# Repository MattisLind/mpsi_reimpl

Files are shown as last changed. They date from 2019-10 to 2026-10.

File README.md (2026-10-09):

# MPSI Rev2

A new HP 9830 interface based on
[Brent Hilpert's MPSI](https://madrona.ca/e/HP9830/mpsi/index.html): a 5 V ATF1504AS
CPLD handles the bus, and an STM32F103CB serves files from a microSD card.
Two 74HCT165s capture input, separate SPI buses serve the HP link and SD,
and an SSD1306 OLED with up/down/select buttons controls operation.

MPSI Server handles paper tape, printer capture and Fast Mode cassette emulation.
Tape Controller uses an HP-resident MTAPE proxy to read/write the physical drive.
USB MSC takes exclusive ownership of SD and releases every HP output.
See [the tape analysis](requirements/07_tape_analysis.md).

The current draft includes:

- [VHDL RTL, handshake bench and container build flow](hardware/rev2/README.md).
- [STM32/CPLD package pins and tentative placement](requirements/08_pin_mapping.md).
- [Three-sheet KiCad schematic and unrouted placement](hardware/rev2/kicad/README.md),
  with the existing HP connector, USB-C protection and PA9/PA10 debug header.
- [Portable C firmware core](firmware/rev2/README.md).

Start with [requirements](requirements/README.md) and [open issues](open_issues.md).

```sh
make test
```

Requires make, a C11 compiler and either GHDL or the documented Docker image.
Tests cover bus handshakes, five interrupt choices, GP-only Controller decoding,
direct configuration updates, unbuffered data, CS-clocked flags, input capture, tape commands
and exclusive SD/MSC ownership.

The simplified ATF1504 design fits and generates JEDEC with all 29 requested pins,
JTAG and fourteen open-collector HP outputs. RTL and fitter-emitted functional
equations each pass 2,000 checks at 9, 18 and 24 MHz SPI. These are zero-delay
tests; the F103 is specified up to 18 MHz, and 9 MHz is the provisional board rate.
This remains a design draft. Timing, fitter-report accounting, electrical current/rail and power-up validation, PCB routing,
and Arduino SD/USB/UI/Controller drivers also remain open. The STM32 pin map uses
PB14/PB10 as direct 5 V tolerant inputs, subject to supply/reset constraints.

Previous files remain in `MPSIBOARD`, `hardware/pld` and `software`.
The original README is preserved in [docs/legacy_design.md](docs/legacy_design.md).

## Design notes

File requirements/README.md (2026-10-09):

# Rev2 requirements

Started 2026-10-08. This directory is the working specification for a new design;
the existing board, CUPL, Xilinx and Raspberry Pi software are historical material.
Requirement IDs remain stable as the design develops. Proposed choices can change;
unresolved decisions belong in [open_issues.md](../open_issues.md).

| Document | Contents |
| --- | --- |
| [00_sources.md](00_sources.md) | Source provenance and what has actually been established |
| [01_system.md](01_system.md) | Scope, requirements and acceptance criteria |
| [02_hardware.md](02_hardware.md) | Block diagram, electrical design, preliminary connections |
| [03_interface.md](03_interface.md) | HP bus semantics and MCU/CPLD SPI contract |
| [04_firmware.md](04_firmware.md) | SD ownership, cassette engine, UI and board integration |
| [05_verification.md](05_verification.md) | Running the tests and remaining physical validation |
| [06_existing_connector.md](06_existing_connector.md) | Existing KiCad J1 pad/net assignments, sides and geometry |
| [07_tape_analysis.md](07_tape_analysis.md) | Server/Controller roles, per-file headers, supplied images and HP BOF versus TAP file marks |
| [08_pin_mapping.md](08_pin_mapping.md) | MCU/CPLD package pins, FT input constraints, debug/USB circuit and tentative placement |

The current implementation is a VHDL functional prototype with a three-sheet
KiCad draft and unrouted placement. The simplified CPLD fits with fixed pins and
generates JEDEC; RTL and fitter-emitted functional equations pass the handshake
bench. Timing, fitter-report accounting, electrical and PCB sign-off and STM32
target firmware remain open.

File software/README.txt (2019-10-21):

pgm9830 README		2014 May / bhilpert
===========================================

The pgm9830 file structure includes the source to produce 3 executables and 1 tape image file:

	tp9830		- Tape image manipulation and control for the 9830 internal tape drive
			  via the MPSI I/O server.
			  For use, see help command when running, or tp9830/helpdoc.txt.

	tp9865		- Tape image manipulation and control for the 9865 tape drive
			  via the 9865 I/O adapter.
			  For use, see help command when running, or tp9830/helpdoc.txt.

	mpsiServer	- cassette-tape/printer/paper-tape-reader server for use with
			  MPSI I/O device.
			  For use, see comment in mpsiServer/main.c

	machine.t98	- A tape image with the machine support binary block
			  and blockscan BASIC program.

Subdirectories:
	tp9830		- source for the tp9830 & tp9865 programs.

	mpsiServer	- source for the mpsiServer program.

	util		- source for a few C utility modules.

	machine		- source and tape files to produce the machine.t98 tape image.

These sources are currently targeted primarily for compilation on an RPi, although the tp9830/65 programs
may be compiled on other suitable unix systems using:
	'make mode=standalone'
to produce a program without the tape control but still provides for tape image manipulation.

The machine.t98 may also be produced on other unix systems. Assembly requires the asm9830 assembler.

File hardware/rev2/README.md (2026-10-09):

# Rev2 CPLD and board draft

[rtl/mpsi_cpld.vhdl](rtl/mpsi_cpld.vhdl) is the authoritative VHDL-2008 RTL.
[tb/tb_mpsi.vhdl](tb/tb_mpsi.vhdl) exercises General/Fast Mode, interrupt gating,
Controller decoder selection, direct SPI updates, CS flag strobes, input capture and MSC release.
[tb/hct165_pair.vhdl](tb/hct165_pair.vhdl) models the two external input registers.
The bench passes 2,000 checks at each of 9, 18 and 24 MHz SPI, with a 24 MHz,
one-third-duty-cycle capture clock. Only 9 MHz is the provisional board setting;
24 MHz exceeds the STM32F103's specified SPI limit. See issue 028.

The [pin map](../../requirements/08_pin_mapping.md) describes both packages,
direct STM32 FT inputs, USART1 debug header and tentative placement.
[kicad/MPSI_REV2.kicad_pro](kicad/MPSI_REV2.kicad_pro) opens the three-sheet
schematic and unrouted board. The local libraries preserve the existing HP
connector and the paper-tape project's USB-C footprint.

Read [the interface contract](../../requirements/03_interface.md) before writing
a driver. Configuration shifts directly with CFG_FRAME high, which blanks HP
service; it needs no COMMIT. STM32 SPI supplies sixteen clocks, without hardware
length checking. Data/status drive the HP gates directly. CS low clears REQUEST_n
and inhibits HCT165 loading; CS rising loads ACK/CFI/SSI after the data settles.
There is no separate COMMIT, output latch bank, unread-word lock or overrun monitor.
Firmware updates only during the HP handshake's safe interval and queues every
qualified received request. Address zero
disables the corresponding decoder; Controller GP8/TP-off uses word 0x0608.

Run from the project root:

```sh
git submodule update --init --recursive
python3 scripts/rev2_hdl.py build-image
make test
python3 scripts/rev2_hdl.py fit
python3 scripts/rev2_hdl.py postfit
```

The private SSH tool submodule is now at the intended path
`hardware/rev2/rtl/atf15xx-yosys-docker`, pinned to
`95e46e5f11254cc865614a9dc12fddb522a32f55`.
Its previously nested location has been corrected with `git mv`; commit the
staged `.gitmodules` and gitlink move together with the desired project changes.
No commit has been made here. Another checkout needs SSH access to the private
repository.

If local GHDL is installed, `make test` uses it. Otherwise it uses Docker. A
smaller simulation-only image is available with
`python3 scripts/rev2_hdl.py build-sim-image`; this is used when the full image
has not been built. Docker commands run without interactive terminal flags.
The wrapper locates Docker Desktop on macOS when its CLI is absent from PATH.

The synthesis flow retains DECPROMEM's inline `--PIN:` constraints. Four JTAG
constraints are included because the fitter writes them back into its pin file.
`-preassign keep` prevents silent reassignment. All fourteen HP pins are configured
open collector, pin keepers are off, and JTAG remains on. A build-local liberty
copy corrects the upstream TRI enable-name mismatch (`EN` versus Atmel's `ENA`);
the tool submodule is unchanged. `check -assert` rejects broken synthesized nets.

**The simplified implementation fits ATF1504 and generates JEDEC.** It has 36
register bits: data shift 16, configuration 12, flags 3, request synchronization 3
and capture pulse control 2. All 29 logical pins are retained; CS uses global
clock pin 41, formerly COMMIT. PB0/PB11 and CPLD pins 34/39/40 are now spare.
ATF1502 has only
32 registers and cannot hold this version either.

Logs, EDIF, JEDEC and the fitter's VHO/SDF go to `build/rev2/vhdl/fit`; RTL waveforms
go to `build/rev2/vhdl/mpsi-{rate}.vcd`. Stale fitted outputs are removed before synthesis, and
a successful fit must pass the package-pin check before being accepted.
`postfit` translates the fitter-emitted gates/flip-flops into functional VHDL and
runs the same bench: all 2,000 checks pass at each rate. It does not substitute RTL,
apply the SDF, prove timing or independently decode JEDEC fuses. The translation
rejects unsupported primitive types and checks the register count.

The fitter declares a fit but reports inconsistent resource totals (65/64
macrocells and Block D 17/16); issue 029 records this for review. Functional
fitted-equation tests pass, but report/fuse verification and physical
timing/current/rail validation remain before hardware sign-off.

For fitter-strategy iterations, use `python3 scripts/rev2_hdl.py fit --fit-options='...'`.
Requested package pins are still checked before accepting an image.

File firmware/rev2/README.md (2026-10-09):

# Rev2 portable firmware core

```sh
make -C firmware/rev2 test
```

`mpsi_protocol.h` defines the SPI payload and captured request layout.
`mpsi_storage.c` implements FAT/MSC ownership and General Mode file-byte operations.
`mpsi_tape.c` implements the initial cassette-command engine against a bounded
random-access cell cache interface.

These are server functions. The distinct Tape Controller application, using the
HP-resident MTAPE proxy for physical cassette access, is specified in
[the tape analysis](../../requirements/07_tape_analysis.md) and is not implemented yet.

See [the integration contract](../../requirements/04_firmware.md). Callbacks have
a host-test implementation only. There is no flashable Arduino STM32 image,
SdFat driver, USB stack, input queue, OLED driver, TAP backend or image converter
in this delivery.
Supply every required callback before init and serialize calls as specified.
A FAULT needs explicit board recovery; do not reinitialize while USB owns the card.

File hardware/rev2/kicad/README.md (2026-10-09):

# KiCad draft

Open [MPSI_REV2.kicad_pro](MPSI_REV2.kicad_pro) in KiCad 10.

The root sheet contains the copied HP connector, ATF1504AS-10JU44, two 74HCT165s,
JTAG and reset/control pulls. The MCU sheet contains STM32F103CBT6, microSD with
card detection, OLED/buttons, USART1 debug, SWD, boot jumper and 8 MHz crystal.
The USB/power sheet copies the paper-tape project's USB-C/USBLC6 circuit and
Schottky source isolation, with TLV75533 3.3 V regulation.

The 64-footprint board is an **unrouted placement draft**. Its HP connector and
Edge.Cuts use the current legacy board. All fifty connector pad positions,
sizes, angles and layers are checked against that board when regenerated.
The CPLD and HCT165s sit beside the HP edge connector; MCU is to their right,
with SD/UI/debug/USB towards the other edges. Mechanical fit and routing remain
to be reviewed. The simplified CPLD fits with the requested package pins, including
CS moved to GCLK3 pin 41. COMMIT/overrun wiring is removed; PB0/PB11 and CPLD
34/39/40 are spare. Electrical/timing validation and routing remain open.

The project embeds symbols and supplies portable `Rev2.kicad_sym` and
`Rev2.pretty` libraries. The connector library is extracted from
`MPSIBOARD/MPSIBOARD.kicad_pcb`; board-file pad angles are normalized to library
angles without changing pad geometry. USB-C symbol/footprint and circuit values
come from [the paper-tape project](https://github.com/MattisLind/hp21xx_papertape_emulator/tree/06787ada3dd411305c0451a057edc152249f1b82/kicad/hp21xx_papertape_emulator).
Original projects are untouched.

The schematic generator uses installed KiCad symbol libraries and local copies
of that reference schematic/PCB. Its `--reference`, `--reference-pcb` and
`--symbols` arguments allow overriding the defaults. The saved KiCad project
does not depend on those source files being installed.

```sh
python3 scripts/generate_rev2_schematic.py
kicad-cli sch export netlist --output /tmp/mpsi-rev2.net hardware/rev2/kicad/MPSI_REV2.kicad_sch
python3 scripts/check_rev2_pins.py --netlist /tmp/mpsi-rev2.net
```

For the placement generator use KiCad's bundled Python with its `pcbnew` module;
it consumes the above netlist, including explicit unconnected pin nets. On macOS:

```sh
/Applications/KiCad/KiCad.app/Contents/Frameworks/Python.framework/Versions/3.9/bin/python3.9 scripts/generate_rev2_placement.py
```

`components.json` records the schematic components/UUID paths used by that
generator; `pinmap.json` in the parent directory is the package-pin contract.
Generators overwrite these draft files, so update generator source alongside
manual schematic changes if regeneration is needed.

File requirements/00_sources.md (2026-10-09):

# Sources and evidence

Reviewed 2026-10-08; package pins, USB circuit and VHDL tools updated 2026-10-09. No numerical HP bus timing limits are inferred from the test
bench. Simulation delays are engineering assumptions pending measurement.

| ID | Source | Use |
| --- | --- | --- |
| S01 | [Brent Hilpert: MPSI](https://madrona.ca/e/HP9830/mpsi/index.html#technical) | Device selection, serial registers, status/data gating and flag resets |
| S02 | [HP 9830 machine architecture](https://madrona.ca/e/HP9830/machine.html#sc) | General Mode (the requested standard mode) and Fast Mode transaction sequences |
| S03 | [MPSI schematic, revision 1.2](https://madrona.ca/e/HP9830/mpsi/mpsiSchematic.pdf) | Capture monostable, open-collector outputs, ACK correction and original connector |
| S04 | [HP 9830 hardware architecture](https://madrona.ca/e/HP9830/hardware.html) | 8 MHz MCK and physical tape/control-byte model |
| S05 | [HP 9830 redrawn schematic](https://madrona.ca/e/HP9830/hp9830Schematic.pdf) | F3, PDF page 19: DI/SI/CFI/SSI pull-ups; F2: register and CEO logic |
| S06 | [ATF1504AS(L) datasheet, 0950P, March 2014](https://ww1.microchip.com/downloads/en/DeviceDoc/Atmel-0950-CPLD-ATF1504AS(L)-Datasheet.pdf) | Open-collector option, 64 macrocells, clock resources, DC and package constraints |
| S07 | [Microchip ATF1502AS](https://www.microchip.com/en-us/product/ATF1502AS) | 5 V, 32-macrocell alternative |
| S08 | [ST STM32F103x8/xB datasheet, DS5319](https://www.st.com/resource/en/datasheet/stm32f103c8.pdf) | Rev 20, July 2025: LQFP48 pins, FT inputs, pull restrictions and supply-dependent voltage limits; PB14 SPI2 MISO is FT and is used for HP; PA6 is not FT and is used for 3.3 V SD |
| S09 | [Nexperia 74HC/HCT165, revision 8](https://assets.nexperia.com/documents/data-sheet/74HC_HCT165.pdf) | HCT thresholds, asynchronous parallel load and shift clock |
| S10 | [TI SN74LVC1G125](https://www.ti.com/product/SN74LVC1G125) | Earlier input-translator candidate, superseded by tentative direct FT inputs; retain as a fallback if issue 026 requires isolation |
| S11 | [Existing server](../software/mpsiServer/tp.c), [paper tape](../software/mpsiServer/ptr.c), [tape format](../software/tp9830/tpf.c) | Repository copy of Hilpert's published support software; cassette commands and empirical timing caveats |
| S12 | Tony Duell's HP 9830 schematic, as reported by the user on 2026-10-08; drawing/page reference not supplied | 1 kOhm pull-ups on DI, SI, CFI and SSI; accepted design input |
| S13 | [ST RM0008 reference manual](https://www.st.com/resource/en/reference_manual/cd00171190-stm32f101xx-stm32f102xx-stm32f103xx-stm32f105xx-and-stm32f107xx-advanced-arm-based-32Bit-mcus-stmicroelect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) | Section 7.2.10 MCO choices and chapter 14 TIM1 PWM/counter configuration |
| S14 | [DECPROMEM VHDL build notes](https://github.com/MattisLind/DECPROMEM/blob/63c2cc10e1795c9c593e9b0065bb4efebdc5d622/vhdl/README.md); local atf15xx-yosys-docker checkout under /Users/mattis_lind/DECPROMEM/vhdl | Inline --PIN convention and GHDL/Yosys/Atmel-fitter flow; selected tool container now built/executed under S21 |
| S15 | [HP21xx firmware](https://github.com/MattisLind/hp21xx_papertape_emulator/blob/06787ada3dd411305c0451a057edc152249f1b82/src/hp21xx_papertape_emulator/hp21xx_papertape_emulator.ino), [README](https://github.com/MattisLind/hp21xx_papertape_emulator/blob/06787ada3dd411305c0451a057edc152249f1b82/README.md), [schematic](https://github.com/MattisLind/hp21xx_papertape_emulator/blob/06787ada3dd411305c0451a057edc152249f1b82/kicad/hp21xx_papertape_emulator/hp21xx_papertape_emulator.kicad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) | Arduino_Core_STM32/SdFat/TinyUSB/UI reference; exact USB-C symbol/footprint, USBLC6-2SC6, 22 Ohm/CC/pull-up/VBUS-divider circuit and diode/regulator source reused; reference firmware not built |
| S16 | [SIMH magtape representation](https://simh.trailing-edge.com/docs/simh_magtape.pdf), Bob Supnik, 2022-01-17 | TAP record lengths, padding, trailer, tape marks and standard/extended distinction |
| S17 | [Existing KiCad PCB](../MPSIBOARD/MPSIBOARD.kicad_pcb), [current schematic](../MPSIBOARD/MPSIBOARD.kicad_sch) | J1 embedded pad/net assignments, sides, pitch and outline; extracted in 06_existing_connector.md |
| S18 | [Hilpert's XNS format](https://madrona.ca/e/xns.html), [local image decoder](../software/util/util.c), [local tape server](../software/mpsiServer/tp.c) | Confirm that the supplied .t98/server path uses XNS and preserves control-marked cells |
| S19 | [Published support archive](https://madrona.ca/e/HP9830/pgm9830.tgz), downloaded 2026-10-08; digest in 07_tape_analysis.md | Contains one .t98 and two substantive .f98 images; all three and five inspected source/documentation files match the local copies |
| S20 | [Tape controller reader/writer](../software/tp9830/t98_mpsi.c), [format routines](../software/tp9830/tpf.c), [format offsets](../software/tp9830/tpf.h), [MTAPE proxy](../software/machine/mbb.s), [user documentation](../software/tp9830/helpdoc.txt) | Physical capture loses BOF control flags; buffered writer segments, GP directives, checksums and EOT-placeholder convention |
| S21 | [User's private atf15xx-yosys-docker repository](https://github.com/MattisLind/atf15xx-yosys-docker), selected 2026-10-09 | SSH submodule at the corrected path, pinned to 95e46e5f11254cc865614a9dc12fddb522a32f55. Built container synthesizes/fits the simplified 36-register design, retains 29 pins/JTAG/open-collector outputs and generates JEDEC. RTL and fitter-emitted functional equations pass 2,000 checks per SPI rate at 9/18/24 MHz; timing/fuse validation and report accounting remain open |

S05 is a reverse-engineered drawing, not HP's manufacturer schematic. Its F3
sheet shows fourteen pull-ups for twelve input bits plus CFI and SSI, but the
resistance text is just `K`. The user's S12 information establishes 1 kOhm for
all DI/SI/CFI/SSI lines; use that value for the design. Full receiver/capacitive
loads remain electrical verification work in issue 002. The unrelated 2.2 kOhm
resistors are not the evidence.

S06's DC table (PDF page 11) specifies VOL <= 0.45 V at IOL = 12 mA. The user's
24 mA assumption is therefore unverified for this part. Neither an absolute
maximum nor an AC drive-current plot establishes a guaranteed DC sink rating.
Recheck the current datasheet of the exact ordered variant before sign-off.

S01 and S03 inform the bus logic; S02 supplies transaction-level stimulus. S11
supports the initial tape-command core, including commands 6/7 as continuation.
The unusual read-forward delay in that implementation is an empirical observation,
not a bus specification and not yet implemented in the new firmware.

The user identified five interrupt choices in S03: nDI0, nDI7, nSI0, nSI1 and nSI2.
This supersedes the first draft's provisional eight-line lookup. VHDL and the portable configuration helper now implement those five lines;
the bench verifies reserved-code silence and reference status/ID combination.
Review of S01/S03 also resolves issue 015: preserve the reference's normal bus
gating and add the interrupt ID sink; do not globally replace status/data with
only the ID bit as the first Rev2 prototype did.

S04 explicitly names BOF as Beginning-of-File control-0x3C; S20 and the supplied
image show its XNS value 0x083C and the per-file 12-word header. The initial
BOF-to-TAP-mark experiment, documented in [07_tape_analysis.md](07_tape_analysis.md),
preserves all cells but changes conventional logical-file boundaries by treating
initial padding as a file. The user's correction distinguishes HP BOF from TAP
file-terminating marks; the production mapping is reopened in issue 009.
Experimental cell round trips and BOF recovery are verified on the one supplied
cassette image, not on additional tapes or hardware. The user's clarified scope
also requires a Tape Controller application, absent from the current core.

The built S21 image is sha256:ae26dbf975c8b88f82b73c99cd7dbde4705eb6e9bfc52ec7784e4114d821d461.
Its synthesis tools report Yosys 0.55+144 (6440499e5), GHDL LLVM
6.0.0-dev (5.1.1.r30.g69b0c75d7.dirty), Atmel fit1504 version 1918 (2007-03-21),
and atf15xx_yosys commit bd547977661bc7de08872df61108b229c6d78976.
The image also contains a separately built GCC-backend GHDL 7.0.0-dev;
the wrapper PATH selects the OSS CAD LLVM version. The pinned Dockerfile still
fetches moving GHDL/tool sources, so pinning the submodule alone does not pin all
build inputs; record the image digest/versions when comparing fitter iterations.
The local synthesis wrapper aligns the liberty TRI port to aprim.lib's ENA,
leaving the submodule untouched. The uncorrected EN/ENA flow discarded useful
logic and produced a misleading apparent fit; that image was rejected/removed.

The current simplified design follows Hilpert's direct MSR data/status path and
separate CTL-clocked ACK/CFI/SSI flip-flops; CS rising replaces CTL's flag-loading
edge. No overrun monitor or output data buffer is added. The reference text and
local mpsi.c also show CTL low inhibiting input reload during shifting, and note
prompt response for unacknowledged Fast commands. The finite CPLD capture pulse
remains a replacement for the reference's monostable.

DS5319 Table 43 specifies 18 MHz maximum SPI frequency. Nexperia S09 specifies
HCT165 CP-to-Q7 delay, DS setup and MISO sampling timing that must be budgeted
separately from raw word duration. The 24 MHz proposal is tested only as ideal
functional stimulus; it is not a supported F103 hardware setting.

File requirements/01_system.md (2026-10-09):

# System requirements

| ID | Requirement | Acceptance |
| --- | --- | --- |
| SYS-001 | Start a separate Rev2 design using a 5 V ATF1502AS or ATF1504AS CPLD and an STM32F103 MCU. | Existing design remains available; Rev2 has its own source and tests. |
| SYS-002 | Provide independently programmable four-bit GP and TP select codes, optional SC15 printer service, and a three-bit selector for nDI0, nDI7, nSI0, nSI1 or nSI2. | Test all supported selections and reserved-code behaviour, then validate on HP. |
| SYS-003 | Support General/standard Mode stream input/output and Fast Mode 9865 cassette operations. | Protocol simulation, followed by PTAPE/LIST/LOAD/STORE/TLIST hardware trials. |
| SYS-004 | Use two cascaded 74HCT165s to capture sixteen HP output bits and read them through SPI. | One finite capture pulse per request; no loading while an unread request is shifted. |
| SYS-005 | Shift outgoing data/status into the CPLD and gate them onto the HP bus. | Bus sees valid data before ready flags; all driven pins are low or released. |
| SYS-006 | Supply selected SD files to the HP and save incoming data to SD. | Real SD file round trips, checksums and error handling; portable byte/tape core first. |
| SYS-007 | Offer USB MSC access to the entire SD card while HP file service is disabled. | Exclusive card ownership and flush/unmount/remount sequence tested. |
| SYS-008 | Use a 128x64 SSD1306-compatible I2C OLED and three buttons: up, down, select. | File selection, settings, service state and MSC handover work without a host terminal. |
| SYS-009 | Keep requirements here and issues in a root document with exactly four columns. | Stable issue numbers; status is `open` or `closed`; response records the resolution. |
| SYS-010 | Provide synthesizable VHDL and a reproducible test bench based on the referenced HP documentation. Use the user's GHDL/Yosys/Atmel-fitter container to produce JEDEC. | GHDL simulation passes; ATF1504 fitting, pin assignment, timing report and JEDEC generation follow. |
| SYS-011 | Provide mutually exclusive MPSI Server, Tape Controller and USB MSC roles. Server supplies/captures SD files; Controller uses an HP-resident proxy to read/write the physical cassette; MSC releases every HP output and disables both HP roles. | Mode/dispatcher tests, physical proxy/cassette trials and exclusive SD ownership checks. |

Prototype choices: ATF1504AS in a 44-pin package and STM32F103CBT6 in LQFP48.
The simplified VHDL RTL has 36 register bits, exceeding an
ATF1502's 32-register capacity.
An ATF1502 version requires a different register architecture or more external
logic. The corrected fitter now declares a fit and emits JEDEC with all requested
pins retained. RTL and fitter-emitted functional equations pass the handshake
bench. Timing and the fitter's inconsistent resource totals remain in 005/028/029.

Default proposal: GP=8, TP=9, printer disabled until explicitly enabled, interrupt
selector=3 (nSI1/DI9 under the revised mapping). The VHDL bench exercises this mapping and the printer-enabled configuration.
Zero disables a decoder without responding to SC0; firmware rejects SC10,
duplicate nonzero GP/TP addresses and overlap with enabled SC15. Other attached devices can occupy additional codes; these
must be checked by the user when configuring the actual installation.

First delivery: documented architecture, executable bus RTL/test bench, and a
portable C core. A three-sheet schematic and unrouted placement now exist; target drivers,
OLED implementation, SD/SdFat,
USB stack, image import, the Tape Controller/proxy frontend and validation on
an HP are subsequent milestones. The current core implements server functions;
its SERVING storage state does not distinguish the two required HP roles yet.

The two non-MSC roles are different applications over the same interface.
Controller mode keeps GP available for directives/replies, disables TP/printer
emulation, and leaves the HP proxy to access the real internal drive at SC10.
MSC leaves the CPLD powered/clocked but logically disconnects it from the HP by
releasing all outputs and disabling HP handlers. See [the tape analysis](07_tape_analysis.md).

Accepted user decisions, 2026-10-08: DI/SI/CFI/SSI pull-ups are 1 kOhm; the operator is
responsible for avoiding MSC during HP use; HP bus power and USB VBUS each feed
the board through a Schottky diode; an SD card-detect input is required; recovery
from protocol failure uses an operator restart rather than additional recovery
protocols, with USB unplugged during the full power cycle. Generate 24 MHz on
PA8 TIM1_CH1; timing validation remains open. Use Arduino_Core_STM32 with SdFat,
reuse the user's GHDL/Yosys/Atmel-fitter flow, store name/value configuration on
FAT and automatically rescan an inserted SD card. Use SIMH TAP as the cassette
container. HP BOF starts a file; a TAP mark conventionally terminates/separates
files. The earlier raw-cell substitution round-trips the sample but does not
establish the production logical-file mapping. Finalize file/record grouping
and padding preservation in issue 009; target backend, physical operations and
additional-media validation remain open. In MSC keep
the CPLD clocked with RESET_n released and HP_RUN low.

Accepted user decision, 2026-10-09: use VHDL for Rev2 RTL and add the private
`MattisLind/atf15xx-yosys-docker` repository as a Git submodule at
`hardware/rev2/rtl/atf15xx-yosys-docker`. Use SSH for repository access. The
submodule is present at the corrected path, the VHDL port and GHDL bench pass,
and the Docker image builds. The simplified design now fits with retained JTAG
and open-collector HP outputs; issue 004 records the image-generation result.

Additional decisions, 2026-10-09: use powered-state FT STM32 inputs directly
for 5 V MISO/request, reserve PA9/PA10 USART1 on a four-pin debug header,
reuse the current HP connector symbol/footprint, place CPLD/HCT165s beside it,
and copy the paper-tape project's USB-C/protection circuit. The package map
and startup constraints are recorded in 08_pin_mapping.md; unresolved electrical
and physical validation is recorded in issues 026/027.

RTL simplification agreed 2026-10-09: trust STM32 hardware to shift sixteen bits;
remove bit counting/frame-valid checks, the response latch bank, separate COMMIT,
unread-word protection and overrun logic. Shift config with HP selection masked
by CFG_FRAME. Data/status come directly from the shift register. Retain Hilpert's
three flag flip-flops, using CS rising for the CTL end-of-transfer function.
Firmware schedules SPI around HP busy/ready handshaking. The proposed 24 MHz SPI
exceeds the F103's 18 MHz specification; start at 9 MHz pending timing work in 028.

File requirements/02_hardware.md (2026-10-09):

# Proposed hardware

```mermaid
flowchart LR
    HP[HP 9830 bus] -->|CO, CEO, SIH| CPLD[ATF1504AS at 5 V]
    HP -->|CO, SO, DO: 16 bits| SR[2 x 74HCT165 at 5 V]
    CPLD -->|PL capture pulse| SR
    MCU[STM32F103CB at 3.3 V] -->|SPI2 MOSI/SCK, CS, CFG| CPLD
    MCU -->|PA8 TIM1 capture clock: 24 MHz| CPLD
    MCU -->|SPI2 SCK| SR
    SR -->|Q7: direct FT input PB14| MCU
    CPLD -->|Request PB10: FT input| MCU
    CPLD -->|DI/SI, CFI, SSI: open collector| HP
    MCU <-->|SPI1| SD[microSD at 3.3 V]
    MCU <-->|USB FS MSC| USB[USB-C with USBLC6 protection]
    MCU -->|I2C| OLED[SSD1306 128x64]
    BTN[Up, down, select] --> MCU
```

| ID | Hardware requirement |
| --- | --- |
| HW-001 | Use the 5 V **AS** family. Do not substitute a low-voltage family on the assumption that it has the same electrical interface. |
| HW-002 | HP-facing DI0..7, SI0..3, CFI and SSI shall only sink current or release. Disable pin keepers and pull-ups on these CPLD pins. |
| HW-003 | Validate per-pin VOL/current, total simultaneous sink current, ground-current limits, thermal load and release rise time before direct connection. |
| HW-004 | Account for combined CPLD + HCT165 loading on CO; all circuitry on each HP output shall remain within the reference's one standard TTL input load constraint. |
| HW-005 | Run the 74HCT165 pair from 5 V. Use PB14/PB10 FT inputs directly for MISO/request, subject to the powered-supply/reset checks in issue 026. Disable their internal pulls. MCU outputs may drive TTL-threshold inputs if worst-case margins pass. |
| HW-006 | Separate SPI2 (HP link) from SPI1 (SD). Never clock the HP input chain for SD transactions. |
| HW-007 | Provide a continuous 24 MHz PA8 TIM1_CH1 capture clock, hardware reset, default-low HP_RUN, CPLD JTAG and MCU SWD access. Hold the CPLD reset until its clock is stable at startup; keep the clock running and RESET_n released during MSC. |
| HW-008 | Prevent USB VBUS from feeding the HP 5 V rail and prevent an unpowered MCU/CPLD from being back-powered through signals. |
| HW-009 | Reuse J1 assignments, pad sides and geometry from the current KiCad schematic/PCB, as extracted in 06_existing_connector.md. Keep the older .sch numbering separate; check physical fit/orientation before production. |
| HW-010 | Feed the board from HP bus power and USB VBUS through one Schottky diode per source, with common cathodes. Verify rail headroom and peak-current capability after the diode drop. |
| HW-011 | Use an SD socket with active-low card detect on PB4; debounce in firmware. |
| HW-012 | Reserve PA9/PA10 for USART1 debug; provide J5 ordered +3.3 V, TX, RX, GND. |
| HW-013 | Place CPLD/HCT165s beside the HP connector and reuse its current symbol/footprint; start an unrouted placement for routing review. |
| HW-014 | Use DECPROMEM-style inline VHDL pin constraints, fixed preassignment, retained JTAG and a pin/net cross-check. |
| HW-015 | Use USB-C and the source S15 USBLC6 protection circuit, including separate CC pull-downs. |

The CPLD uses 29 logical signal pins: six HP inputs plus the capture clock, reset and
HP_RUN, four SPI/control inputs, two MCU/input-register outputs, and fourteen
HP outputs. The capture clock, SPI SCK and CS flag strobe use the three global clock resources.
The 44-pin device has 36 signal positions including four dedicated input positions;
retaining four JTAG pins leaves 32 for the design. The simplified implementation
fits with all 29 pins retained; the inline map, schematic and PCB agree. Fitter
resource-accounting review remains in 029, and physical timing/electrical checks
remain necessary before manufacture.

The user chooses 24 MHz from STM32 PA8, replacing the HP MCK clock proposal.
According to [RM0008](https://www.st.com/resource/en/reference_manual/cd00171190-stm32f101xx-stm32f102xx-stm32f103xx-stm32f105xx-and-stm32f107xx-advanced-arm-based-32Bit-mcus-stmicroelect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),
MCO selects PLL/2 rather than an arbitrary divisor: a 72 MHz PLL gives 36 MHz.
Use PA8's TIM1_CH1 PWM with a 72 MHz timer clock, PSC=0, ARR=2 and CCR1=1.
The derived period is 41.7 ns, HIGH is 13.9 ns and LOW is 27.8 ns: the approximately
40 ns figure is a period, not a HIGH pulse. Check those pulse widths against the
chosen CPLD. Keep the timer running during service and MSC. The VHDL bench now uses this
24 MHz waveform and checks the two-cycle PL pulse; issue 005 retains physical
clock/capture timing and reset-recovery validation.

The HCT165s still use SPI2 SCK for shifting; PA8 clocks the CPLD capture logic.
With the two load states, PL LOW is nominally 83.3 ns. Nexperia's
S09 HCT table specifies minimum PL LOW of 30 ns and Dn-to-PL setup of 30 ns at
4.5 V across -40..125 C, so shortening the clock alone does not establish HP
data-hold compatibility. Check actual input stability, PL-to-shift recovery and
direct-input and CPLD delays. The continuous clock and PL are different signals.

HCT165 wiring: lower chip D0..D7 = DO0..DO7, upper chip D0..D3 = SO0..SO3,
upper D4..D7 = CO0..CO3. Lower Q7 goes to upper DS; lower DS is grounded.
Upper **non-inverting** Q7 feeds PB14 directly. Both clock-enable pins
are low, CP uses SPI2 SCK, and both PL pins share the CPLD's input_pl_n pulse.
Capturing the actual select code saves three CPLD pins otherwise needed to put
device-identification signals into the input register. nGP/nTP/nPR exist internally.

The [package pin map](08_pin_mapping.md) assigns HP SPI2 to PB13/PB14/PB15
and PB12 CS, with PB14 as the direct FT MISO input. SD instead uses SPI1 on
PA5/PA6/PA7 and PA4 CS, entirely at 3.3 V. This avoids the reset-state JNTRST
pull-up on the earlier PB4 HP-MISO proposal. PB10 is the FT request input;
PB0/PB11 are now spare after removing COMMIT and overrun.
Reserve PA9/PA10 for USART1 on J5 (+3.3 V, TX, RX, GND); PA3 receives divided
VBUS sense and PB5 controls the external USB pull-up. Card detect uses PB4
at 3.3 V; disable JTAG while retaining SWD. No SPI remap is required.
The complete LQFP48/PLCC44 tables and initialization requirements are in
08_pin_mapping.md.

Direct FT wiring is provisional during power-up/reset: FT voltage limits depend
on VDD, internal pulls must be disabled above VDD+0.3 V, and powered-state tolerance does not establish power-off compatibility. Issue 026 checks rail ramps, reset and fault conditions,
including the VBUS divider. Add isolation if this cannot be made safe; the
powered-state FT rating alone does not establish power-off compatibility.

The three-sheet KiCad draft reuses the current HP connector symbol and embedded
footprint. CPLD and HCT165s sit beside the connector; MCU is to their right.
USB-C reuses the HRO-TYPE-C-31-M-12 connector and USBLC6-2SC6 protection from
source S15, including 22 Ohm data resistors, two 5.1 kOhm CC resistors,
1.5 kOhm switched D+ pull-up and the 1.8 kOhm / 3.3 kOhm VBUS divider.
An additional 10 kOhm pull-down defaults the PB5-controlled USB pull-up off.
USBLC6 connects to raw VBUS. See [the KiCad notes](../hardware/rev2/kicad/README.md).

The CB medium-density part has no SDIO; use SPI for SD. Its stated RAM is 20 KiB
and flash 128 KiB. Capacity must be verified with the real Arduino/SdFat/USB/UI build.
MCU pin functions are based on [ST's datasheet](00_sources.md#sources-and-evidence)
and must be checked again when the package and schematic are fixed.

For each HP input line calculate:

`I_sink = (V_pullup_max - VOL_target) / R_pullup_min + sum(receiver IIL_max)`.

Use the user's 1 kOhm DI/SI/CFI/SSI value from Tony Duell's schematic. At nominal 5 V it
contributes roughly 5 mA per line before receiver loading; add tolerances and
simultaneous sinks. Fourteen nominal pull-ups contribute approximately 70 mA if
all lines sink together, before receiver loading. Verify VOL and rise time
under actual loading. External bus drivers are needed only if direct drive fails.

The two Schottky input diodes are an accepted power-source choice. The supply
budget must include their forward drop. The reviewed
[CPLD datasheet](https://ww1.microchip.com/downloads/en/DeviceDoc/Atmel-0950-CPLD-ATF1504AS(L)-Datasheet.pdf)
specifies minimum 4.75 V for commercial or 4.50 V for industrial operation.
The user requires the CPLD to remain powered without asserting RESET_n during
MSC; HP_RUN stays low to release every HP output and clear pending flags/requests.
Keep TIM1 running. Issue 022 therefore requires the rail budget to pass in both
power modes; the MCU's 3.3 V supply needs its own regulator budget.

The HP21xx reference schematic S15 specifies 1N5819WS power diodes and a
TLV75533 3.3 V regulator. Reusing its source-isolation topology does not establish
the margin for this CPLD: as an illustrative calculation, 5.0 V minus a 0.3 V
forward drop is 4.7 V, below the commercial CPLD minimum. The example drop is not
a measured or guaranteed value for the reference diode. The draft chooses the industrial ATF1504AS-10JU44; validate its margin and
the diode from a budget using minimum source voltage and worst-case forward
drop at the actual load/temperature. A larger current rating alone is insufficient.

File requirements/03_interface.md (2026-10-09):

# HP bus and SPI interface

| ID | Requirement |
| --- | --- |
| BUS-001 | Decode CO[3:0] as the actual select-code value. GP and printer use General Mode; TP uses Fast Mode. |
| BUS-002 | In General Mode, SO3=1 means input to HP; SO3=0 means output from HP. CEO clears SI0/ACK while asserted; firmware restores ACK after completion. |
| BUS-003 | In Fast Mode, keep CEO asserted until data is ready and CFI acknowledges; release CFI when CEO deasserts. |
| BUS-004 | General status is visible when selected; General data is visible when selected and nSIH=0. Fast status is visible when selected and CEO inactive; Fast data is visible when selected and CEO active. |
| BUS-005 | An SSI flag drives nSSI and a selected identifying bit only when nSIH=1. Device enable clears SSI. |
| BUS-006 | Preserve ACK during TP operations and restore it on tape responses. Reset and HP_RUN=0 release all HP outputs. |
| BUS-008 | Restrict interrupt selection to nDI0, nDI7, nSI0, nSI1 and nSI2. Reserved selector codes assert neither SSI nor an identifying bit. |
| BUS-007 | Generate one finite HCT165 load pulse per selected CEO assertion, then assert REQUEST_n. CS low clears REQUEST_n and inhibits input loading during SPI. Rely on prompt firmware service and HP handshaking; no unread-word protection or hardware overrun monitor. |
| BUS-009 | Enable only the GP relay interface in Tape Controller mode; disable TP and printer emulation. In MSC release all HP outputs. Use select code zero to disable GP or TP independently; it shall never decode HP SC0. Controller sets TP=0 and printer off. |
| SPI-001 | Use MSB-first, 16-bit, full-duplex SPI mode 2 (CPOL=1, CPHA=0). HCT165 and CPLD shift on the trailing rising edge. |
| SPI-002 | Drive data/status directly from the output shift register. Shift only when the HP handshake permits changing them. Load ACK/CFI/SSI flip-flops on CS rising after the final SPI edge and data-settling guard; do not add an output buffer or separate COMMIT. |
| SPI-003 | Shift configuration directly into its register, without COMMIT. CFG_FRAME=1 disables HP selection, outputs and capture throughout the update. Firmware normally holds HP_RUN=0 and validates configuration before resuming service. |
| SPI-004 | Trust STM32 hardware to exchange sixteen bits per transaction. Do not add CPLD bit counting, frame-valid state or frame-length rejection. The proposed 24 MHz SPI rate exceeds the F103's specified 18 MHz limit; establish a rate meeting MCU, HCT165 and CPLD timing in issue 028. |

BUS-002/003 follow [S02](https://madrona.ca/e/HP9830/machine.html#sc);
BUS-004/005/006 follow the circuit policy in
[S01](https://madrona.ca/e/HP9830/mpsi/index.html#technical).
Issue 015 is resolved by following the reference circuit. Normal status and data
retain their existing gating; the interrupt ID is an additional open-collector
sink, not a global replacement for normal output. In logical active-high form:

```text
enabled = selected AND NOT nCEO
status_gate = (general_selected) OR (tape_selected AND NOT enabled)
data_gate = (general_selected AND NOT nSIH) OR (tape_selected AND enabled)
id_active = SSI_flag AND nSIH AND valid_interrupt_selector
DI_SI_sinks = normally_gated_data_status OR selected_ID_mask
```

`general_selected` includes the GP and enabled SC15 printer selections. The
selected-ID mask is zero unless `id_active`. These equations apply while reset
is released, HP_RUN is high, CFG_FRAME is low and at least one decoder is enabled;
otherwise outputs release. Configuration validation belongs to firmware.
Device enable clears the SSI flag.
Thus ordinary General data is inhibited during ID presentation by nSIH itself,
but status can still be visible when a General device is selected. When no device
is selected, only the configured ID bit is presented. The VHDL RTL and bench implement these equations, including selected General
status alongside interrupt identification. No additional bus-gating choice is
required from the user.

All values below are **logical** values. A logical 1 on HP input data/status means
pulling the corresponding `nDI`/`nSI` wire low. Captured CO/SO/DO use non-inverted
HCT165 Q7, so firmware must not apply the legacy driver's XOR inversion.

| Configuration bits (CFG_FRAME=1) | Meaning |
| --- | --- |
| 3:0 | GP select code; zero disables GP |
| 7:4 | TP select code; zero disables TP |
| 8 | SC15 printer enable |
| 11:9 | Interrupt selector |
| 15:12 | Firmware sends zero; hardware ignores these bits |

| Response bits (CFG_FRAME=0) | Meaning |
| --- | --- |
| 7:0 | Data for DI0..7 |
| 8 | Unused; SI0 comes from the ACK flip-flop |
| 11:9 | SI1..3 status |
| 12 | Unused |
| 13 | ACK request |
| 14 | CFI request |
| 15 | SSI request |

MISO's captured word is `{CO[3:0], SO[3:0], DO[7:0]}`. A separate active-low
REQUEST_n GPIO qualifies whether that word contains a request. There is no
embedded request bit. The user's schematic review establishes five interrupt
choices. Use this revised selector assignment:

| Selector | HP wire | DI bit |
| --- | --- | --- |
| 0 | nDI0 | 0 |
| 1 | nDI7 | 7 |
| 2 | nSI0 | 8 |
| 3 (default) | nSI1 | 9 |
| 4 | nSI2 | 10 |
| 5..7 | Reserved: no SSI or ID assertion | None |

The VHDL implementation uses this mapping; the portable firmware validator
accepts only 0..4. Hardware also accepts reserved selector values to allow
simulation of their required silent behaviour.

Address zero disables a decoder without consuming extra configuration bits or
registers. Default Server GP8/TP9/printer-off/IRQ3 is 0x0698; printer-on is
0x0798. Controller GP8/TP-off/printer-off/IRQ3 is 0x0608. Firmware rejects duplicate
nonzero addresses, SC10 and address overlap with an enabled printer. The CPLD
does not repeat this validation. Firmware sends reserved bits 15:12 as zero;
the configuration shift register retains only the final twelve bits.
With all three decoders disabled the interface
is unconfigured/silent, including interrupt identification. The bench checks
GP-only Controller decoding, TP-only decoding, SC0 silence and SC10 silence.
This provides hardware role gating; the firmware job dispatcher remains open.
Controller directives/replies use the GP General handshake and the full usable
12-bit word, not the virtual-tape Fast handler. The relay itself talks to internal
SC10; the CPLD must remain silent for that code. See [the protocol trace](07_tape_analysis.md).

Transaction sequence:

1. For HP service, wait for a request and PL high. Require at least one MCK period
   after REQUEST_n before SPI. Save whether REQUEST_n is low **before** lowering CS.
   During General input, ACK must remain clear until data is complete; during Fast
   input, CFI must remain clear until data is complete. Once ready is asserted,
   leave the data/status register unchanged until the next request establishes
   a new safe update interval. Initialize/configure with HP service disabled.
2. Set CFG_FRAME and take CS low. This clears REQUEST_n and inhibits HCT165 loading.
   Do not begin during PL low. Read requests with flags clear while firmware
   prepares their response; do not perform speculative idle SPI reads.
3. Exchange exactly sixteen bits. Keep MOSI stable through each rising SCK edge.
4. Stop SCK high and wait at least 125 ns (prototype data-settling guard), then
   raise CS. With CFG_FRAME low, this edge loads the three flag flip-flops from
   the final word; data/status are already present at the gates. It is Hilpert's
   CTL end-of-transfer function, with no extra GPIO or data-latch bank.
5. Leave at least 250 ns before another transaction (prototype capture-reset
   recovery guard). For configuration keep CFG_FRAME high through CS rising,
   then lower it; keep HP_RUN low until initialization is complete.
6. If REQUEST_n was active before a data transaction, queue its received word even
   when the transaction was initiated to send a response. Never silently discard it.

Data/status may change throughout SPI; the HP handshake determines when the
processor may use them. Only the three readiness/interrupt flags are separately
latched, so intermediate shift bits cannot assert ACK, CFI or SSI. One completed
response transfer supplies both data and flags; an extra data-first transfer is
not required. This follows the reference's unbuffered MSR and three CTL-clocked
flag flip-flops. Configuration needs no output latch because CFG_FRAME masks HP
service while its bits shift. There is no hardware bit counter or frame-valid check: STM32
SPI is responsible for sixteen clocks. A malformed transfer can corrupt a response
or configuration, and the shifted HCT165 input cannot be recovered by retrying.
If firmware detects a protocol failure, report it;
the operator power cycles the HP with USB unplugged, as agreed in 016/024.
Removing both supplies also resets the adapter. No CRC, readback, replay or
additional menu recovery is required for protocol faults.

The accepted 24 MHz PA8 clock gives a two-cycle PL pulse of about 83.3 ns
and a five-cycle nominal capture-close bound of about 208.3 ns from CEO,
excluding propagation and metastability. The **entire** CO/SO/DO word must
remain stable until PL closes. Require at least one further MCK period after
REQUEST_n before starting SPI. The bench checks the pulse length and that the
request follows PL closing; HP data hold and HCT165 recovery need measurement.

The capture pulse controller has four states: idle, first load cycle, second load
cycle and captured. The data word lives in the external HCT165s; there is no
additional input buffer. PL stays low for two MCK cycles, then goes high and
REQUEST_n goes low. PL comes directly from one stored state bit.
`capture_reset_n` clears this controller on reset, HP_RUN low, CFG_FRAME high or
CS low. A subsequent selected CEO edge reloads the HCT165s even if the previous
request has not been read; there is no unread-word lock or overrun flag. CS low
inhibits all loads during shifting, as Hilpert's CTL does. Firmware services the
current request promptly using the HP handshake. Physical capture/reset-release
timing remains part of issue 005.

The last MCK process uses two registers (`enable_meta`, `enable_sync`) to
synchronize the asynchronous selected CEO request and a third (`enable_prev`)
to detect one assertion. Fast Mode can hold CEO active until CFI; it must not
cause repeated captures. The process only synchronizes/detects the request; it
does not track overruns. This replaces Hilpert's analog monostable with a finite
clocked load pulse while keeping the same input-load inhibit during transfers.

The user's speed proposal is 24 MHz SPI (0.667 us per word). ST DS5319 Table 43
specifies a maximum of 18 MHz, which SPI2 can derive from 36 MHz APB1 with /2;
a /4 starting rate of 9 MHz takes 1.778 us per word and gives more HCT165 timing
margin. Use 9 MHz provisionally, then validate any increase in issue 028.
The bench exercises 9, 18 and 24 MHz with an ideal HCT165 model; passing 24 MHz
simulation does not establish that the MCU or shift registers support that rate.
The independent PA8 capture clock remains 24 MHz.

Fast Mode service should
target a response in the tens of microseconds after the request unless a confirmed
tape command requires a deliberate delay. OLED refresh and SD transactions must
not block that path. This design follows the user's decision to rely on timely
STM32 service, with no hardware overrun detector or queue. Hilpert explicitly
notes that some unacknowledged Fast Mode operations require prompt host service;
their command-specific scheduling remains in issue 007. Normal acknowledged
transfers use busy/ready handshaking, rather than a comparison of clock rates alone.

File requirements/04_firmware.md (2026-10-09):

# Firmware requirements and integration

The new [portable C core](../firmware/rev2) implements storage ownership, General
Mode file-byte operations and a bounded cassette-command engine. Its callbacks
are tested with fake filesystem/card/USB implementations. No STM32 startup code,
hardware driver, SdFat integration, USB stack or OLED renderer is included yet.

The accepted target stack is official Arduino_Core_STM32 with SdFat. Follow the
user's HP21xx emulator (S15) for board integration: its current firmware uses
Adafruit TinyUSB and U8g2, with the STM32 TinyUSB port identified in its README.
Pin compatible dependency versions when adding a reproducible Arduino build.
Use [the package pin contract](08_pin_mapping.md): use SPI2 for HP and SPI1 for SD,
disable JTAG while keeping SWD, and leave direct FT inputs without internal pulls.
Reserve USART1 PA9/PA10 for the four-pin debug header; PA3 senses divided VBUS
and PB5 controls USB attachment. Use the selected SSD1306 renderer here; the reference's SH1106 constructor is
for a different panel. The reference's SD uses SPI1, as does this design; SPI2 serves the CPLD/HCT165s.
Pass the dedicated SPI1 instance to SdFat and release PB4 from JTAG for card detect.

| ID | Requirement |
| --- | --- |
| FW-001 | Use SdFat on a dedicated SPI1 instance with FAT16/FAT32; verify flash/RAM use on the chosen F103 Arduino build. |
| FW-002 | In MPSI Server mode, General input reads the selected paper-tape file byte by byte; EOF returns NUL. General output and printer traffic append to selected capture files. |
| FW-003 | In MPSI Server mode, implement virtual-tape commands 0/1 forward read, 2/3 reverse read, 4 forward write, 5 stop, and 6/7 continuation. Preserve control markers separately from data bytes. |
| FW-004 | Buffer SD reads/writes. The HP handler shall not make blocking SD/filesystem calls. Acknowledge writes only after securing space in the write buffer. |
| FW-005 | Give exclusive card ownership to either local FAT or USB MSC. Reject file/tape calls in MSC and MSC blocks in serving mode. |
| FW-006 | Enter MSC at the operator's request: disable HP service, flush/close files and caches, sync the card, unmount FAT, then attach USB. The operator is responsible for avoiding an active HP transfer. |
| FW-007 | Leave MSC after host release and drained block requests: detach USB, remount/rescan FAT, invalidate old handles/caches, reinitialize the HP link, then serve. |
| FW-008 | Keep HP disabled on handover/file errors and report the failure. A failed unmount or USB drain must never lead to dual ownership. |
| FW-009 | Sample REQUEST_n before lowering CS and queue every qualified receive word, including transfers used to send responses. CS low clears the request. Rely on timely service/HP handshaking; no CPLD overrun signal is provided. |
| FW-010 | Prioritize HP service above SD maintenance and OLED work; refresh the OLED in short chunks. |
| FW-011 | Provide SSD1306 display and debounced up/down/select buttons for role/file selection, write protection, addresses, interrupt selection, physical-tape jobs/progress and MSC. |
| FW-012 | Card removal or media errors shall stop HP service; USB shall report errors rather than successful block operations. |
| FW-013 | Read and debounce physical card detect; invalidate file/tape state on removal. Automatically reinitialize/rescan on insertion, reread capacity and revalidate paths. Remount local FAT only when local service owns the card; in MSC update raw-media state/capacity and report media change to the host. |
| FW-014 | Keep protocol-failure recovery simple: report the fault and let the operator power cycle the HP with USB unplugged. No CRC, readback or replay mechanism is required solely for this case. |
| FW-015 | Use official Arduino_Core_STM32, SdFat and the reference's STM32-compatible TinyUSB integration; keep HP service, display and filesystem ownership transitions serialized. |
| FW-016 | Store cassette images in SIMH TAP containers using an HP-aware file mapping. Preserve cassette headers/checksums and reverse/write behaviour; finalize the mapping in issue 009 before implementing the target backend. |
| FW-017 | Store configuration as simple key=value pairs in a file on FAT. Validate addresses, interrupt selection and file paths before enabling the HP link. |
| FW-018 | Dispatch by mutually exclusive application role: MPSI Server, Tape Controller or MSC. Both HP roles may own local FAT; only Server invokes the paper/printer/virtual-tape handlers. Controller uses GP directive/reply jobs through the HP MTAPE proxy, with TP/printer emulation disabled. |
| FW-019 | Provide controller jobs for reading/writing physical cassette images/files, rewind and stop, with status/progress on the three-button UI. Stream through bounded SD buffers; preserve the proxy's command/status mapping, word packing and a verified HP RAM segment limit. Match or configure the proxy's GP select code. |
| FW-020 | Distinguish HP BOF at the start of a cassette file from a SIMH tape mark terminating/separating TAP files. Define HP-file record grouping, BOF reconstruction and zero-padding preservation under issue 009. Retain HP headers, checksum bytes, reserved allocation and the empty HP EOT file; ignore TAP alignment pads and reject unsupported control values without discarding them silently. |
| FW-022 | Initialize the package pin map before enabling HP service; preserve PA9/PA10 serial debug, continuous TIM1 clock and direct-input FT/power constraints. |
| FW-021 | Physical captures initially lack BOF flags. Recover markers by parsing bounded header/allocation spans, not by replacing all ordinary 0x3C values. Preserve original data and checksum bytes and report ambiguous/truncated captures; keep optional renumber/checksum/padding repair separate. |

Ownership implemented in `mpsi_storage.c`:

```mermaid
stateDiagram-v2
    [*] --> OFF
    OFF --> SERVING: mount / prepare / enable / ready
    SERVING --> MSC: idle / disable / flush / sync / unmount / attach
    MSC --> SERVING: host released / detach / mount / prepare / enable / ready
    SERVING --> FAULT: file or transition error
    MSC --> FAULT: transition error
    OFF --> FAULT: initialization error
```

SERVING in the current core means locally owned FAT with server functions; it
does not implement the required Tape Controller role. Add an application-role
dispatcher and controller transport/job engine. Switching HP roles disables
service, closes/syncs files, clears pending queues and flags, selects the required
device configuration and prepares the next handler before restoring service.
VHDL implements GP-only Controller gating through TP select code zero; GP8/TP-off/
printer-off/IRQ3 is 0x0608. Server GP8/TP9/IRQ3 is 0x0698, or 0x0798 with printer.
The portable configuration validator and tests accept zero as a decoder disable
and reject reserved interrupt selectors. The
operator stops HP use/controller jobs before a mode change. MSC owns no HP role
and may not run controller jobs. On host release restore the selected local role
only after media/configuration revalidation. The new role UI and target code
remain unimplemented; [the analysis](07_tape_analysis.md) traces the reference.

The operator is responsible for avoiding MSC during HP use; issue 011 is resolved
and no hardware quiesce guarantee is required. The current portable core still
returns BUSY if its best-effort HP check reports activity. That check cannot prove
the independent HP will remain idle. File/cache flushing and exclusive FAT/USB
ownership remain mandatory. Leaving MSC waits for host release before remounting.

Board callbacks must serialize transitions and USB block work in the main loop,
or provide equivalent synchronization. The portable structs are not a lock-free
ISR interface. USB handlers must defer work appropriately. `usb_host_released`
covers SCSI eject/disconnect and completion of writes; `usb_stop` drains callbacks.
The USB stack must implement capacity, 512-byte block geometry, sense errors,
cache synchronization and START STOP UNIT semantics. Rescan selected paths after
USB edits; do not retain stale FAT handles.

`hp_prepare` runs with HP_RUN low, resets queues, programs validated configuration
and stages data with flags clear. Raising HP_RUN releases the flag resets;
`hp_ready` then sends initial ACK/status, loaded when CS returns high. Writing ACK while HP_RUN is low cannot
initialize it. The core publishes serving mode after the ready callback succeeds.

The data/status shift register drives the HP gates directly. Transmit responses
only while General ACK is clear or Fast CFI is clear and the request is being
serviced; after asserting ready, retain the data until the next request. Do not
poll inputs by sending dummy frames while the HP can read the previous response.
CS rising loads ACK/CFI/SSI after the last SPI edge and the settling guard; there
is no separate COMMIT pin or data-first/repeat requirement. Configuration uses
CFG_FRAME to disable HP service while its bits shift. Start HP SPI2 at 9 MHz;
18 MHz is the MCU's specified ceiling, and the proposed 24 MHz needs resolution
under issue 028. Give unacknowledged Fast commands prompt service without waiting
for display or SD work; the hardware has no overrun monitor or unread-word lock.

The cassette engine has a random-access media abstraction returning OK, BUSY or
ERROR. A cache miss returns BUSY; control-marker searches examine at most 32 cells
per poll and resume at the saved position. Writes advance only after acceptance.
STOP and high-speed rewind without control mode return status with CFI clear,
following the existing server's command policy. Physical delays, STOP preemption
and ROM behaviour still need validation. The legacy server's 275..400 us
read-forward workaround remains an open timing issue.

The user chooses **SIMH TAP** for SD cassette images. This supersedes the earlier
fixed-size binary-file proposal. The cassette engine can retain its internal
16-bit cell abstraction (data in bits 7:0 and control marker in bit 8); the media
backend must translate between those cells and TAP records. That abstraction
does not require an SD file to contain bare 16-bit cells. No TAP reader/writer,
XNS converter or target cache backend exists yet. The prototype's cell backend
has a fixed capacity; a TAP backend must implement record-aware seeking and
overwrite/growth without loading an entire cassette into 20 KiB RAM.

Yes, Hilpert's supplied software uses `.t98`/XNS: the server in
[tp.c](../software/mpsiServer/tp.c) calls `XNS_Decode` and `XNS_Encode`, and the
repository includes [machine.t98](../software/machine/machine.t98). For example,
`41~83C~!` represents data 0x41 followed by control-marked 0x3C; `~` ends a token
and `!` ends the image. The legacy flag is 0x0800. The prototype cache represents
these cells as 0x0041 and 0x013C, translating that flag to bit 8. Any importer or
exporter must preserve its meaning as well as cassette headers/checksums.

[SIMH's specification](https://simh.trailing-edge.com/docs/simh_magtape.pdf)
describes byte records framed by matching little-endian 32-bit lengths, with
one padding byte when the payload length is odd. A zero marker is a tape mark.
These fields provide record structure and forward/reverse navigation, but do
not directly specify an HP9830 control flag on an arbitrary individual byte.

The subsequent [reader/writer and image analysis](07_tape_analysis.md) establishes
that BOF is the defined Beginning-of-File control byte, followed by a 12-word
header and its checksum, then one continuous content area and its checksum.
There is no separately framed data-block layer inside an HP cassette file.

The earlier BOF-to-mark experiment round-trips all 4,895 cells using three marks
and four records, but its first record contains only initial zero padding. It
therefore does not give each HP file its usual TAP-file interpretation. This
experiment is retained for analysis and superseded as a production requirement.
A natural mapping uses one HP file per TAP file, with a mark after its record(s)
and an importer-generated BOF before the HP header. Exact padding preservation,
record grouping and final mark/EOM handling remain open in issue 009.

Additional-media validation, physical overwrite timing and production
record-aware partial writes remain work. The inspection tool rejects other
control values rather than losing their flags.
Controller captures initially lose BOF flags through data-mode reading; recover
them by parsing headers/allocation spans before converting to marked TAP. The
sample contains four ordinary `0x3C` bytes, so substituting every `0x3C` is wrong.
Keep the empty final HP EOT placeholder as a file, distinct from TAP container EOF.

Configuration is accepted as simple name/value pairs on FAT. Proposed card layout
and keys (not implemented):

```text
/mpsi/config.ini
/paper/                 paper-tape/BASIC input
/tape/                  SIMH TAP cassette images
/capture/               printer and General Mode output
```

Use one `key=value` per line, for example `gp_code=8`, `tp_code=9`,
`printer_enabled=0`, `interrupt_selector=3`, `tape_write_protected=1`, and selected
input/capture/tape paths. The UI updates this file while local FAT owns the card;
MSC never accesses it through local filesystem APIs. Missing or invalid paths
are reported before their service is enabled. Following the reference UI,
append to selected capture files and offer creation of a new sequentially named
capture file; do not silently truncate an existing capture.

The status screen will show SD presence, Server/Controller/MSC/fault role, selected
files, tape write protection and controller-job progress. Select opens the menu;
up/down move the cursor;
select enters settings or chooses a file. Every submenu includes Back. Settings
cover GP code, TP code, printer enable and interrupt selector. MSC displays HP
activity detected, USB SD card active, or Waiting for host eject as appropriate. Address
changes use the same operator-managed handover and validated persistent configuration.
The Controller menu offers physical read/write, rewind and stop through the loaded
HP proxy. The existing MTAPE proxy expects GP select code 8 and uses a buffered
writer with a 6000-byte host limit. Validate the actual HP RAM/proxy layout before
writing; enable no TP/printer server handler while Controller owns GP. SD stalls
must not block controller read capture while the physical cassette keeps moving.

Initial memory target: two 4 KiB SD/tape buffers, a 1 KiB OLED framebuffer,
FAT/USB sector buffers, bounded queues and reserved stack space. This is not a
measured build size. A whole cassette image generally cannot fit in 20 KiB RAM.
A 1024-byte OLED frame at 400 kHz takes roughly 23 ms on the wire; it must not
block the HP service path. SD cache, USB and display ports remain to be written.

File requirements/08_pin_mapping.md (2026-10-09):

# Package pins and tentative placement

2026-10-09, revision tentative-3. The simplified implementation fits with all
29 requested logical pins retained. Electrical, timing and routing validation
remain open; this is a board draft, not manufacturing sign-off.
Keep schematic/board and inline VHDL constraints synchronized through
[`pinmap.json`](../hardware/rev2/pinmap.json) and the pin/net checker.

Use STM32F103CBT6 in LQFP48 and industrial ATF1504AS-10JU44 in PLCC44.
The MCU package tables use [ST DS5319, Rev 20](https://www.st.com/resource/en/datasheet/stm32f103c8.pdf);
CPLD supplies, JTAG and dedicated inputs use [the ATF1504 datasheet](https://ww1.microchip.com/downloads/en/DeviceDoc/Atmel-0950-CPLD-ATF1504AS(L)-Datasheet.pdf).

## STM32 assignment

| Function | GPIO (package pin) | Routing / initialization |
| --- | --- | --- |
| HP SPI2 | PB13 SCK (26), PB14 MISO (27), PB15 MOSI (28), PB12 CS (25) | Mode 2; no remapping; PB14 is a direct FT input. |
| CPLD controls | PB1 CFG_FRAME (19), PB8 HP_RUN (45), PB9 RESET_n (46) | 3.3 V outputs; external default-low pulls. PB0 is spare after removing COMMIT. |
| CPLD request | PB10 REQUEST_n (21) | Direct FT input; EXTI10 request; internal pulls disabled. PB11 is spare after removing overrun. |
| Capture clock | PA8 TIM1_CH1 (29) | 24 MHz from 72 MHz timer, PSC=0 ARR=2 CCR1=1. |
| SD SPI1 | PA4 CS (14), PA5 SCK (15), PA6 MISO (16), PA7 MOSI (17) | Dedicated SPI1; all signals at 3.3 V. |
| SD detection | PB4 (40) | Active low to ground, 10 kOhm pull-up to 3.3 V; debounce/rescan. |
| OLED I2C1 | PB6 SCL (42), PB7 SDA (43) | 4.7 kOhm to 3.3 V; check module pull-ups and address. |
| Buttons | PA0 up (10), PA1 down (11), PA2 select (12) | Active low, 10 kOhm pull-ups; software debounce. |
| USB | PA11 DM (32), PA12 DP (33), PB5 pull-up enable (41), PA3 VBUS sense (13) | PA3 receives the divided voltage, not 5 V. PB5 drives 1.5 kOhm D+ pull-up. |
| Serial debug | PA9 TX (30), PA10 RX (31) | USART1; J5 order: 1=+3.3 V, 2=TX, 3=RX, 4=GND. 3.3 V UART levels. |
| Debug / oscillator | PA13 SWDIO (34), PA14 SWCLK (37), PD0/PD1 HSE (5/6) | Keep SWD; 8 MHz crystal proposal. |

PA6 is **not** FT and therefore serves the 3.3 V SD MISO. PB14 is FT and
resets as an ordinary GPIO, so SPI2 is used for the 5 V HP input chain.
The earlier remapped-SPI1 proposal used PB4 MISO, but PB4's reset-state JNTRST
pull-up complicates direct 5 V operation. This map keeps PB4 at 3.3 V for card
detect, and PB5 (non-FT) drives the USB pull-up. PA9 remains reserved for TX;
VBUS sense uses PA3. MCU outputs must satisfy the CPLD/HCT TTL input thresholds
at worst-case voltage and loading.

Firmware uses SPI2 for the HP link and SPI1 for SD, without SPI remapping.
Set `AFIO_MAPR.SWJ_CFG=010` (JTAG off, SWD on) to release PB4 for card detect.
PB0/PB3/PB11 are spare; SWO can be considered later. Configure PB14/PB10 as floating
digital inputs with no internal pull-up/down before applying 5 V signals.

FT operation is specified with the MCU powered in its stated supply range.
The absolute FT input bound depends on VDD (`VDD + 4 V`); this does not make
a 5 V source safe when VDD is zero. The direct 5 V pins reset without the JNTRST pull-up complication. Check the supply ramp, reset and fault cases for
the CPLD request, HCT165 MISO and raw-VBUS divider. Direct connections
are tentative until issue 026 is resolved; isolation may still be needed.
Do not assume the Schottky supply topology alone proves safe sequencing.

All MCU package pins:

| Pin | STM32 signal | Board net | Use |
| --- | --- | --- | --- |
| 1 | VBAT | +3V3 | power |
| 2 | PC13 | NC | spare |
| 3 | PC14 | NC | spare |
| 4 | PC15 | NC | spare |
| 5 | PD0 | HSE_IN | clock |
| 6 | PD1 | HSE_OUT | clock |
| 7 | NRST | MCU_RESET_n | in |
| 8 | VSSA | GND | power |
| 9 | VDDA | +3V3 | power |
| 10 | PA0 | BUTTON_UP_n | in |
| 11 | PA1 | BUTTON_DOWN_n | in |
| 12 | PA2 | BUTTON_SELECT_n | in |
| 13 | PA3 | USB_VBUS_SENSE | in |
| 14 | PA4 | SD_CS_n | out |
| 15 | PA5 | SD_SCK | out |
| 16 | PA6 | SD_MISO | in |
| 17 | PA7 | SD_MOSI | out |
| 18 | PB0 | NC | spare |
| 19 | PB1 | CPLD_CFG_FRAME | out |
| 20 | PB2 | BOOT1 | in |
| 21 | PB10 | CPLD_REQUEST_n | in_5v_ft |
| 22 | PB11 | NC | spare |
| 23 | VSS1 | GND | power |
| 24 | VDD1 | +3V3 | power |
| 25 | PB12 | CPLD_CS_n | out |
| 26 | PB13 | HP_SPI_SCK | out |
| 27 | PB14 | HP_SPI_MISO | in_5v_ft |
| 28 | PB15 | HP_SPI_MOSI | out |
| 29 | PA8 | CPLD_MCK | out |
| 30 | PA9 | DEBUG_TX | out |
| 31 | PA10 | DEBUG_RX | in |
| 32 | PA11 | USB_DM | bidirectional |
| 33 | PA12 | USB_DP | bidirectional |
| 34 | PA13 | SWDIO | bidirectional |
| 35 | VSS2 | GND | power |
| 36 | VDD2 | +3V3 | power |
| 37 | PA14 | SWCLK | in |
| 38 | PA15 | NC | spare |
| 39 | PB3 | NC | spare |
| 40 | PB4 | SD_CD_n | in |
| 41 | PB5 | USB_PULLUP_EN | out |
| 42 | PB6 | OLED_SCL | bidirectional |
| 43 | PB7 | OLED_SDA | bidirectional |
| 44 | BOOT0 | BOOT0 | in |
| 45 | PB8 | CPLD_HP_RUN | out |
| 46 | PB9 | CPLD_RESET_n | out |
| 47 | VSS3 | GND | power |
| 48 | VDD3 | +3V3 | power |

## CPLD assignment

The three clock domains use GCLK2 pin 2 (SPI SCK), GCLK3 pin 41 (CS rising for flags),
and GCLK1 pin 43 (MCK). Reset uses GCLR pin 1, HP_RUN uses dedicated input/OE1
pin 44, and JTAG retains pins 7/13/32/38. Pins 34/39/40 are spare. CS moved from
pin 40 to the global clock pin freed by removing COMMIT.
HP DI0..7 and SI0..3 correspond to `hp_n_di_0` through `hp_n_di_11`.
All fourteen HP outputs are 0/Z in VHDL and must be fitted open collector with
pin keepers off. MCU-facing REQUEST_n and HCT PL are push-pull at 5 V.

| PLCC pin | RTL / package function | Board net |
| --- | --- | --- |
| 1 | reset_n | CPLD_RESET_n |
| 2 | spi_sck | HP_SPI_SCK |
| 3 | VCC | +5V_LOGIC |
| 4 | hp_n_cfi | nCFI |
| 5 | co_0 | CO0 |
| 6 | co_1 | CO1 |
| 7 | TDI | CPLD_TDI |
| 8 | co_2 | CO2 |
| 9 | co_3 | CO3 |
| 10 | GND | GND |
| 11 | nceo | nCEO |
| 12 | nsih | nSIH |
| 13 | TMS | CPLD_TMS |
| 14 | hp_n_ssi | nSSI |
| 15 | VCC | +5V_LOGIC |
| 16 | hp_n_di_11 | nSI3 |
| 17 | hp_n_di_10 | nSI2 |
| 18 | hp_n_di_9 | nSI1 |
| 19 | hp_n_di_8 | nSI0 |
| 20 | hp_n_di_7 | nDI7 |
| 21 | hp_n_di_6 | nDI6 |
| 22 | GND | GND |
| 23 | VCC | +5V_LOGIC |
| 24 | hp_n_di_5 | nDI5 |
| 25 | hp_n_di_4 | nDI4 |
| 26 | hp_n_di_3 | nDI3 |
| 27 | hp_n_di_2 | nDI2 |
| 28 | hp_n_di_1 | nDI1 |
| 29 | hp_n_di_0 | nDI0 |
| 30 | GND | GND |
| 31 | input_pl_n | HP_INPUT_PL_n |
| 32 | TCK | CPLD_TCK |
| 33 | request_n | CPLD_REQUEST_n |
| 34 | SPARE34 | NC |
| 35 | VCC | +5V_LOGIC |
| 36 | spi_mosi | HP_SPI_MOSI |
| 37 | cfg_frame | CPLD_CFG_FRAME |
| 38 | TDO | CPLD_TDO |
| 39 | SPARE39 | NC |
| 40 | SPARE40 | NC |
| 41 | spi_cs_n | CPLD_CS_n |
| 42 | GND | GND |
| 43 | mck | CPLD_MCK |
| 44 | hp_run | CPLD_HP_RUN |

VHDL carries DECPROMEM-style constraints, for example:

```vhdl
--PIN: CHIP "mpsi_cpld" ASSIGNED TO AN PLCC44
--PIN: spi_sck : 2
--PIN: spi_cs_n : 41
--PIN: mck : 43
```

The build uses `-preassign keep`. A successful fitter result is accepted only
when all 29 logical pins remain assigned as requested and JEDEC exists.
The simplified implementation passes this check and retains JTAG, fourteen
open-collector HP outputs and disabled pin keepers. The report has inconsistent
resource totals despite declaring a fit; issue 029 records the accounting review.
See [build notes](../hardware/rev2/README.md) and issue 004.

## Placement and external connections

The draft copies the legacy connector position and complete board outline.
The coordinate origin is the KiCad board origin; dimensions are millimetres.
These component centres/orientations are tentative:

| Component | X | Y | Rotation |
| --- | --- | --- | --- |
| U1 | 118 | 80 | 90 degrees |
| U2 | 82 | 78 | 90 degrees |
| U3 | 63 | 94 | 0 degrees |
| U4 | 63 | 59 | 0 degrees |
| J2 | 171 | 113 | 90 degrees |
| J3 | 160 | 80 | 90 degrees |
| J4 | 143 | 43 | 0 degrees |
| J5 | 151 | 96 | 0 degrees |

U3 captures DO0..7; U4 captures SO0..3 and CO0..3. U3 Q7 feeds U4 DS;
U4 non-inverting Q7 feeds PB14 directly. Both CE pins are low, CP uses PB13
and PL uses CPLD pin 31. See the exact word/pad order in
[02_hardware.md](02_hardware.md) and [06_existing_connector.md](06_existing_connector.md).

Keep CPLD/HCT165 traces to the HP connector short. Route controls/clock/SPI
across the MCU-facing CPLD side, place decouplers beside the actual supply
pins, and keep the USBLC6 beside USB-C with short connector-to-protection paths.
Keep USB D+/D- together through protection/22 Ohm series resistors to PA11/PA12.
The board is unrouted; connector orientation, enclosure access, crystal loading
and production clearances remain open in issue 027.

SPI2 provisionally uses 9 MHz from APB1=36 MHz /4. The proposed 24 MHz SPI is
above the STM32F103's stated 18 MHz ceiling. Validate HCT165 cascade and MISO
timing before raising the rate; see issue 028. The PA8 capture clock stays 24 MHz.

USB-C uses the same HRO-TYPE-C-31-M-12 symbol/footprint and USBLC6-2SC6 circuit
as the pinned paper-tape project (source S15). Each CC pin has a 5.1 kOhm sink
resistor; each data line has 22 Ohm series resistance. USBLC6 power/clamp uses
raw USB VBUS. The 1.5 kOhm D+ pull-up is controlled by PB5, with an added
10 kOhm default-low pull. The 1.8 kOhm / 3.3 kOhm VBUS divider feeds PA3.
Keep the reference power-source diodes and TLV75533 footprint, subject to the
CPLD industrial 4.50 V rail budget in issue 022.

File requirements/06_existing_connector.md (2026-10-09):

# Existing connector reference

Extracted from the current [KiCad PCB](../MPSIBOARD/MPSIBOARD.kicad_pcb) and
cross-checked against J1's symbol/footprint in the
[current schematic](../MPSIBOARD/MPSIBOARD.kicad_sch), 2026-10-08.
The PCB contains embedded pad/net assignments; exporting a separate netlist is
not necessary to read these connections. Legacy hardware files are unchanged.

J1 footprint: `Connector:EDAC 2x25 3.96mm`, at (41.327, 37.923) mm,
rotated -90 degrees. Pad row **a is B.Cu**, row **b is F.Cu**. These are KiCad
pad labels and board sides, not Hilpert's letter/number connector convention.
Retain the footprint's orientation and full connector outline when reusing it.

| Position | a: B.Cu | b: F.Cu |
| --- | --- | --- |
| 1 | NC | GND |
| 2 | nCFI | nCEO |
| 3 | nSIH | nSSI |
| 4 | CO3 | CO2 |
| 5 | CO1 | CO0 |
| 6 | nSI3 | SO3 |
| 7 | nSI2 | SO2 |
| 8 | nSI1 | SO1 |
| 9 | nSI0 | SO0 |
| 10 | nDI7 | DO7 |
| 11 | nDI6 | DO6 |
| 12 | nDI5 | DO5 |
| 13 | nDI4 | DO4 |
| 14 | nDI1 | nDI2 |
| 15 | DO3 | nDI3 |
| 16 | DO2 | DO1 |
| 17 | DO0 | nDI0 |
| 18 | NC | NC |
| 19 | NC | NC |
| 20 | NC | NC |
| 21 | +5V | +5V |
| 22 | GND | GND |
| 23 | NC | NC |
| 24 | NC | NC |
| 25 | NC | NC |

NC means unconnected in the existing design, not permission to drive a reserved
HP contact. The existing contact assignment includes all CO/SO/DO inputs and
DI/SI/CFI/SSI outputs required by Rev2. It does not route HP MCK; Rev2 uses PA8's
TIM1 clock instead.

The footprint has 25 contacts on each side, 3.96 mm pitch, and pad size
9.00 x 2.65 mm in local footprint coordinates. Pad centres span 95.04 mm;
positions 23..25 are unconnected. The PCB's main rectangle runs from x=41.380
to 179.737 mm and y=36.843 to 134.043 mm, or 138.357 x 97.200 mm. Connector
extensions and outline segments also exist in the footprint and adjacent
Edge.Cuts; that rectangle alone is not the complete board outline.

The older [legacy schematic](../MPSIBOARD/MPSIBOARD.sch) uses a 2x22 symbol,
whereas the current schematic and PCB use 2x25. Use the current files as the
geometry/assignment baseline requested by the user. Hilpert's PDF labels the
connector from the opposite numbering direction; compare signals, not identical
position numbers, when consulting it. These extracted dimensions establish the
available reference, not a new physical-fit measurement.

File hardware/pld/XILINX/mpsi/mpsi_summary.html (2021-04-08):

mpsi Project Status (04/08/2021 - 19:16:07)
Project File: | mpsi.xise | Parser Errors: | No Errors
Module Name: | mpsi | Implementation State: | Fitted
Target Device: | xc2c32a-6VQ44 | Errors: | No Errors
Product Version: | ISE 14.7 | Warnings: | 1 Warning (1 new)
Design Goal: | Balanced | Routing Results:
Design Strategy: | Xilinx Default (unlocked) | Timing Constraints:
Environment: | System Settings | Final Timing Score:

Detailed Reports | | | | | | [-]
Report Name | Status | Generated | Errors | Warnings | Infos
Synthesis Report | Current | tor 8. apr 19:15:28 2021 | 0 | 1 Warning (1 new) | 0
Translation Report | Current | tor 8. apr 19:15:42 2021 | 0 | 0 | 0
CPLD Fitter Report (Text) | Current | tor 8. apr 19:15:51 2021 | 0 | 1 Warning (1 new) | 0
Power Report

Secondary Reports | | | [-]
Report Name | Status | Generated
Post-Fit Simulation Model Report

Date Generated: 04/08/2021 - 19:16:07

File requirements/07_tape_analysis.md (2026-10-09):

# Tape modes, BOF and the supplied images

Analysis performed 2026-10-08 against the repository and Hilpert's published
[support archive](https://madrona.ca/e/HP9830/pgm9830.tgz).
The downloaded archive SHA256 is
`9d823ae67221a177a7dbff5c175fd9141cb47649cbd219f9c04f19069442ab03`.
It contains one `.t98` image and two substantive `.f98` files. These three
images and the five inspected source/documentation files are identical to the
local copies. The `._blockscan.f98` entry is AppleDouble metadata, not another tape file.
This is one sample cassette image, not a survey of recovered media.

The application has three mutually exclusive roles:

| Role | HP-side operation | SD-side operation |
| --- | --- | --- |
| MPSI Server | HP asks for paper-tape bytes, virtual cassette operations and printer/output capture. | Serve/capture selected files and emulate a cassette image. |
| Tape Controller | The HP runs the MTAPE proxy; the MCU supplies directives through the General interface and receives real-drive status/data. The proxy accesses the physical cassette drive at SC10. | Read/save cassette images/files, or supply data for writing to physical cassette. |
| USB MSC | Every HP output is released and HP application handlers are disabled. | Host owns raw SD blocks; local FAT and both HP roles stop. |

```mermaid
flowchart LR
    subgraph Server
        BASIC[HP BASIC / ROM] -->|requests| V[MPSI virtual devices]
        V <--> SD1[SD files / virtual tape]
    end
    subgraph Controller
        SD2[SD image / file] <--> MCU[MCU tape-control job]
        MCU <-->|GP directives / replies| Proxy[MTAPE proxy on HP]
        Proxy <-->|internal SC10| Drive[Physical cassette drive]
    end
```

Both HP roles use local FAT ownership, but different General-port handlers.
The current portable firmware only implements server functions. It does not
implement the MTAPE controller, a role dispatcher or a physical-tape job UI.
Controller mode needs GP enabled and TP/printer emulation disabled. HP_RUN=0
alone cannot implement that distinction, because it also disables the GP link
needed by the proxy. The VHDL update now uses select code zero to disable
GP/TP independently without responding to HP SC0. Controller GP8/TP-off/
printer-off/IRQ3 is 0x0608, verified by the bench. Firmware role/physical-job
work remains in issue 025; CPLD fitting remains in 004.

BOF means **Beginning of File**. On HP cassette it is an actual byte `0x3C`
recorded with its control bit set. The physical drive can search for it in either
direction. Data-mode reading delivers byte values without their control bits.
[Hilpert's tape description](https://madrona.ca/e/HP9830/hardware.html).
The local representation is established directly by
[Tpf_putHeader](../software/tp9830/tpf.c) and
[T98_CMD_CTLBYTE](../software/tp9830/t98.h): `0x3C | 0x0800 = 0x083C`.
Thus XNS token `83C~` denotes BOF; plain `3C~` can be ordinary data.

The image is a sequence of cells, with this structure for each cassette file:

```text
BOF | 12 header words | header checksum | content | content checksum | unused space
```

There are no separately framed data records or fixed-size data blocks within
this file format. One cassette file occupies one continuous byte sequence;
header and content are distinguished by their positions and lengths. The name
"Binary block" for file type 1 describes the contents, not an additional tape
record layer. Likewise, the writer's buffered "segments" below are transfer
units, not blocks stored in `.t98`. A complete `.t98` may contain many files.

Words are little-endian 16-bit values stored as two ordinary byte cells. Header
and content checksums are separate sums modulo 65536. The header contains file
number, used length, file type, reserved space, BASIC line numbers and common
area length; five additional header words are retained even when zero. The
content checksum follows the used contents, not necessarily the end of the
reserved allocation. Zero cells separate files. This structure comes from
[tpf.h](../software/tp9830/tpf.h) and [tpf.c](../software/tp9830/tpf.c).

This header is recorded on the actual HP cassette before each file's contents.
It is the header parsed by `Tpf_AnaHeader`, not a host-container header. Byte
offsets below are relative to the BOF cell, whose offset is 0:

| Byte offset | Size | Field | Meaning |
| --- | --- | --- | --- |
| 0 | 1 cell | BOF | Control-marked `0x3C`; `0x083C` in the XNS image. |
| 1 | 1 word | FileID / FileNum | Sequential file number. |
| 3 | 1 word | FileLength | Used content words, excluding the content checksum. |
| 5 | 1 word | FileType | 0: unused, 1: binary, 2: data, 3: BASIC; other types are listed in Hilpert's description. |
| 7 | 1 word | FileSpace | Reserved content capacity in words, excluding the checksum. |
| 9 | 1 word | FirstLine | First BASIC line number. |
| 11 | 1 word | LastLine | Last BASIC line number. |
| 13 | 1 word | CommonAreaLen | Common-area length in words. |
| 15, 17, 19, 21, 23 | 5 words | Additional header words | Zeroed by `Tpf_putHeader`; their other meanings are not established here. |
| 25 | 1 word | Header checksum | Sum of the preceding 12 header words, modulo 65536. |
| 27 | FileLength words | Contents | The used file data. |
| 27 + 2 * FileLength | 1 word | Content checksum | Sum of the used content words, modulo 65536. |
| 29 + 2 * FileLength | FileSpace - FileLength words | Unused allocation | Space reserved for a larger version of the same file. |

The header therefore occupies 24 bytes plus a 2-byte checksum, after the BOF.
The allocated file span, including BOF and both checksums, is
`29 + 2 * FileSpace` cells. Its end is calculated from FileSpace; the location
of the content checksum is calculated from FileLength. A separate end-of-file
control byte is not needed. Zero padding follows the allocation before the next
BOF. For example, file 0 below has FileLength=FileSpace=354: 708 used content
bytes and a total span of 737 cells, from BOF at 300 through cell 1036.

`.t98` is a complete cell-oriented cassette image in XNS text. `.f98` is a
single-file, word-oriented XNS representation used by the tools. They share
text syntax but must not be decoded as the same kind of tape data.

`machine.t98` is 12,639 text bytes containing 4,895 cells:

| HP file | BOF cell offset | Type / source | Used words | Reserved words | Header checksum | Content checksum |
| --- | --- | --- | --- | --- | --- | --- |
| 0 | 300 (`0x012C`) | Binary block: mbb.f98 | 354 | 354 | 02C5: valid | 672D: valid |
| 1 | 1214 (`0x04BE`) | BASIC program: blockscan.f98 | 1319 | 1319 | 0F34: valid | 2234: valid |
| 2 | 4540 (`0x11BC`) | Empty EOT placeholder | 0 | 13 | 000F: valid | 0000: valid |

Padding is 300 cells before file 0, 177 before file 1, 659 before file 2 and
300 after file 2. There are exactly three flagged `0x083C` cells and four
ordinary `0x3C` cells. Both populated contents exactly match their `.f98` sources.
The final empty file is a convention used by the tools, not a distinct EOT
control byte; [the supplied documentation](../software/tp9830/helpdoc.txt)
describes that convention. It must be retained when converting an image.

`mbb.f98` has 368 words: its first header word is `0x9830`, reserved space is
zero and its stored header checksum is zero. Those fields form an unfinished
input header, not the final cassette header. `Tpf_LoadFile` assigns the cassette
file number/space and recalculates checksums. Its 354-word contents/checksum match
the image exactly. `blockscan.f98` has 1,333 words and valid header/content sums.

The reader and writer operate differently:

1. [T98_Read](../software/tp9830/t98_mpsi.c) starts the physical drive, clears
   leader and obtains bytes through the GP proxy, saving only `sr & 0xFF`.
   A raw capture therefore contains unflagged `0x3C` at BOFs. `Tpf_Cleanup`
   reconstructs BOFs outside file allocations by walking the header's FileSpace;
   it skips the contents where ordinary `0x3C` values may occur. It can also
   renumber files, change padding and recalculate sums. The new imager must
   separate marker recovery from those optional content-changing operations.
   Preserve original header/content/checksum bytes; report ambiguous/truncated
   headers rather than blindly treating every `0x3C` as BOF.
2. `T98_Write` splits at flagged cells, leaving the BOFs out of ordinary data
   segments. It pushes segment bytes in reverse order into the HP's RAM buffer,
   then asks the proxy to perform the time-critical write and optionally create
   the next BOF. The four sample segments are 300, 913, 3325 and 354 bytes.
   Odd segments get one zero byte for the HP's word packing. The existing host
   rejects segments over 6000 bytes; the relay has no independent bound check.
   This bound is specific to the existing proxy/RAM layout, not a universal HP
   tape-file-size limit or an established STM32 performance limit.

The old reader holds the whole image in host RAM; the STM32 must stream to SD
through bounded buffers. A real cassette keeps moving during SD stalls, so the
controller's GP receive path and queue cannot wait for blocking SD writes.
Validate read capture/overflow handling separately from server emulation, where
the MCU can delay readiness before supplying the next virtual-tape byte.

The [MTAPE proxy](../software/machine/mbb.s) defines these GP directive values;
the GP ACK bit is supplied separately by the MPSI response register:

| Directive | Logical value | Effect |
| --- | --- | --- |
| Execute command | `0x0200` plus four-bit command; add `0x0080` to wait | Proxy sends the command to the real drive and returns status/read byte. |
| Push byte | `0x0400` plus byte | Push one byte onto the reverse-order HP write buffer. |
| Write buffer | `0x0800` plus options | Options 1: clear leader/write, 2: find BOF/write, 4: write next BOF. |

The reply carries eight data bits and three tape-status bits. The proxy moves
the no-cassette status to bit 8 because bit 11 is needed as the GP direction bit;
the MCU must reverse that mapping. Unlike the legacy GPIO driver, the proposed
HCT165 Q7 path delivers non-inverted captured values: do not copy the legacy
bitwise inversion. The proxy currently hard-codes GP select code 8 at
`MPSI_GPSC_INPUT`; match that setting or patch/rebuild the proxy. The MCU is
an external command source through GP; the HP remains the bus master.

HP BOF and SIMH tape marks have different positions in a logical file layout:

```text
HP cassette: padding | BOF | header + content + checksums | padding | BOF | next file ...
TAP files:   record(s) for file 0 | tape mark | record(s) for file 1 | tape mark ...
```

[SIMH's container specification](https://simh.trailing-edge.com/docs/simh_magtape.pdf)
defines matching 32-bit little-endian record lengths, odd-length alignment and
the zero tape-mark object. In the usual magtape file convention, a tape mark
terminates/separates files; a file can contain multiple records. A leading mark
is representable, but is not a BOF required before every file. Those 32-bit
lengths are TAP container framing, separate from the HP header above.

The earlier analysis substituted a TAP mark for every HP BOF and placed ordinary
byte runs in records. It proved a reversible cell-stream encoding, but not the
usual logical-file interpretation. In particular, its first record holds only
the 300 initial zero-padding cells; treating marks as file terminators would
create an extra padding-only file before HP file 0. The user's correction means
this experiment must not be treated as the accepted production mapping.

A natural logical mapping is one HP cassette file per TAP file, initially using
one data record for its header, used contents, checksums and unused allocation.
The importer would generate BOF before each HP file, while TAP marks would
terminate/separate the corresponding files. The final empty HP placeholder
remains a real header-bearing HP file even though its used length is zero.
The handling of initial/inter-file/final zero padding, exact cell preservation,
multiple records within a TAP file and the final TAP mark/EOM convention still
needs definition in issue 009. Normalizing physical padding is not an exact
cell round trip; preserving it needs an explicit layout or metadata policy.

For reference, the **superseded raw-cell experiment** produces:

```text
record(300)  mark  record(913)  mark  record(3325)  mark  record(354)
```

That is a 4,938-byte TAP container. The inspection tool verifies exact recovery
of all 4,895 cells in both directions, including all three flagged and four
ordinary `0x3C` values. Removing every control flag and recovering markers from
the parsed headers also reproduces the original sample exactly. Unknown control
values are rejected by this experimental mapping instead of silently discarded.
`--verify-tap` continues to reproduce that experiment; it does not validate a
conventional logical-file mapping or a production TAP backend.
Physical overwrite timing, large writes, bad-media recovery and further samples
still need validation; a record container does not implement those operations.

Reproduce the analysis without changing any source image:

```sh
python3 scripts/analyze_t98.py software/machine/machine.t98 software/machine/mbb.f98 software/machine/blockscan.f98 --verify-tap --json
```

The tool checks header/content sums, source-content matches, TAP forward/reverse
framing and BOF recovery for the supplied marked image. Independently, a small
host harness compiled the unchanged legacy `util.c`/`tpf.c`, listed the same three
headers without checksum errors, and used `Tpf_LoadFile` plus `Tpf_Cleanup` to
rebuild the entire 4,895-cell image exactly. No cassette hardware was operated.

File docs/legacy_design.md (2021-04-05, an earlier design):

# mpsi_reimpl
This is a re-implementation of the MPSI project by Brent Hilpert

Brent Hilpert has created a [combination of hardware and software that allows a HP 9830](http://madrona.ca/e/HP9830/mpsi/index.html) 
to transfer data back a forth a modern host computer. It is based on several TTL chips and a serial link to a host computer. 
~~The ideas here is to reimplement the same type of system while integrating a Raspbery Pi Zero W on board as well as 
susbstituting most of the glue logic with a CPLD. Then also to create a KiCAD layout for this and a 3D model for the box to 
printed in a 3D printer.
Instead of using a serial protocol the intention is to use a prallell protocol since we have enough pins on the Raspberry Pi Zero W. 
Input data is latched in two 74LVC574 which also give 5V to 3.3V conversion. Outputs will still be 4 pieces of 74LS38 open collector drivers.
One more extra 74LVC245 is added to make it possible to have a dipswitch on the board. The dipswitch can then be enabled onto the bus
and provide selection of various software of tape images to serve from the Raspberry Pi Zero W. The remaining glue logic will be implemented 
in one single Atmel ATF1502 CPLD programmed in CUPL. This will give a compact layout of the card while still use mostly DIP socketed 
chips to ease soldering among hobbyists.
As of now a sketch of the schematic has been created as well as a first draft of the CUPL code.~~

I have changed my mind concerning ATMEL. The only free tool to use with ATMEL is the WinCUPL program. WinCUPL is OLD. Very OLD! And crashes very often. Simulating is almost impossible. I decided to use Xilinx ISE suite instead and use the more modern XC2C32A CPLD. The design fits easily in this CPLD.

I also reconsidered the use of Raspi Zero. Although it might be easier to port the code Raspi Zero I think that the STM32F407VET chip is a better match. Abundant GPIOs. SD card reader. USB IO integrated. I2C.

With this I could replace all hard wired jumpers of the original design with software controlled settings. The IO addresses and interrupt ID could be set programatically.

To control the thing I envision a small control device connected over I2C. This control device will the contain a few buttons, a few LEDs and a small I2C display. Connected over a simple four wire cable.

The SD Card would contain a FAT file system that contain a configuration file and then all all the paper tape files and cassette tape files that one would like to make available to the HP9830. The small user interface control device would then be used to select among those files as well as set up the configuration of the mpsi device, io addresses and interrupt ids.

USB can be used as a virtual serial port and connect to host terminal program for printer output. 

Two 74LVC574 is used to latch data and control signals from the HP9830. Five 74LS38 OC drviers are used to drive the bus. One Xilinx XC3C32A CPLD is used to replace all glue logic. A STM32F407VET6 SoC is used for managing all data flows. a SD card connector and USB port is needed and some small components.

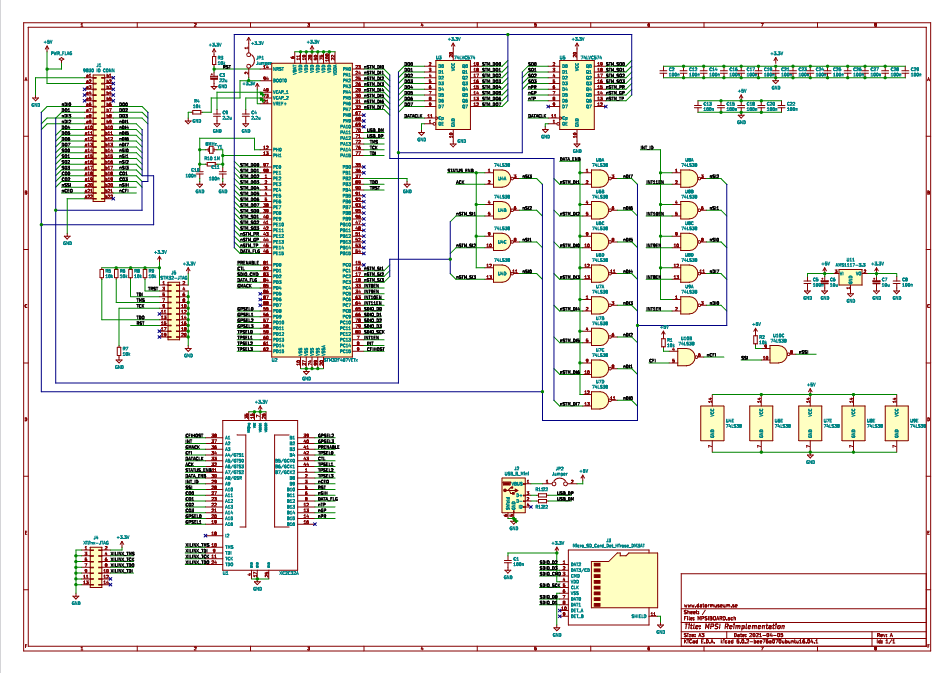
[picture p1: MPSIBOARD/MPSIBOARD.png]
Schematic


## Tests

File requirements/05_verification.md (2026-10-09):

# Verification

Run from the repository root:

```sh
make test
```

Requires make, a C11 compiler and either local GHDL or the documented Docker
image. Build products go in the ignored `build/rev2` directory. The smaller
simulation image can be built with `python3 scripts/rev2_hdl.py build-sim-image`;
see [hardware build notes](../hardware/rev2/README.md).

Verified 2026-10-09: the VHDL-2008 bench passes **2,000 checks at each of 9, 18
and 24 MHz SPI**, with a 24 MHz one-third-duty-cycle MCK. The portable C suite passes with the revised IRQ3 and
zero-address decoder-disable configuration. The full private tool container
builds; GHDL/Yosys synthesis passes its structural check. Corrected Atmel fitting
declares **a fit**, generates JEDEC and retains all 29 requested pins, fourteen
open-collector HP outputs, JTAG and disabled pin keepers. The simplified RTL and
fitter both retain 36 registers. A functional translation of the fitter-emitted
VHO gates/flip-flops passes the same 2,000 checks at each rate. Run it with:

```sh
python3 scripts/rev2_hdl.py postfit
```

This is a zero-delay equation check; SDF is emitted but not applied, JEDEC fuse
encoding is not independently decoded and hardware timing remains unverified.
The report's inconsistent 65/64 macrocell total is recorded in issue 029; do not
derive free-resource margins from it. Earlier apparent fitting with a disconnected
TRI enable was rejected; the build-local liberty correction preserves that logic.
The F103 is specified up to 18 MHz SPI. The 24 MHz run is functional stimulus;
9 MHz is the provisional board rate pending the MCU/HCT165/CPLD timing budget.

The three-sheet KiCad schematic passes ERC with zero violations. Exported nets
are checked against the MCU/CPLD package map, connector/debug pins, HCT165 word
order, SD detection and USB protection. The unrouted PCB has zero schematic
parity mismatches; fifty connector pad positions/sizes/angles/layers are checked
against the legacy board during generation. Placement has no shorts or courtyard
overlaps or silkscreen collisions. Final placement DRC reports two clearance
violations, 236 unrouted connections and zero schematic parity mismatches.
Manufacturing DRC is not complete: unrouted nets and the reference
USB-C footprint's 0.175 mm pad clearance need a production rule/geometry review.
The two clearance violations both concern that copied USB-C footprint.

| ID | Check | Current result |
| --- | --- | --- |
| VER-001 | General output clears SI0, captures data, and restores ready. | VHDL simulation passes. |
| VER-002 | General input direction, data before ACK, SIH gating and SC15 enable/disable. | VHDL simulation passes. |
| VER-003 | Fast read/write held CEO, finite PL, no recapture, CFI and CEO feedback. | VHDL simulation passes. |
| VER-004 | All select codes; five ID lines and three reserved codes; reference normal-status/ID combination, SIH inhibit and CEO clear. | Revised mapping, reserved-code silence and selected GP status beside ID pass VHDL simulation. |
| VER-005 | Sixteen-bit transfers, direct configuration masked during shifting, direct data/status and flags held until CS rises. | RTL and fitter-equation simulations pass at 9/18/24 MHz, including all CO values during a live config update. Firmware rejects invalid configurations. No hardware frame checking, output latch bank or separate COMMIT. |
| VER-006 | Finite input capture, one capture per CEO assertion, CS clears request/inhibits loads, reset/MSC/configuration releases bus. | RTL and fitter-equation simulations pass. A new request replaces an unread capture; no overrun monitor or unread-word protection is required. |
| VER-007 | File bytes/EOF, cassette read/reverse/continue/control marks, write protection and bounded cache retries. | Host C tests pass with fake media. |
| VER-008 | FAT/MSC exclusion, handover ordering, LBA bounds, host-eject interlock and injected failures. | Host C tests pass with fake filesystem/USB. |
| VER-009 | CPLD fitting, open-collector mapping, fixed pins, fitted equations, clocks and timing. | Synthesis/fitting, 29 retained pins, 14 open-collector outputs, JTAG/keepers, 36 registers and fitted-equation bench pass; JEDEC/VHO/SDF exist. Timing/fuse validation and report accounting remain in 005/028/029. |
| VER-010 | Arduino STM32 cross-build, SdFat/MSC round trips, media changes, buttons/OLED and measured service latency. | Target integration not implemented. Package contract now assigns HP to SPI2 and 3.3 V SD to SPI1. |
| VER-011 | Validate fourteen 1 kOhm loads and diode-fed rail; measure CEO width, CO/SO/DO stability, PL and setup to ready flags. | Pull-ups supplied by user; electrical/timing measurements not performed. Direct FT input supply/reset validation remains in 026. |
| VER-012 | HP PTAPE/LIST/WRITE/LOAD/STORE/TLIST/rewind and physical MTAPE proxy. | GP-only Controller decoder configuration passes simulation; firmware jobs and actual HP/cassette trials remain open. |
| VER-013 | Analyze XNS headers/checksums, compare .f98 contents, verify experimental TAP cell encoding and BOF recovery. | Earlier analysis passes on one .t98 and two .f98 files; legacy util.c/tpf.c independently rebuild all 4,895 cells exactly. Production conventional-TAP mapping/backend remain open. |
| VER-014 | Package/inline/netlist consistency, all MCU/CPLD/debug pins, HCT165 bit order, USB/SD wiring and schematic ERC. | Revised 29-pin assignment fits and matches netlist; all 348 PCB pad nets match; ERC zero. Physical sign-off remains open. |
| VER-015 | Reused connector geometry, placement shorts/courtyards and schematic-to-PCB parity. | Geometry assertion passes; no placement shorts/courtyard overlap; parity zero. Board is unrouted; remaining DRC/fabrication work is in 027. |

The HDL bench cites Hilpert's source pages in its header and drives documented
General pulse/poll/SI0 and Fast held-CEO/CFI/feedback sequences. A transparent-load/
shift model represents the two HCT165s using non-inverting Q7. It checks two
24 MHz load cycles and a request only after PL closes. Its 2 us CEO pulse is a
test choice, not an HP minimum specification. The capture controller's reset-release
recovery must still be measured or checked against valid fitted timing.

Functional simulation does not model analog loading, metastability, propagation
skew, current limits, SD stalls or the HP CPU/ROM. Neither ERC nor a simulation
pass establishes voltage compatibility, rail margin, physical timing or correctness
of the programmed device. The generated image is a candidate for hardware validation.

Remaining work: reconcile fitter resource accounting and verify the image/device;
validate capture/SPI timing; resolve bus loading,
diodes and direct-input startup; finish mechanical review/routing; implement
Arduino/SdFat/TinyUSB/SSD1306 drivers and Controller jobs; then exercise both
modes, cassette operations and file persistence on an actual HP.

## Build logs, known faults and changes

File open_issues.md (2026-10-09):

# Open issues

Rev2, started 2026-10-08; reviewed with the user's responses on 2026-10-08.
Status values are `open` and `closed`. Closed means the question is answered or
the design decision is accepted. Open responses distinguish remaining user
clarifications from implementation, calculation or measurement work. Issue
numbers remain stable. The latest review accepts the user's appended answers
and checks the linked reference projects and the existing KiCad files.

| Issue number | Issue | Status | Response |
| --- | --- | --- | --- |
| 001 | What pull-up resistance is used on the HP data and status input bits? | closed | User reports that Tony Duell's schematic specifies 1 kOhm for both DI and SI. Use this value for the design calculations. CFI/SSI are also confirmed as 1 kOhm in 021. |
| 002 | With fourteen 1 kOhm pull-ups, does the chosen CPLD meet VOL and total-current limits? | open | Pull-up values are answered; the remaining work is electrical validation. Nominal pull-up loading is about 5 mA per line, or 70 mA if all fourteen sink simultaneously, before receiver loading. Check tolerances, receiver loads, exact CPLD grade, package/ground-current and thermal limits. The reviewed ATF1504AS datasheet guarantees VOL at 12 mA per output; no further pull-up-value clarification is needed. |
| 003 | Which CPLD is the baseline target? | closed | ATF1504AS remains the baseline. The simplified VHDL has 36 registers, exceeding ATF1502's 32. A smaller device needs a different architecture. The current ATF1504 fit/image-generation result is recorded in 004. |
| 004 | Does the accepted VHDL/GHDL/Yosys/Atmel-fitter flow generate an ATF1504 programming candidate with the requested pins? | closed | Yes: the simplified 36-register design fits and generates JEDEC (31,996 bytes), VHO and SDF. All 29 requested pins, fourteen open-collector HP outputs, disabled pin keepers and JTAG are checked. RTL and a functional translation of fitter-emitted equations each pass 2,000 checks at 9/18/24 MHz SPI. The private SSH submodule is at the corrected hardware/rev2/rtl/atf15xx-yosys-docker path, pinned to 95e46e5f11254cc865614a9dc12fddb522a32f55. A build-local TRI library correction aligns Yosys EN with Atmel ENA; the earlier false fit without it was rejected. Inline --PIN and fixed preassignment are retained; CS now uses GCLK3 pin 41. Use python3 scripts/rev2_hdl.py fit or postfit; reuse the user's download cable for later hardware validation. Image/device/timing validation and the fitter's inconsistent resource totals remain in 005/028/029; this closes generation, not manufacturing sign-off. |
| 005 | Does the accepted 24 MHz TIM1 clock meet capture and HCT165 timing? | open | PA8 TIM1_CH1 is accepted at 24 MHz: 72 MHz timer, PSC=0 ARR=2 CCR1=1, period 41.7 ns, HIGH 13.9 ns, LOW 27.8 ns. RTL/fitter-equation benches check two-cycle PL LOW (83.3 ns) and REQUEST_n only after capture closes. Nominal freeze bound is 208.3 ns excluding propagation/metastability. Verify actual clock margins, CEO/data hold, HCT165 setup/recovery and startup. CS low clears the capture controller/inhibits input load; CS rising loads ACK/CFI/SSI. Retain provisional 125 ns final-data settling and 250 ns inter-transfer recovery guards until checked against physical timing. SDF is emitted but not applied to the functional bench. SPI rate is addressed separately in 028. |
| 006 | Which interrupt identification lines must the three-bit selector support? | closed | Selector codes 0..4 now map to nDI0, nDI7, nSI0, nSI1 and nSI2 in VHDL; default 3 is nSI1/DI9. Hardware codes 5..7 assert neither SSI nor ID. The bench covers all eight, and the portable firmware validator rejects reserved values. No further line-selection clarification is needed. |
| 007 | What are the shortest request spacing and command-specific delays for Fast Mode STOP, rewind and search? | open | Follow the user's simple handshake/timely-service architecture without hardware overrun detection or unread-word protection. Measure command spacing and required response latency, especially unacknowledged operations noted by Hilpert; keep SD/OLED work out of that path. Determine which commands need acknowledgment and whether STOP must preempt a pending read. The legacy server's 275..400 us read-forward workaround remains an observation to explain. This is firmware/timing validation, not a further overrun-feature choice. |
| 008 | What SD buffering and queue sizes keep Fast Mode service within its response budget? | open | Measure cache misses, reverse searches and SD write stalls; then size read/write buffers and queues. Keep blocking SD access out of the HP handler. Portable BUSY/retry logic exists, but the real cache and latency measurements do not. |
| 009 | How should HP cassette files map to conventional SIMH TAP files while preserving image data? | open | BOF meaning and header layout are answered: control-0x3C starts each HP file, followed by 12 header words, header checksum, continuous contents and content checksum. The user correctly distinguishes this from a TAP mark terminating/separating files. The earlier raw-cell substitution round-trips all 4,895 cells but creates a padding-only first TAP file, so it is superseded as the production mapping. Define one HP file per TAP file, record grouping, BOF reconstruction, initial/inter-file/final padding preservation and final mark/EOM handling. Retain HP headers/checksums, reserved space and the empty HP placeholder. See requirements/07_tape_analysis.md; backend and physical validation remain in 010/025. |
| 010 | Does the Arduino/SdFat target build implement and verify all board drivers? | open | Library choice is answered: use official Arduino_Core_STM32 and SdFat, following [hp21xx_papertape_emulator](https://github.com/MattisLind/hp21xx_papertape_emulator). Pin compatible TinyUSB/U8g2 versions, use dedicated SPI1 for SD and SPI2 for HP, implement the CPLD queue/selector, TIM1 clock, SSD1306/buttons, card detection, exclusive MSC ownership and the documented TAP backend. Add the Server/Controller dispatcher and jobs under 025, then cross-build and verify real round trips. The reference uses SH1106; this project requires SSD1306. No further library-family clarification is needed. |
| 011 | Who is responsible for stopping HP use before MSC or configuration changes? | closed | User decision: the operator must avoid MSC while the HP is using the interface. No hardware idle guarantee or quiesce handshake is required. Firmware still disables HP service and flushes/unmounts FAT before USB takes ownership. |
| 012 | How are HP bus power and USB VBUS combined? | closed | User requires a Schottky diode from each source, with cathodes joined at the board supply, to prevent either source feeding the other. Supply voltage after diode drop and power/load validation are tracked in 022. |
| 013 | Where are the connector assignments, orientation and geometry available? | closed | User identifies the existing KiCad design as the source. Read J1 directly from MPSIBOARD.kicad_pcb: its embedded pads/nets contain all assignments and its footprint/Edge.Cuts contain geometry. The current schematic/PCB use a 2x25 footprint; the older .sch file uses 2x22. Reuse the current files consistently; do not infer pad numbering from the older symbol or Hilpert's different numbering convention. Extracted assignments are in requirements/06_existing_connector.md; physical fit remains a hardware verification task. |
| 014 | Which STM32F103 variant meets the measured flash, RAM and stack budget? | open | STM32F103CBT6 remains the candidate with 128 KiB flash and 20 KiB RAM. Measure the linked Arduino/SdFat/TinyUSB/UI build, cache/queue use and stack headroom before fixing the variant. This is a build-budget check, not a further MCU-family question. |
| 015 | Does interrupt identification require a new bus-gating decision? | closed | Follow Hilpert's circuit: normal status/data retain their selection/mode/CEO/SIH gating; interrupt identification adds a sink when SSI and nSIH are high. The VHDL port removes the earlier global interrupt masking, and the bench verifies ordinary selected GP status alongside ID. Requirements/03_interface.md gives the equations. Target integration remains in 010. |
| 016 | What SPI checking, buffering and recovery are required? | closed | User decision: trust STM32 SPI and the HP handshake. Remove bit counting/frame-valid checks, separate COMMIT, the response latch bank, overrun logic and unread-word protection. Data/status drive the HP gates from the shift register; firmware shifts only in a safe handshake interval. Retain Hilpert's three flag flip-flops, loaded by CS rising in place of CTL; CS low clears the request/inhibits input loading. CFG_FRAME masks HP service during direct config shifting. Recovery remains an operator power cycle with USB unplugged, without CRC/readback/replay. Proposed 24 MHz SPI feasibility is tracked in 028. |
| 017 | May FAT file service and USB MSC access the SD card concurrently? | closed | No. The core flushes/closes/syncs/unmounts before USB and detaches before remounting. Host tests cover exclusion, LBA overflow, host release and handover failures. Target integration remains in 010. |
| 018 | How is configuration stored? | closed | User chooses simple name/value pairs in a file on FAT. Use key=value entries; /mpsi/config.ini is the proposed path. File selection and capture creation can follow the HP21xx reference UI: append to selected capture files and offer a new sequentially named file. Validate selected paths after rescan/USB edits and report missing files. Exact keys, defaults and UI implementation belong to 010; no further configuration-format question is needed. |
| 019 | When are initial ACK/status flags initialized? | closed | HP_RUN low resets flags. The core separates prepare/stage from the ready callback after enable; tests cover ready-callback failure. The target driver sends initial ready after HP_RUN rises, with flags loaded on CS rising. There is no separate COMMIT pin. |
| 020 | How is SD card removal detected? | closed | User requires an SD socket card-detect signal connected to an MCU input. Use it to stop HP service and report missing media to USB. Pin choice, polarity and debounce are implementation work in 010; reinsertion behaviour is in 023. |
| 021 | Are CFI and SSI also pulled up through 1 kOhm? | closed | User confirms 1 kOhm on both CFI and SSI. All fourteen driven bus lines now have an accepted pull-up value. Receiver/capacitive loading and release timing are validation work under 002. |
| 022 | Does the diode-fed rail keep the CPLD within its operating range, including MSC? | open | User retains Schottky source isolation and keeps the CPLD powered without asserting RESET_n in MSC. Accepted: leave its clock running and use HP_RUN=0 to release the HP bus. The HP21xx reference schematic specifies 1N5819WS power diodes and a 3.3 V regulator, but this project's 5 V CPLD also needs a rail budget. Commercial minimum is 4.75 V; industrial minimum is 4.50 V. For example, 5.0 V minus 0.3 V is 4.7 V, below the commercial minimum. A high current rating alone does not prove adequate voltage margin. Calculate actual minimum source voltage, forward drop, peak load and chosen CPLD grade; this remains engineering validation, not an unanswered MSC-reset preference. |
| 023 | What happens after SD reinsertion? | closed | User requires an automatic full rescan as soon as insertion is detected and debounced. Reinitialize the card, reread capacity and invalidate old handles/caches/selections. When local service owns the card, remount FAT, rescan and revalidate configuration/paths before resuming HP service. During MSC, refresh raw-card capacity/media state and notify the host; leave local FAT unmounted until host release. Implementation is in 010 and must preserve 017. |
| 024 | How is adapter state reset after a protocol failure? | closed | User confirms a full power cycle with USB unplugged. Removing both supplies resets MCU and CPLD state; no HP-reset detection or additional menu recovery is required for protocol faults. |
| 025 | How are exclusive Server/Controller roles and physical-tape jobs implemented and validated? | open | Two exclusive HP applications plus disconnected MSC are accepted. VHDL now uses select code zero to disable GP/TP independently without responding to HP SC0; Controller GP8/TP-off/printer-off/IRQ3 uses 0x0608, verified by the bench. The remaining work is the firmware role/job dispatcher and physical MTAPE transport. The proxy expects GP8, buffers reversed byte pushes for writing, and has a 6000-byte host segment limit with no proxy-side bounds check. Validate HP RAM, SD streaming, BOF recovery, write positioning and role/MSC transitions. Requirements/07_tape_analysis.md documents the protocol. |
| 026 | Are direct 5 V MCU inputs safe throughout power-up, reset and faults? | open | Powered-state FT pins PB14/PB10 remove the MISO/request input translators in the draft. PB11 is spare after removing overrun. HP uses SPI2; SD uses SPI1 at 3.3 V (PA6 is not FT). This avoids the earlier PB4 HP-MISO proposal's reset-state JNTRST pull-up; PB4 handles 3.3 V card detect. ST requires internal pulls disabled above VDD+0.3 V. FT absolute input voltage depends on VDD (VDD+4 V), so a 5 V source is not automatically safe at VDD=0. Analyze supply ramps/reset and CPLD/HCT output states, including raw-VBUS divider injection on PA3; add isolation/protection if necessary. This is electrical validation, not an unresolved translator preference. See requirements/08_pin_mapping.md. |
| 027 | Is the KiCad placement and connector geometry ready for routing/manufacture? | open | The current three-sheet schematic and 64-footprint unrouted board use the simplified 29-signal pin map. CS moved to CPLD pin 41; COMMIT/overrun wiring is removed. Reused HP connector pad geometry is checked against the legacy board; all 348 PCB pad nets match the schematic and ERC is zero. Placement DRC has no shorts, courtyard overlaps or silkscreen collisions, zero parity mismatches, 236 unrouted connections and two clearance violations. The copied USB-C footprint has 0.175 mm adjacent-pad clearance versus the default 0.200 mm rule; agree fabrication rules without changing geometry silently. Finish mechanical/access/outline review, routing and electrical/timing validation before manufacture. |
| 028 | What HP SPI rate meets STM32F103, HCT165 cascade/MISO and CPLD timing? | open | User proposes 24 MHz SPI (0.667 us per word), but ST DS5319 Table 43 limits F103 SPI to 18 MHz. SPI2 on APB1=36 MHz supports 18 MHz /2 or provisional 9 MHz /4 (1.778 us per word). HCT165 timing also matters: S09 at 4.5 V/50 pF, -40..85 C specifies CP-to-Q7 up to 43 ns and DS setup 25 ns; an 18 MHz period is 55.6 ns, shorter than their combined worst-case cascade budget, before skew. MCU MISO setup and half-cycle sampling need their own budget. Start at 9 MHz, budget actual loading/temperature/rails and measure before increasing. RTL/fitter-equation benches pass 9/18/24 MHz only with ideal HCT timing; they do not validate hardware speed. Keep the independent PA8 capture clock at 24 MHz. |
| 029 | Why does the fitter report 65/64 macrocells while declaring a fit, and is the programmed image correct? | open | fit1504 v1918 declares PLCC44 fits, retains pins/JTAG/open-collector outputs and emits JEDEC/VHO/SDF, but its resource summary says 65/64 macrocells and Block D 17/16. The allocation table lists MC1..MC64; both mapped and fitted netlists retain 36 flip-flops, and fitted functional equations pass the HP bench at all three SPI rates. Reconcile the vendor report's accounting with allocated/shared pin/feedback resources and independently inspect/verify the JEDEC/device before hardware sign-off. Functional equation translation uses standard supported primitive semantics without SDF and does not decode fuse programming. Do not treat the reported total as a reliable headroom estimate. |

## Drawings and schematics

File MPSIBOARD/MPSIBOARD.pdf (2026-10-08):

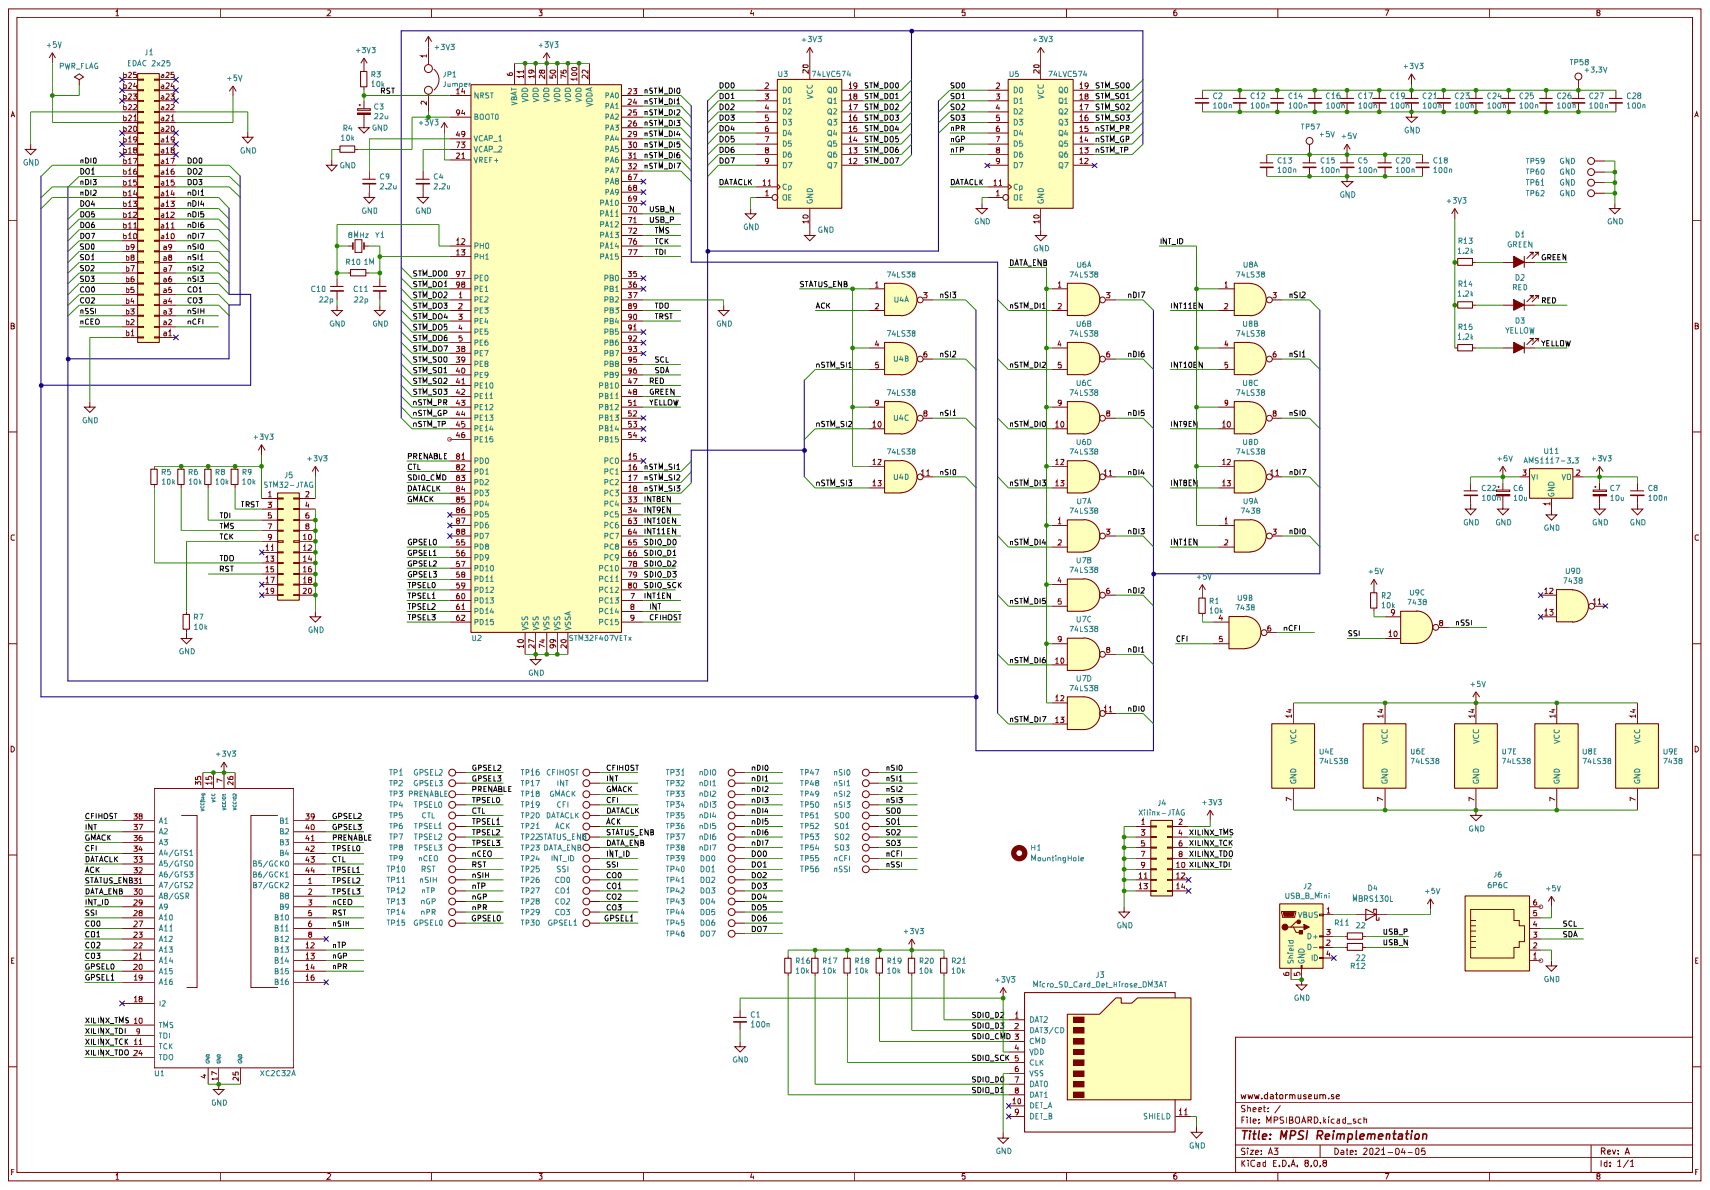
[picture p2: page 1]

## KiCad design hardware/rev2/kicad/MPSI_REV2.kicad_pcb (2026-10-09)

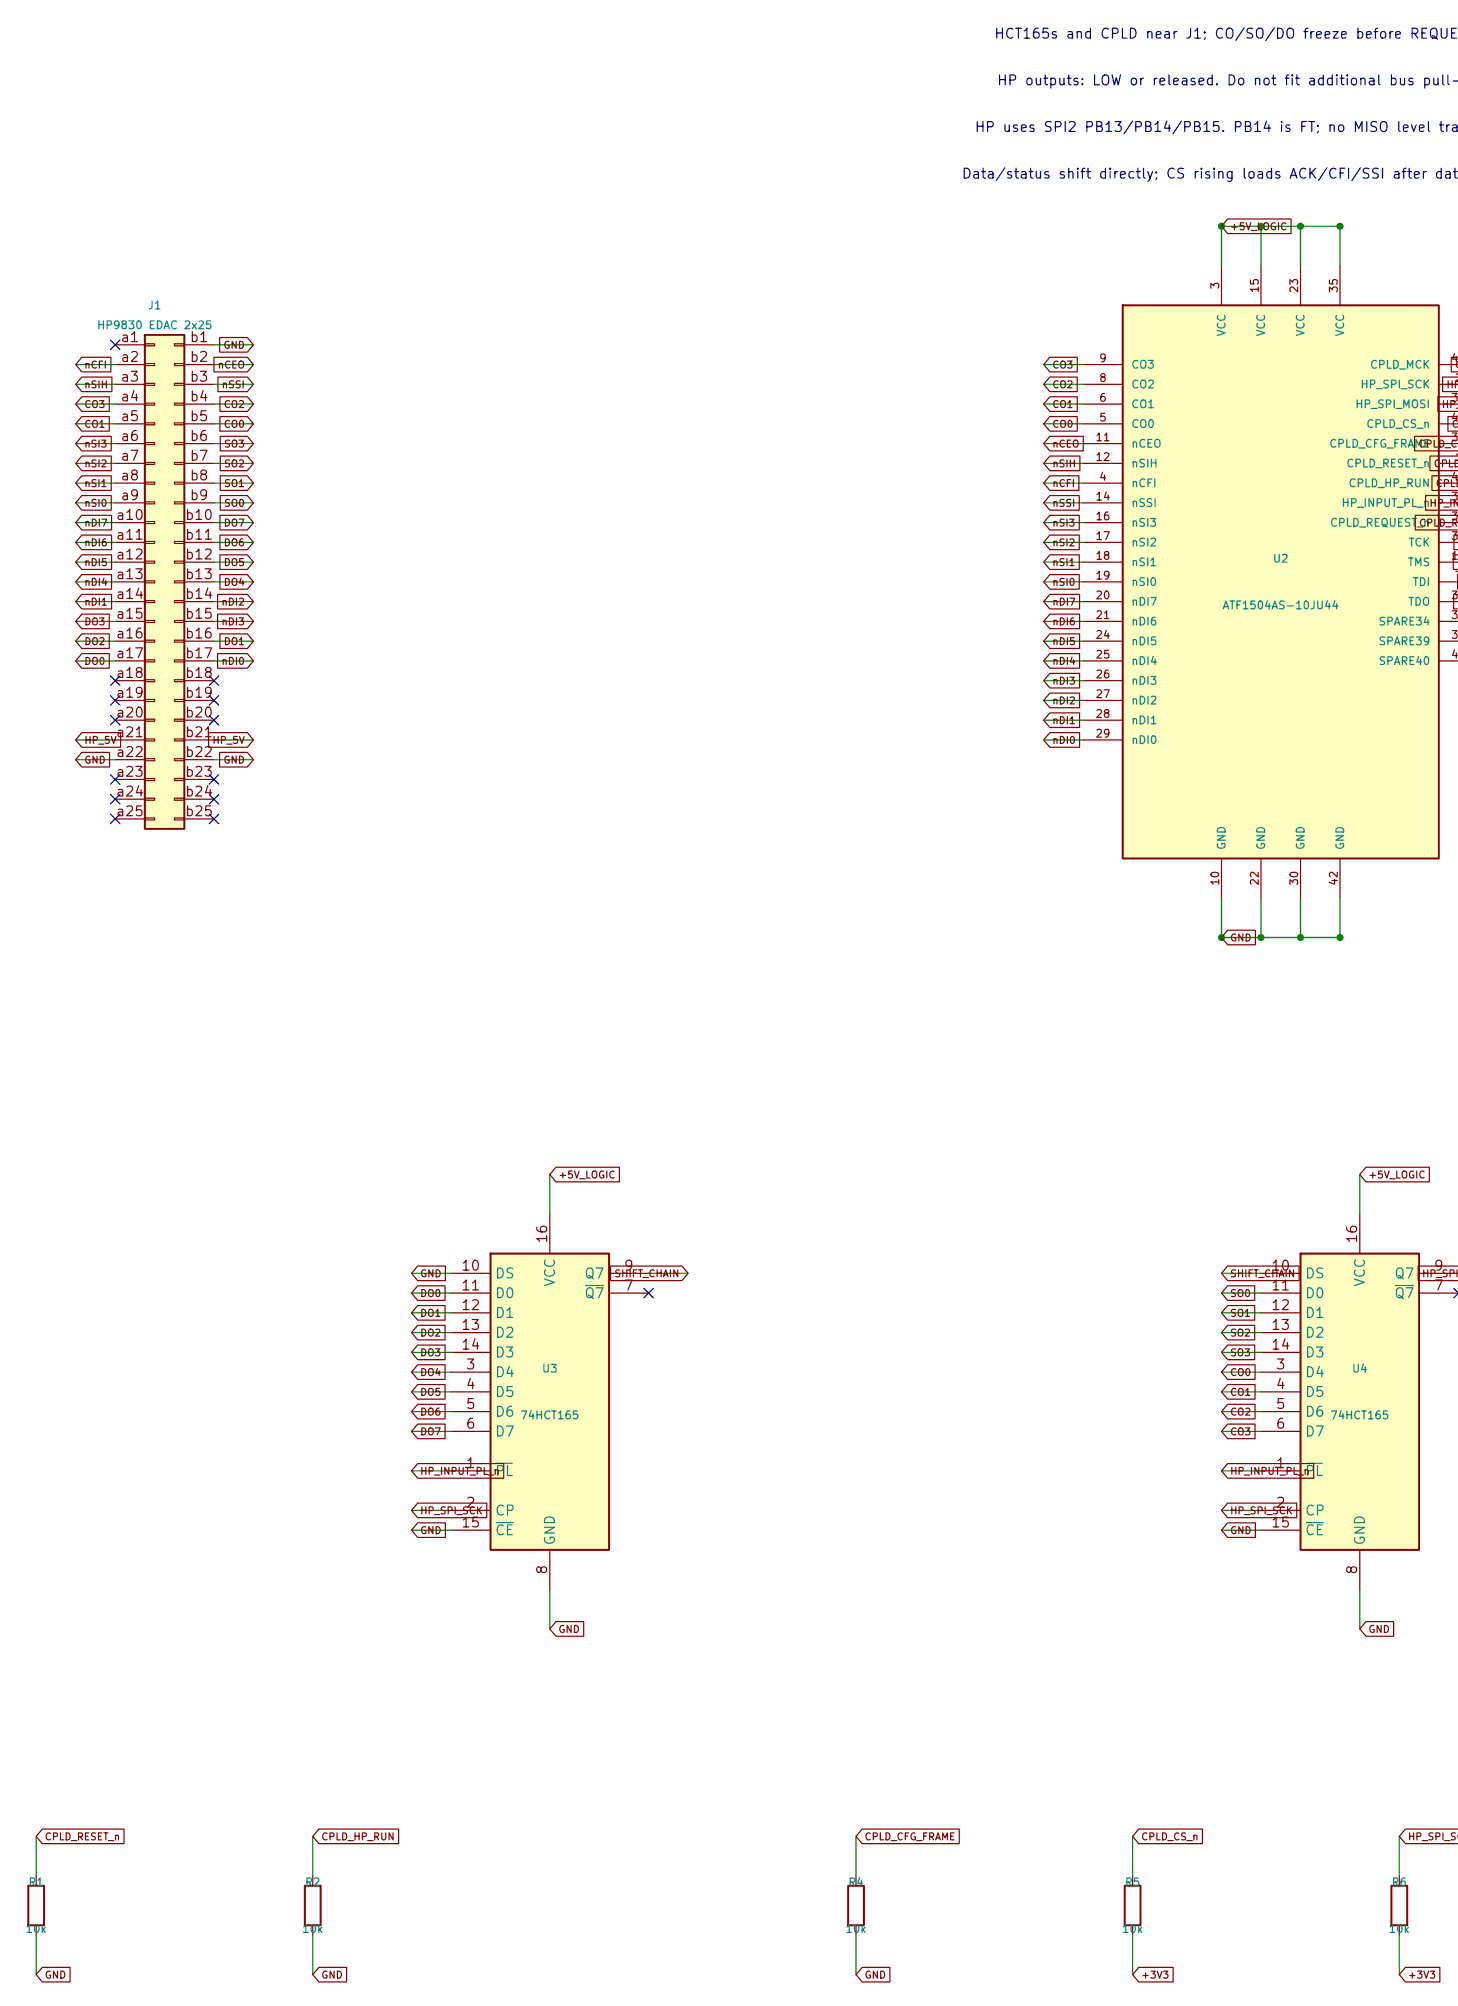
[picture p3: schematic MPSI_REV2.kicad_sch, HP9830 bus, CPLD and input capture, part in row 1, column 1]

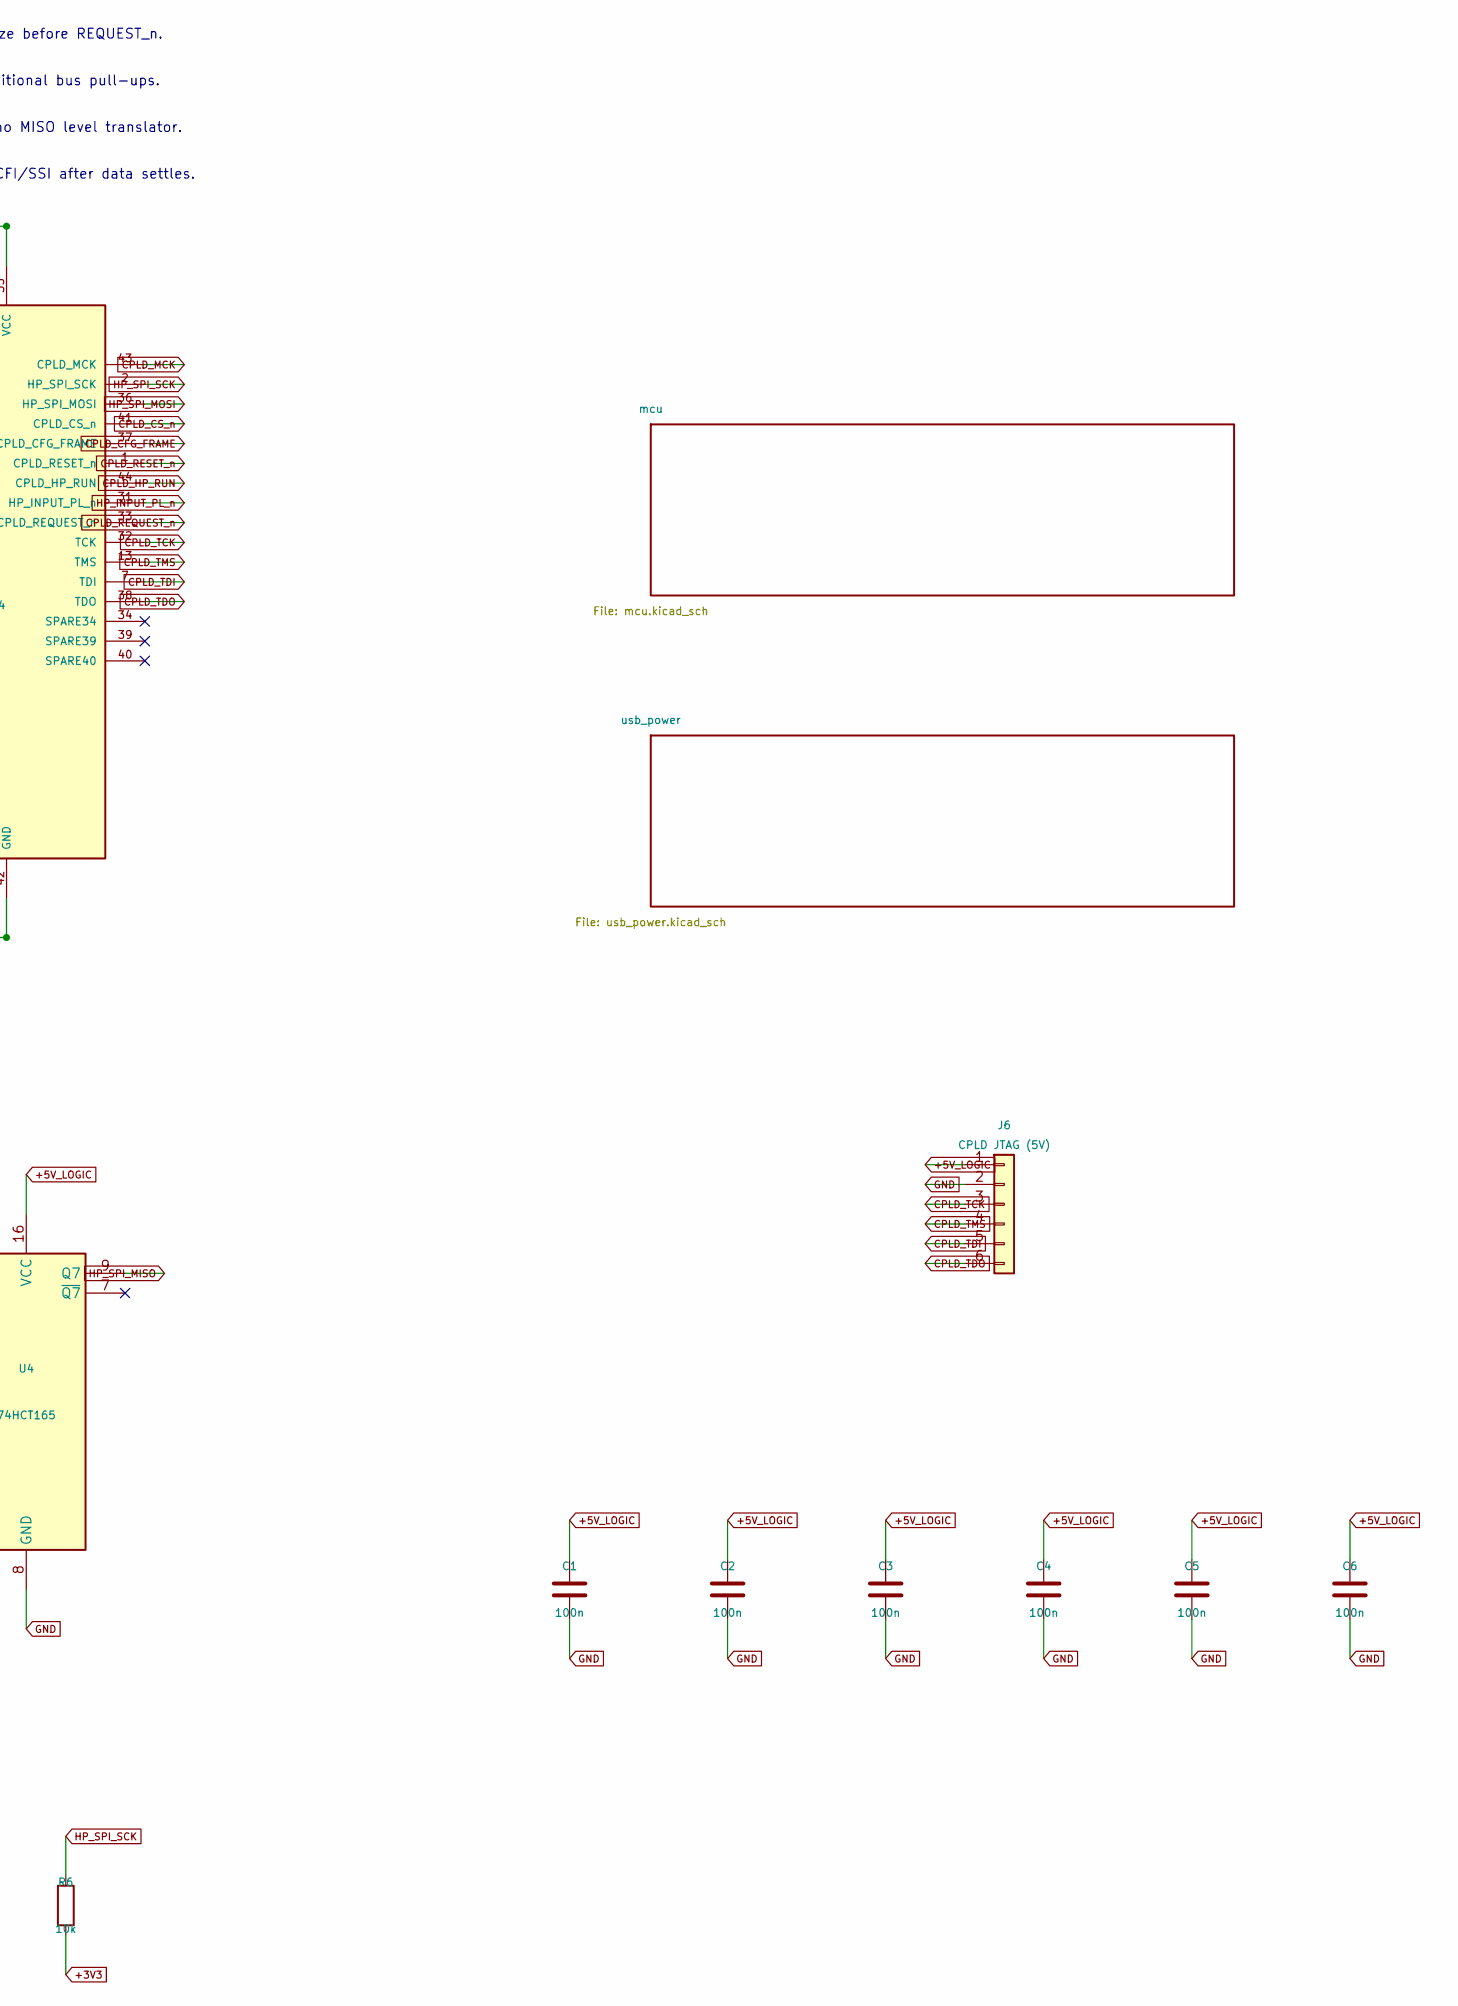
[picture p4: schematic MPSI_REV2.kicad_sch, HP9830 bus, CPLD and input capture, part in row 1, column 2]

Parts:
C1, C2, C3, C4, C5, C6: 100n; C_0603_1608Metric
J1: HP9830 EDAC 2x25; HP9830_EDAC_2x25
J6: CPLD JTAG (5V); PinHeader_1x06_P2.54mm_Vertical
R1, R2, R4, R5, R6: 10k; R_0603_1608Metric
U2: ATF1504AS-10JU44; PLCC-44_16.6x16.6mm_P1.27mm
U3, U4: 74HCT165; SOIC-16_3.9x9.9mm_P1.27mm

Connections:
+3V3: R5.2, R6.2; also elsewhere on the board
+5V_LOGIC: C1.1, C2.1, C3.1, C4.1, C5.1, C6.1, J6.1, U2.3 (VCC), U2.15 (VCC), U2.23 (VCC), U2.35 (VCC), U3.16 (VCC), U4.16 (VCC); also elsewhere on the board
CO0: J1.b5, U2.5 (CO0), U4.3 (D4)
CO1: J1.a5, U2.6 (CO1), U4.4 (D5)
CO2: J1.b4, U2.8 (CO2), U4.5 (D6)
CO3: J1.a4, U2.9 (CO3), U4.6 (D7)
CPLD_CFG_FRAME: R4.1, U2.37 (CPLD_CFG_FRAME); also elsewhere on the board
CPLD_CS_n: R5.1, U2.41 (CPLD_CS_n); also elsewhere on the board
CPLD_HP_RUN: R2.1, U2.44 (CPLD_HP_RUN); also elsewhere on the board
CPLD_MCK: U2.43 (CPLD_MCK); also elsewhere on the board
CPLD_REQUEST_n: U2.33 (CPLD_REQUEST_n); also elsewhere on the board
CPLD_RESET_n: R1.1, U2.1 (CPLD_RESET_n); also elsewhere on the board
CPLD_TCK: J6.3, U2.32 (TCK)
CPLD_TDI: J6.5, U2.7 (TDI)
CPLD_TDO: J6.6, U2.38 (TDO)
CPLD_TMS: J6.4, U2.13 (TMS)
DO0: J1.a17, U3.11 (D0)
DO1: J1.b16, U3.12 (D1)
DO2: J1.a16, U3.13 (D2)
DO3: J1.a15, U3.14 (D3)
DO4: J1.b13, U3.3 (D4)
DO5: J1.b12, U3.4 (D5)
DO6: J1.b11, U3.5 (D6)
DO7: J1.b10, U3.6 (D7)
GND: C1.2, C2.2, C3.2, C4.2, C5.2, C6.2, J1.a22, J1.b1, J1.b22, J6.2, R1.2, R2.2, R4.2, U2.10 (GND), U2.22 (GND), U2.30 (GND), U2.42 (GND), U3.8 (GND), U3.10 (DS), U3.15 (~CE), U4.8 (GND), U4.15 (~CE); also elsewhere on the board
HP_5V: J1.a21, J1.b21; also elsewhere on the board
HP_INPUT_PL_n: U2.31 (HP_INPUT_PL_n), U3.1 (~PL), U4.1 (~PL)
HP_SPI_MISO: U4.9 (Q7); also elsewhere on the board
HP_SPI_MOSI: U2.36 (HP_SPI_MOSI); also elsewhere on the board
HP_SPI_SCK: R6.1, U2.2 (HP_SPI_SCK), U3.2 (CP), U4.2 (CP); also elsewhere on the board
SHIFT_CHAIN: U3.9 (Q7), U4.10 (DS)
SO0: J1.b9, U4.11 (D0)
SO1: J1.b8, U4.12 (D1)
SO2: J1.b7, U4.13 (D2)
SO3: J1.b6, U4.14 (D3)
nCEO: J1.b2, U2.11 (nCEO)
nCFI: J1.a2, U2.4 (nCFI)
nDI0: J1.b17, U2.29 (nDI0)
nDI1: J1.a14, U2.28 (nDI1)
nDI2: J1.b14, U2.27 (nDI2)
nDI3: J1.b15, U2.26 (nDI3)
nDI4: J1.a13, U2.25 (nDI4)
nDI5: J1.a12, U2.24 (nDI5)
nDI6: J1.a11, U2.21 (nDI6)
nDI7: J1.a10, U2.20 (nDI7)
nSI0: J1.a9, U2.19 (nSI0)
nSI1: J1.a8, U2.18 (nSI1)
nSI2: J1.a7, U2.17 (nSI2)
nSI3: J1.a6, U2.16 (nSI3)
nSIH: J1.a3, U2.12 (nSIH)
nSSI: J1.b3, U2.14 (nSSI)

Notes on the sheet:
HCT165s and CPLD near J1; CO/SO/DO freeze before REQUEST_n.
HP outputs: LOW or released. Do not fit additional bus pull-ups.
HP uses SPI2 PB13/PB14/PB15. PB14 is FT; no MISO level translator.
Data/status shift directly; CS rising loads ACK/CFI/SSI after data settles.

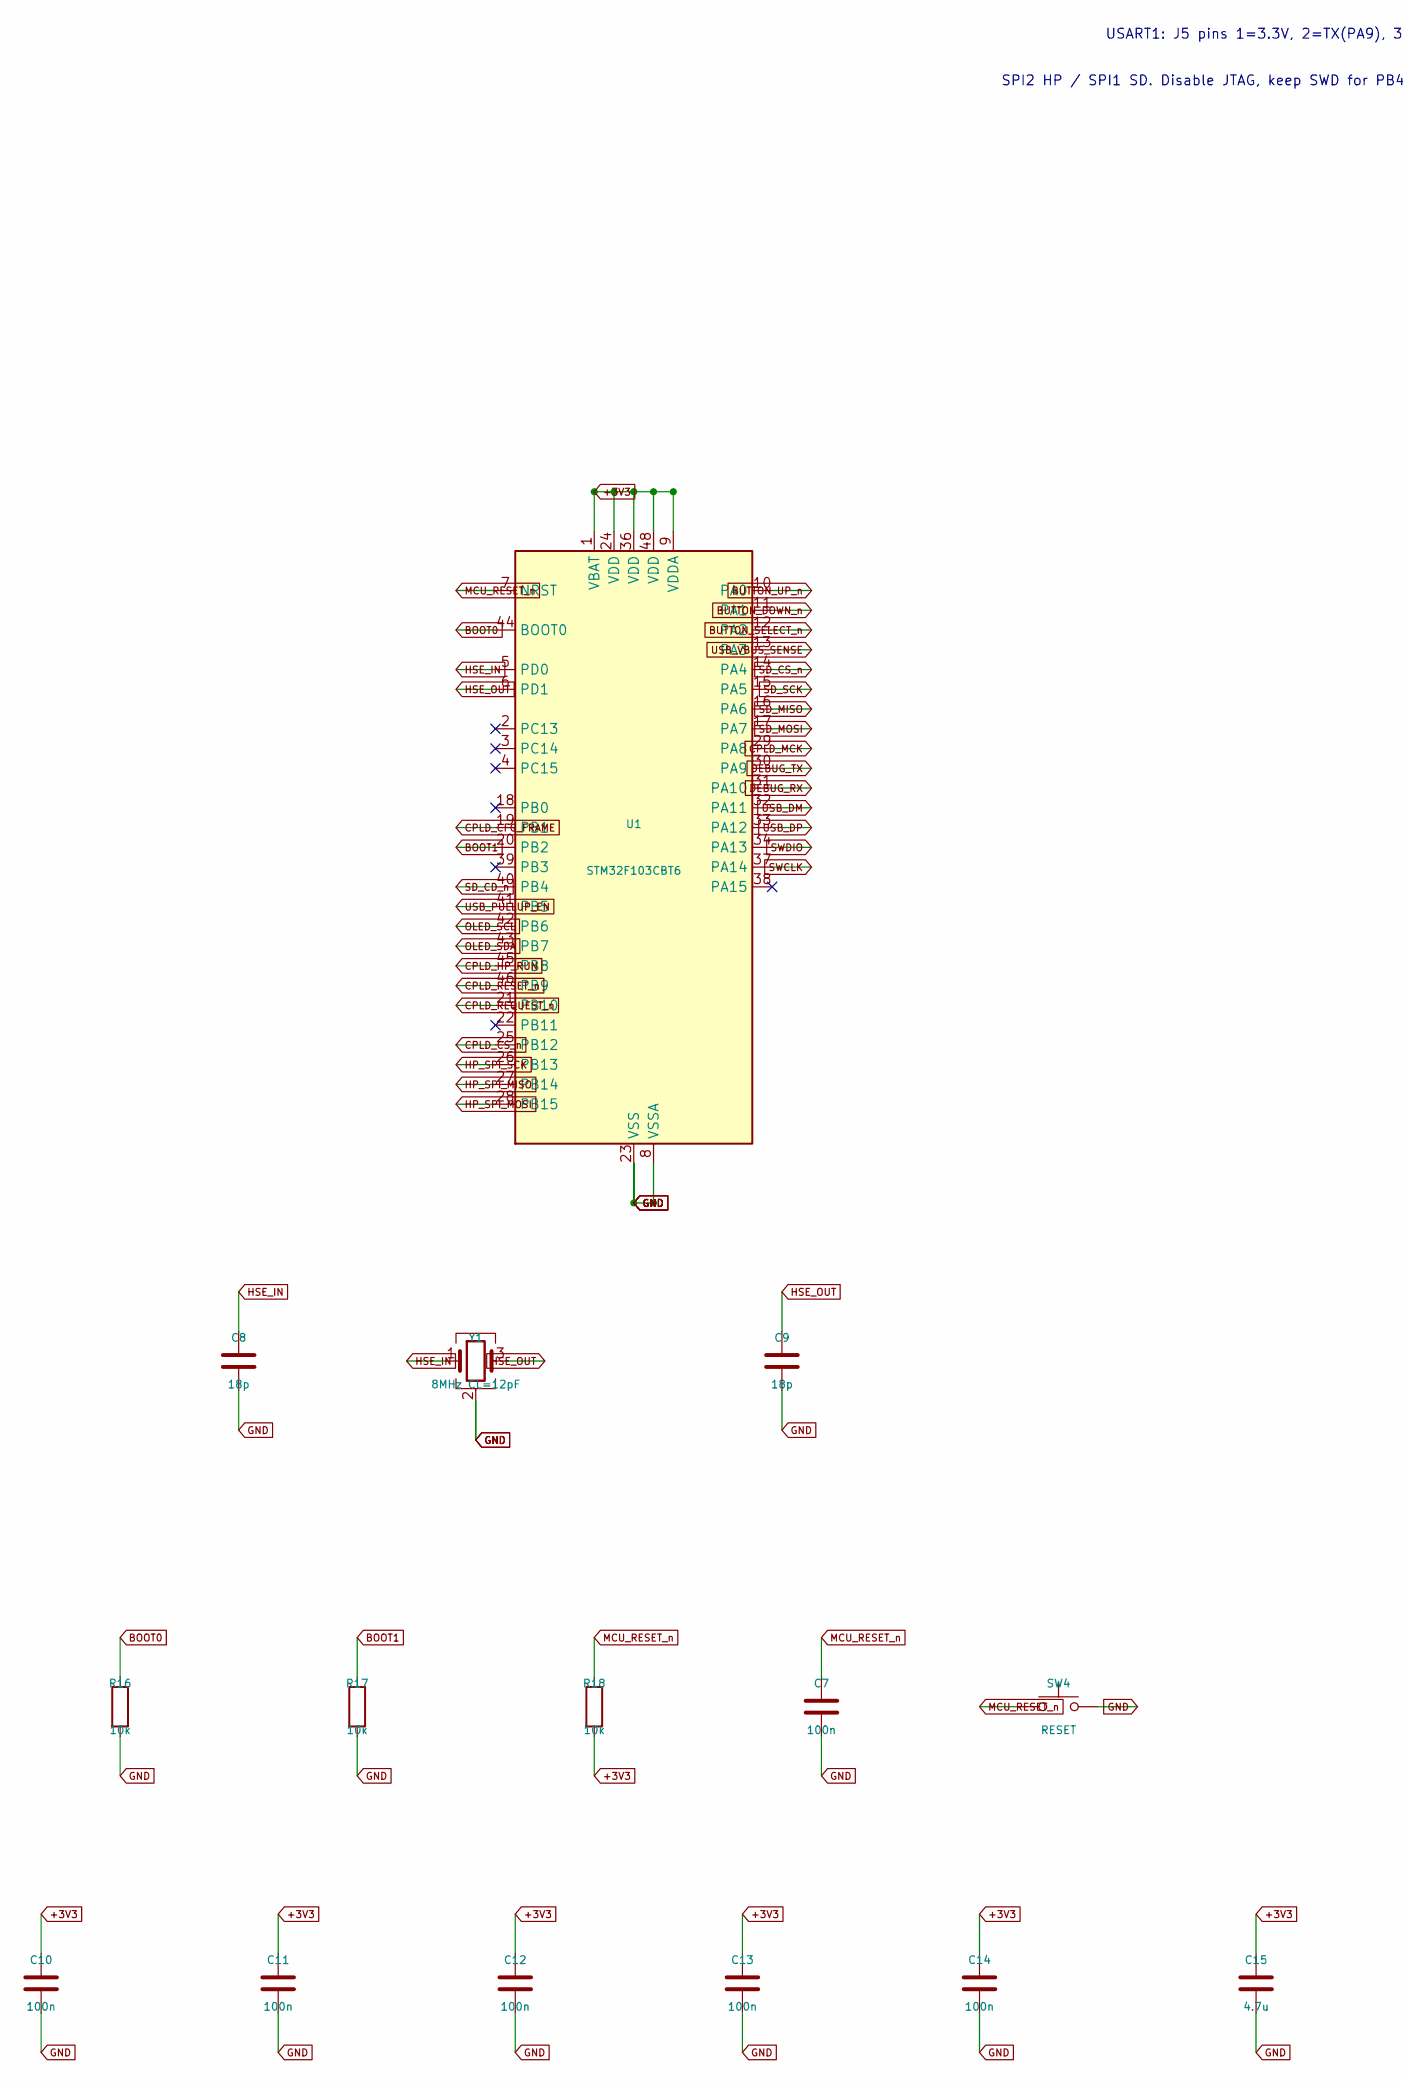
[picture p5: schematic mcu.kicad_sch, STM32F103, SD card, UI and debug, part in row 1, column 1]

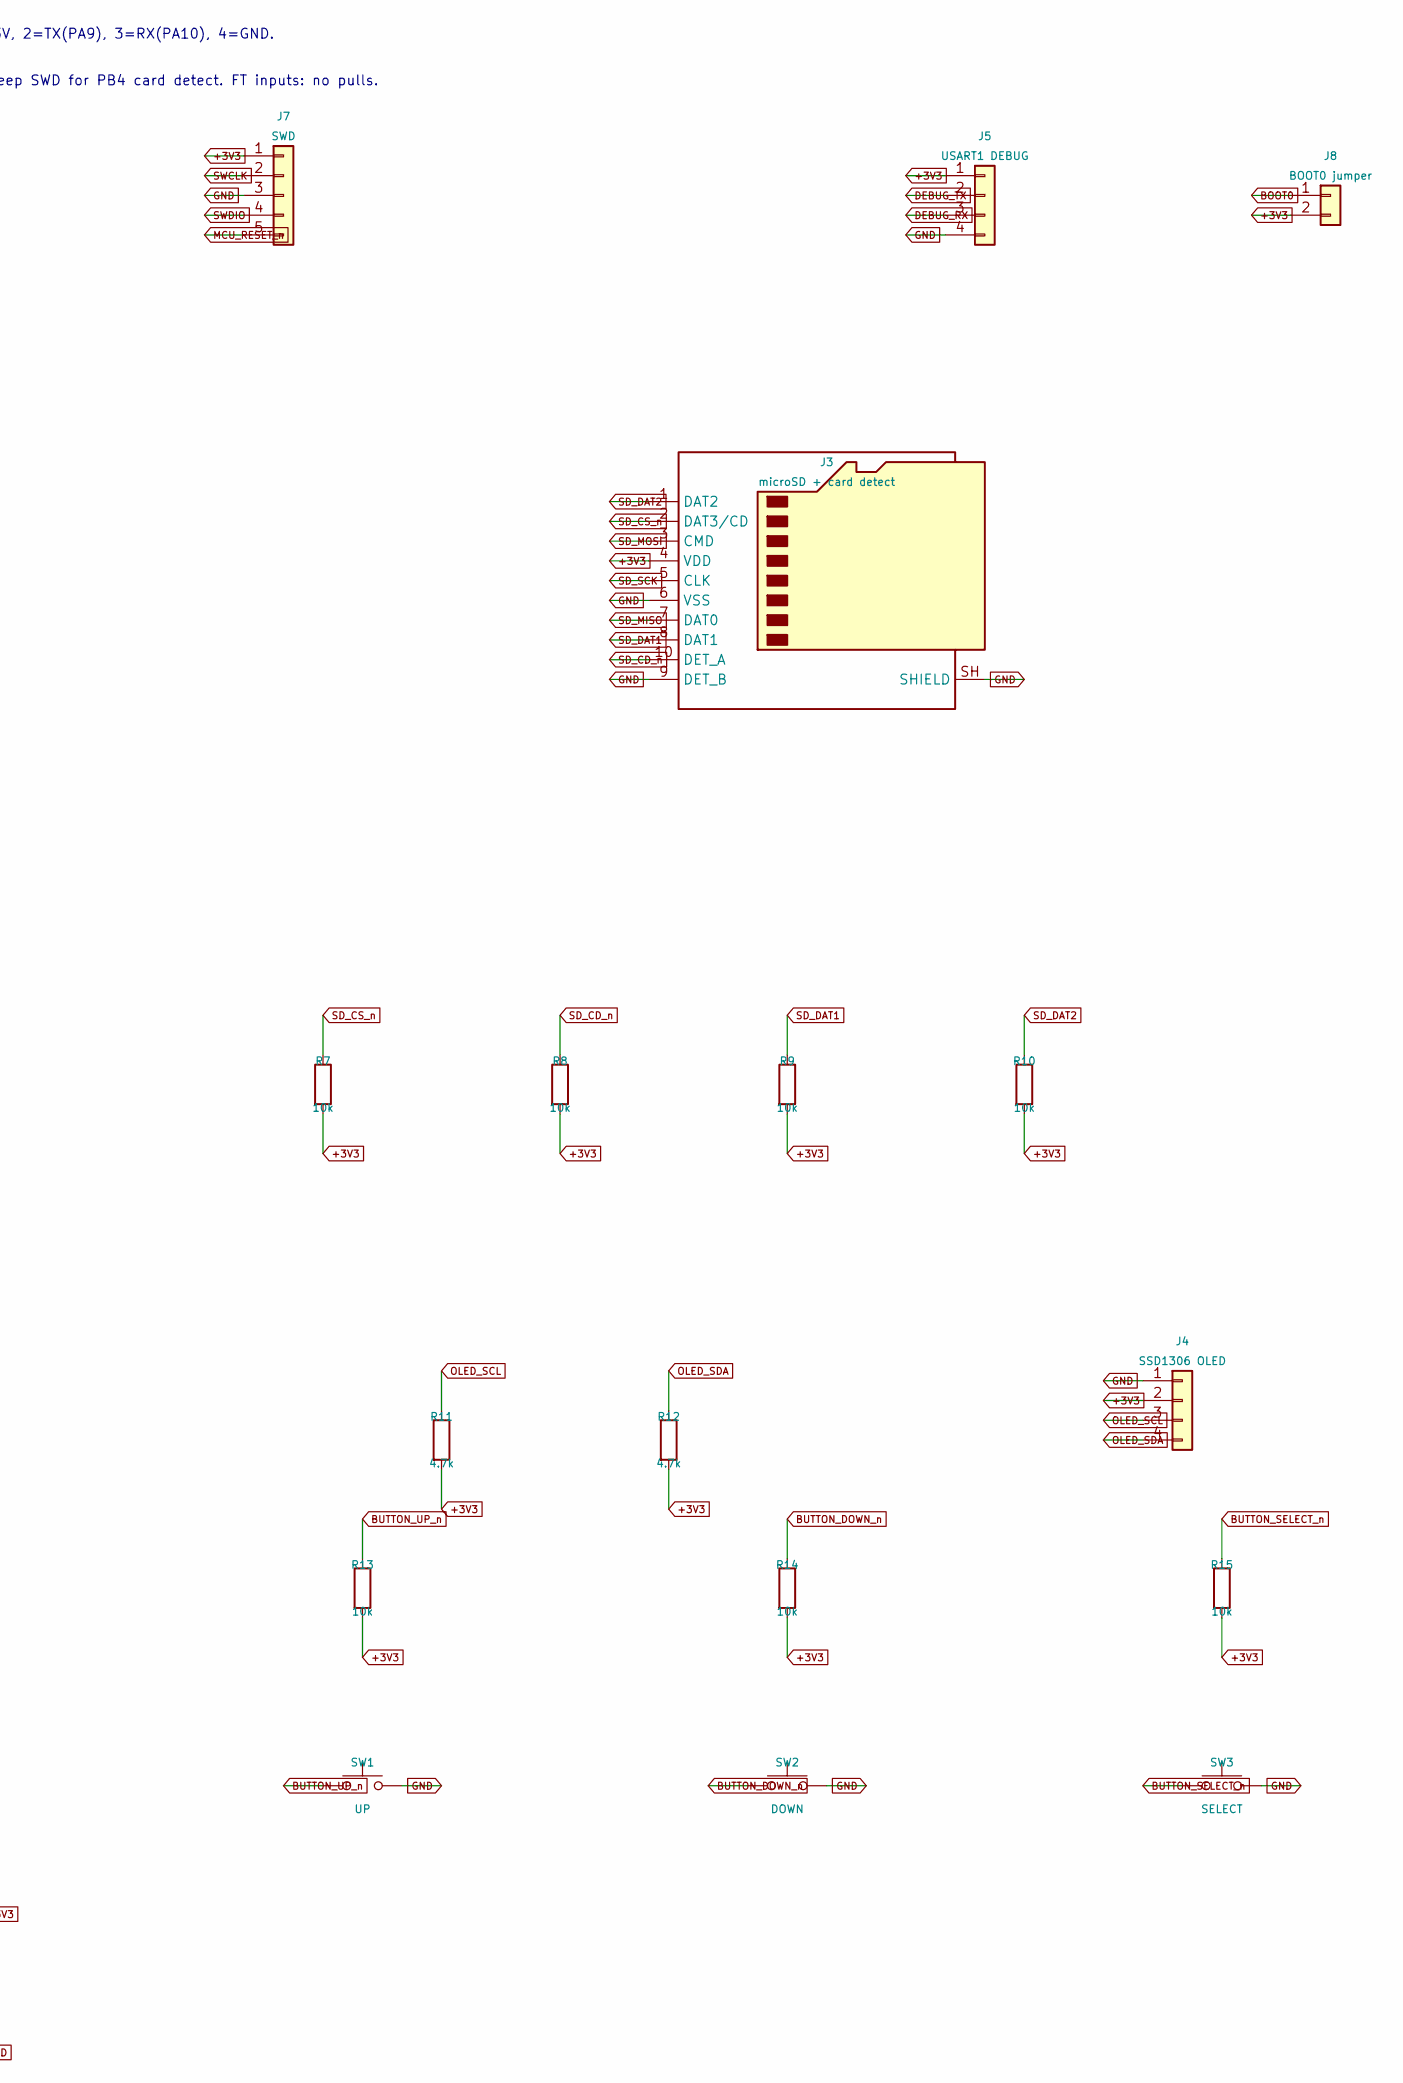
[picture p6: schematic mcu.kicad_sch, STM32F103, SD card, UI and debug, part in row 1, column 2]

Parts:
C7, C10, C11, C12, C13, C14: 100n; C_0603_1608Metric
C8, C9: 18p; C_0603_1608Metric
C15: 4.7u; C_0603_1608Metric
J3: microSD + card detect; microSD_HC_Hirose_DM3AT-SF-PEJM5
J4: SSD1306 OLED; PinHeader_1x04_P2.54mm_Vertical
J5: USART1 DEBUG; PinHeader_1x04_P2.54mm_Vertical
J7: SWD; PinHeader_1x05_P2.54mm_Vertical
J8: BOOT0 jumper; PinHeader_1x02_P2.54mm_Vertical
R7, R8, R9, R10, R13, R14, R15, R16, R17, R18: 10k; R_0603_1608Metric
R11, R12: 4.7k; R_0603_1608Metric
SW1: UP; SW_PUSH_6mm_H5mm
SW2: DOWN; SW_PUSH_6mm_H5mm
SW3: SELECT; SW_PUSH_6mm_H5mm
SW4: RESET; SW_PUSH_6mm_H5mm
U1: STM32F103CBT6; LQFP-48_7x7mm_P0.5mm
Y1: 8MHz CL=12pF; Crystal_SMD_3225-4Pin_3.2x2.5mm

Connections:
+3V3: C10.1, C11.1, C12.1, C13.1, C14.1, C15.1, J3.4 (VDD), J4.2, J5.1, J7.1, J8.2, R7.2, R8.2, R9.2, R10.2, R11.2, R12.2, R13.2, R14.2, R15.2, R18.2, U1.1 (VBAT), U1.9 (VDDA), U1.24 (VDD), U1.36 (VDD), U1.48 (VDD); also elsewhere on the board
BOOT0: J8.1, R16.1, U1.44 (BOOT0)
BOOT1: R17.1, U1.20 (PB2)
BUTTON_DOWN_n: R14.1, SW2.1, U1.11 (PA1)
BUTTON_SELECT_n: R15.1, SW3.1, U1.12 (PA2)
BUTTON_UP_n: R13.1, SW1.1, U1.10 (PA0)
CPLD_CFG_FRAME: U1.19 (PB1); also elsewhere on the board
CPLD_CS_n: U1.25 (PB12); also elsewhere on the board
CPLD_HP_RUN: U1.45 (PB8); also elsewhere on the board
CPLD_MCK: U1.29 (PA8); also elsewhere on the board
CPLD_REQUEST_n: U1.21 (PB10); also elsewhere on the board
CPLD_RESET_n: U1.46 (PB9); also elsewhere on the board
DEBUG_RX: J5.3, U1.31 (PA10)
DEBUG_TX: J5.2, U1.30 (PA9)
GND: C7.2, C8.2, C9.2, C10.2, C11.2, C12.2, C13.2, C14.2, C15.2, J3.6 (VSS), J3.9 (DET_B), J3.SH (SHIELD), J4.1, J5.4, J7.3, R16.2, R17.2, SW1.2, SW2.2, SW3.2, SW4.2, U1.8 (VSSA), U1.23 (VSS), U1.35 (VSS), U1.47 (VSS), Y1.2 (G), Y1.4 (G); also elsewhere on the board
HP_SPI_MISO: U1.27 (PB14); also elsewhere on the board
HP_SPI_MOSI: U1.28 (PB15); also elsewhere on the board
HP_SPI_SCK: U1.26 (PB13); also elsewhere on the board
HSE_IN: C8.1, U1.5 (PD0), Y1.1
HSE_OUT: C9.1, U1.6 (PD1), Y1.3
MCU_RESET_n: C7.1, J7.5, R18.1, SW4.1, U1.7 (NRST)
OLED_SCL: J4.3, R11.1, U1.42 (PB6)
OLED_SDA: J4.4, R12.1, U1.43 (PB7)
SD_CD_n: J3.10 (DET_A), R8.1, U1.40 (PB4)
SD_CS_n: J3.2 (DAT3/CD), R7.1, U1.14 (PA4)
SD_DAT1: J3.8 (DAT1), R9.1
SD_DAT2: J3.1 (DAT2), R10.1
SD_MISO: J3.7 (DAT0), U1.16 (PA6)
SD_MOSI: J3.3 (CMD), U1.17 (PA7)
SD_SCK: J3.5 (CLK), U1.15 (PA5)
SWCLK: J7.2, U1.37 (PA14)
SWDIO: J7.4, U1.34 (PA13)
USB_DM: U1.32 (PA11); also elsewhere on the board
USB_DP: U1.33 (PA12); also elsewhere on the board
USB_PULLUP_EN: U1.41 (PB5); also elsewhere on the board
USB_VBUS_SENSE: U1.13 (PA3); also elsewhere on the board

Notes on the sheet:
USART1: J5 pins 1=3.3V, 2=TX(PA9), 3=RX(PA10), 4=GND.
SPI2 HP / SPI1 SD. Disable JTAG, keep SWD for PB4 card detect. FT inputs: no pulls.

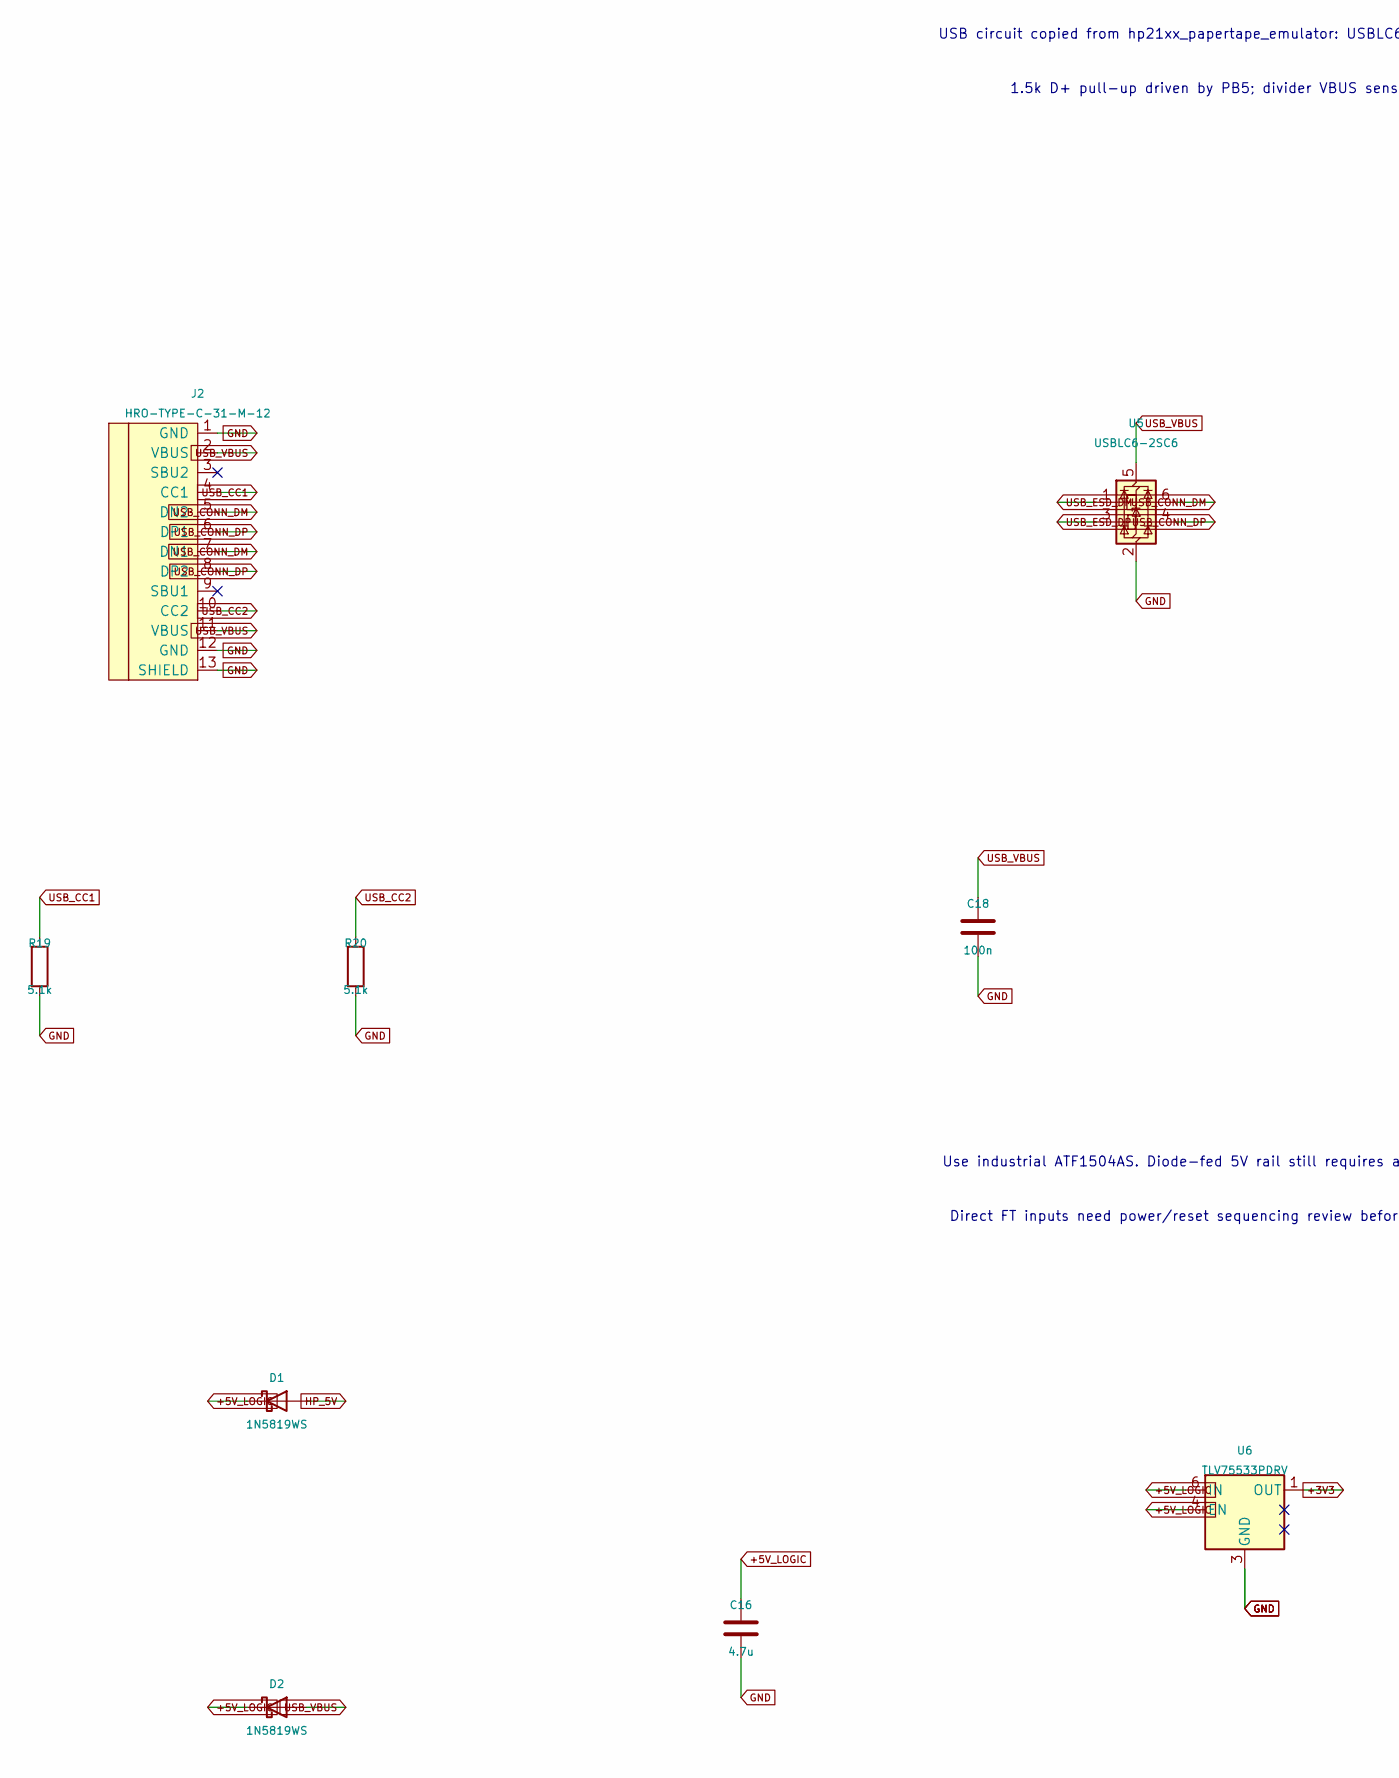
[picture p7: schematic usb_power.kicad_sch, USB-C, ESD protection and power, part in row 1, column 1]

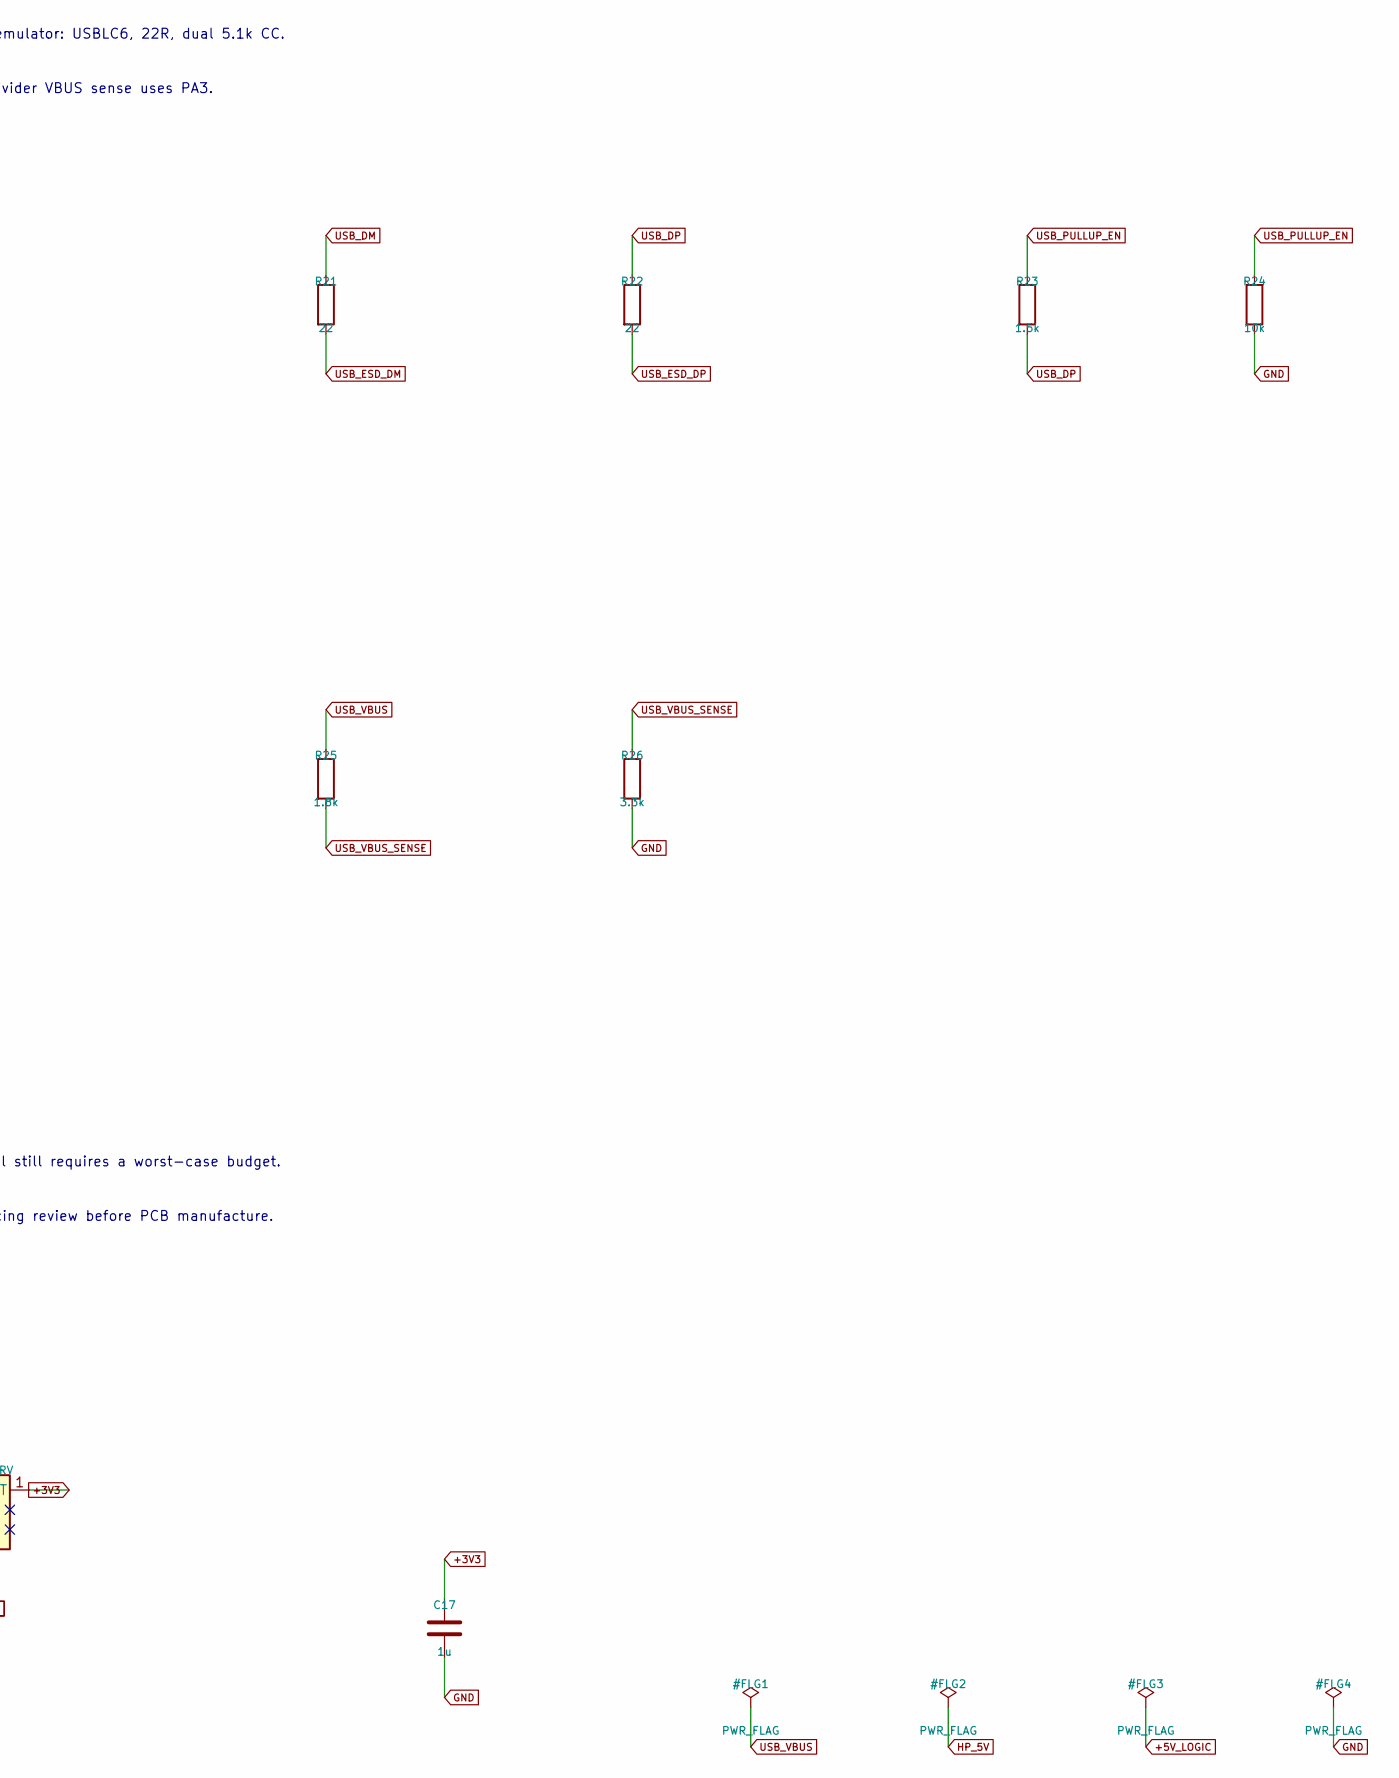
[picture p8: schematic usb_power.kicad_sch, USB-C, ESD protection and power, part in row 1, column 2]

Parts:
C16: 4.7u; C_0603_1608Metric
C17: 1u; C_0603_1608Metric
C18: 100n; C_0603_1608Metric
D1, D2: 1N5819WS; D_SOD-323
J2: HRO-TYPE-C-31-M-12
R19, R20: 5.1k; R_0603_1608Metric
R21, R22: 22; R_0603_1608Metric
R23: 1.5k; R_0603_1608Metric
R24: 10k; R_0603_1608Metric
R25: 1.8k; R_0603_1608Metric
R26: 3.3k; R_0603_1608Metric
U5: USBLC6-2SC6; SOT-23-6
U6: TLV75533PDRV; WSON-6-1EP_2x2mm_P0.65mm_EP1x1.6mm

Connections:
+3V3: C17.1, U6.1 (OUT); also elsewhere on the board
+5V_LOGIC: C16.1, D1.1 (K), D2.1 (K), U6.4 (EN), U6.6 (IN); also elsewhere on the board
GND: C16.2, C17.2, C18.2, J2.1 (GND), J2.12 (GND), J2.13 (SHIELD), R19.2, R20.2, R24.2, R26.2, U5.2 (GND), U6.3 (GND), U6.7 (GND); also elsewhere on the board
HP_5V: D1.2 (A); also elsewhere on the board
USB_CC1: J2.4 (CC1), R19.1
USB_CC2: J2.10 (CC2), R20.1
USB_CONN_DM: J2.5 (DN2), J2.7 (DN1), U5.6 (I/O1)
USB_CONN_DP: J2.6 (DP1), J2.8 (DP2), U5.4 (I/O2)
USB_DM: R21.1; also elsewhere on the board
USB_DP: R22.1, R23.2; also elsewhere on the board
USB_ESD_DM: R21.2, U5.1 (I/O1)
USB_ESD_DP: R22.2, U5.3 (I/O2)
USB_PULLUP_EN: R23.1, R24.1; also elsewhere on the board
USB_VBUS: C18.1, D2.2 (A), J2.2 (VBUS), J2.11 (VBUS), R25.1, U5.5 (VBUS)
USB_VBUS_SENSE: R25.2, R26.1; also elsewhere on the board

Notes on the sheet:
USB circuit copied from hp21xx_papertape_emulator: USBLC6, 22R, dual 5.1k CC.
1.5k D+ pull-up driven by PB5; divider VBUS sense uses PA3.
Use industrial ATF1504AS. Diode-fed 5V rail still requires a worst-case budget.
Direct FT inputs need power/reset sequencing review before PCB manufacture.

Board: 2 copper layers, 64 parts (0 on the bottom side), 83 nets, no tracks yet.

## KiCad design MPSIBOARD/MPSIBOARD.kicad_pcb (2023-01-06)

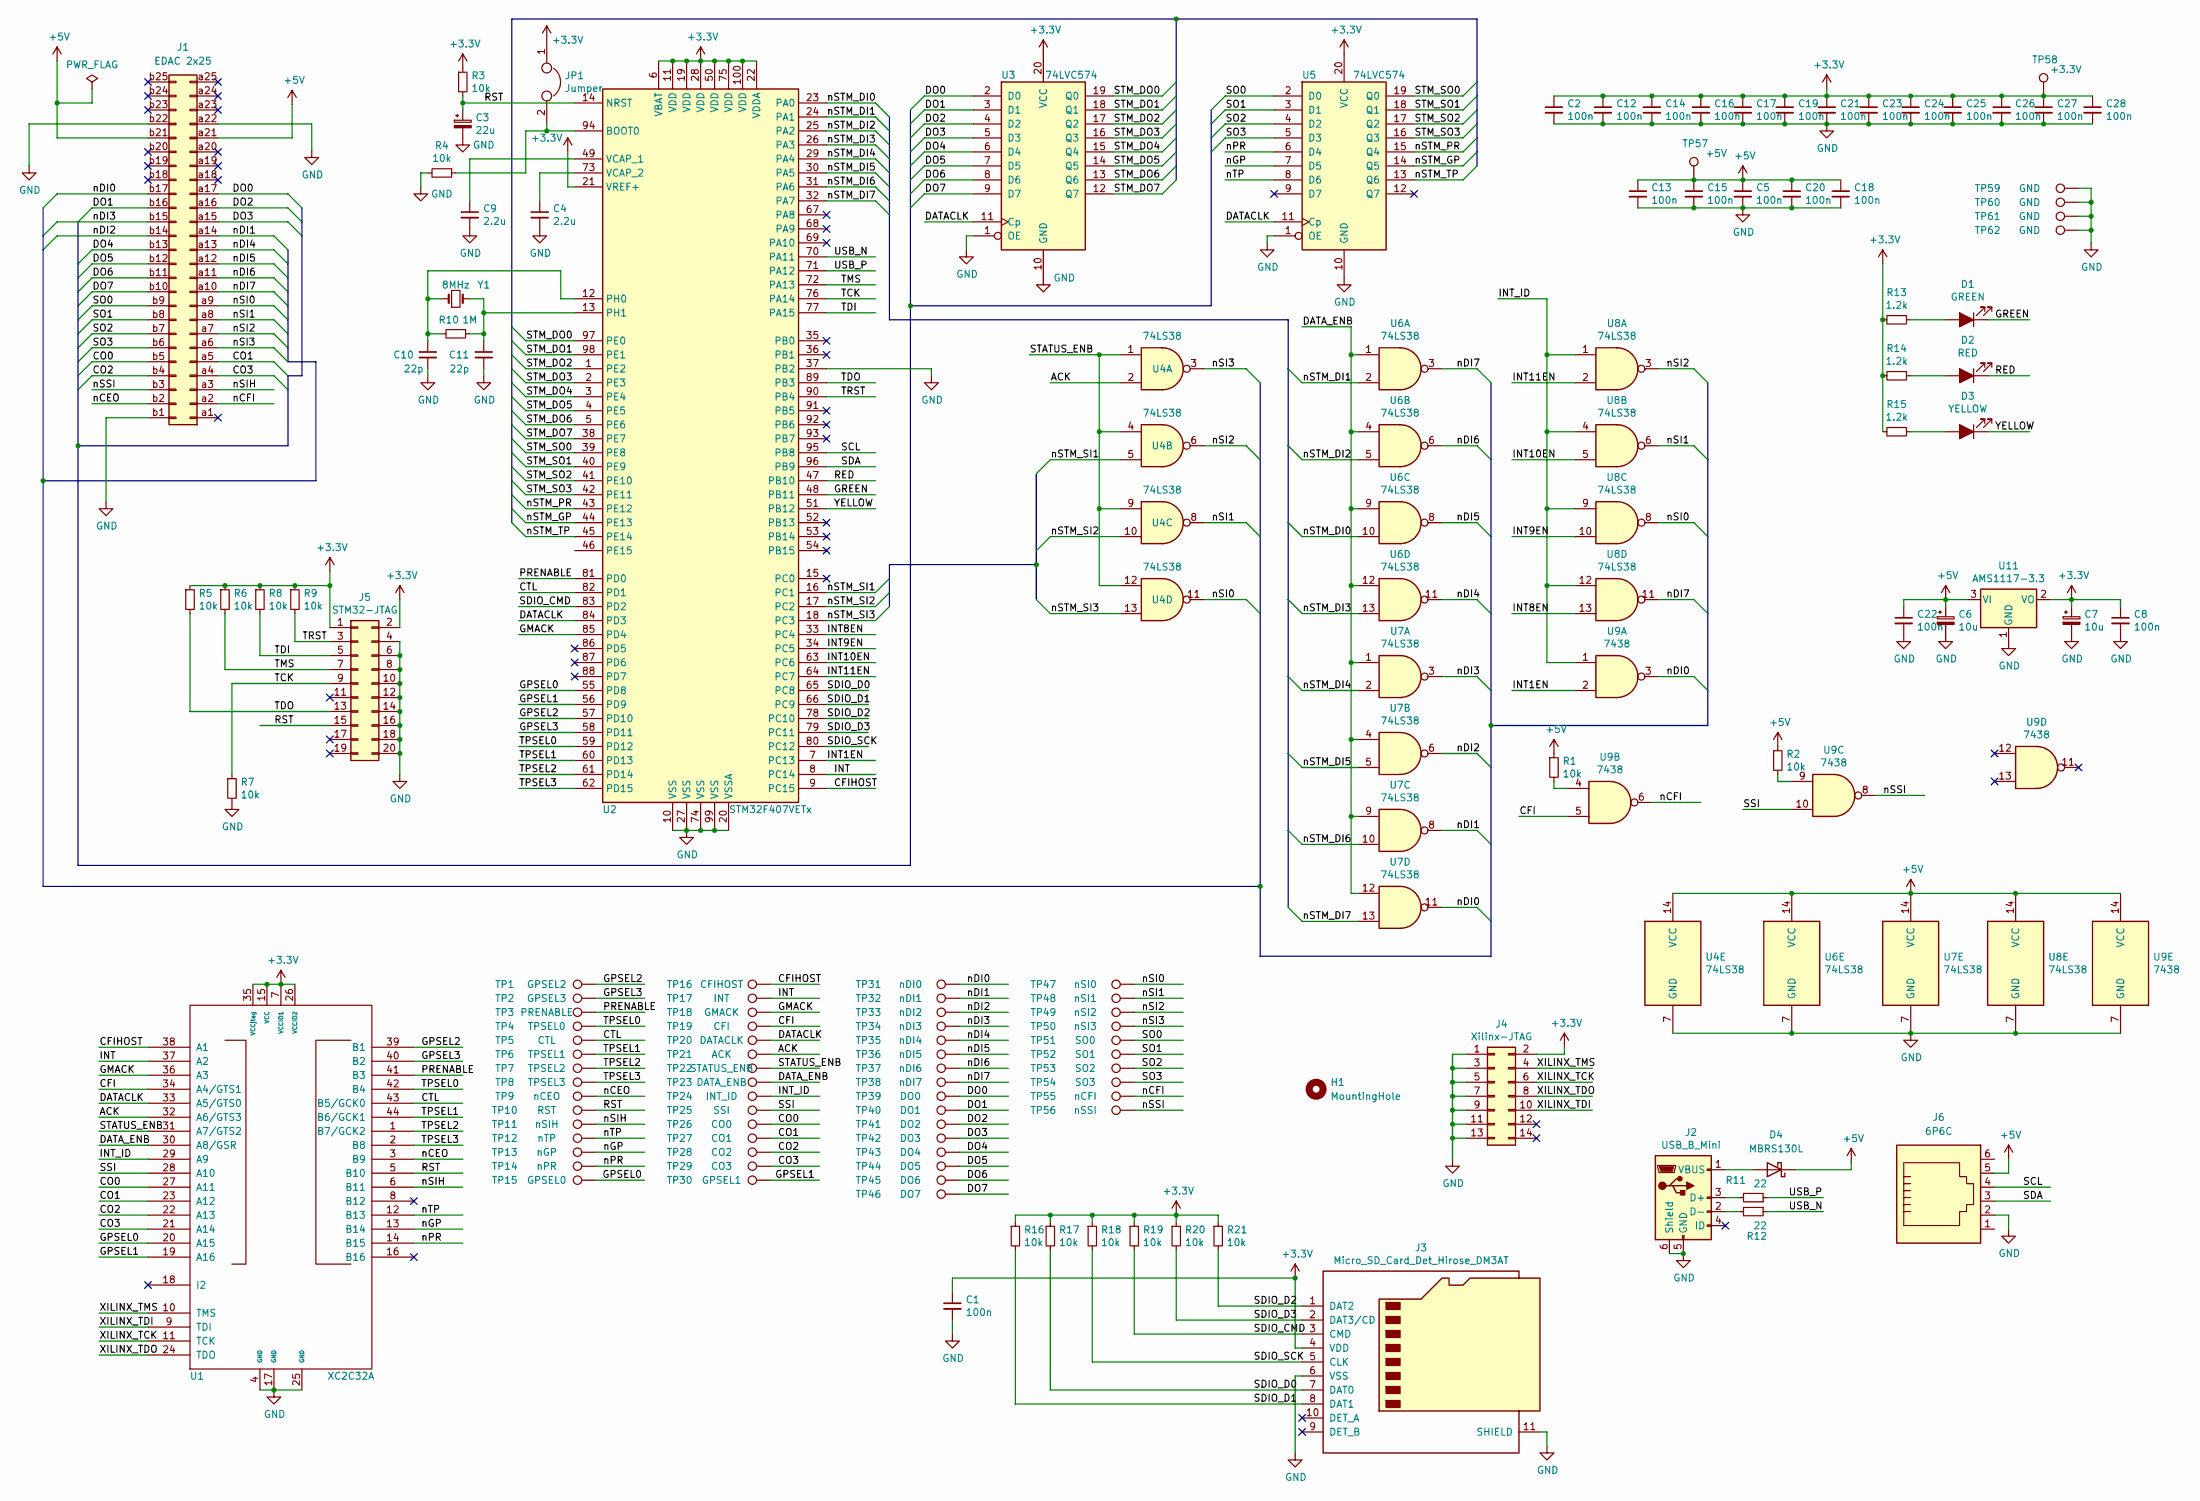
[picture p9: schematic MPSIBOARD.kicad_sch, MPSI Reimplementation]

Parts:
C1, C2, C5, C8, C12, C13, C14, C15, C16, C17, C18, C19, C20, C21, C22, C23, C24, C25, C26, C27, C28: 100n; C_0805_2012Metric
C3: 22u; CP_Elec_5x4.4
C4, C9: 2.2u; C_0805_2012Metric
C6, C7: 10u; CP_Elec_4x5.3
C10, C11: 22p; C_0805_2012Metric
D1: GREEN; LED_0805_2012Metric
D2: RED; LED_0805_2012Metric
D3: YELLOW; LED_0805_2012Metric
D4: MBRS130L; D_SMB
H1: MountingHole; MountingHole_3.2mm_M3
J1: EDAC 2x25; EDAC 2x25 3.96mm
J2: USB_B_Mini; USB_Mini-B_Lumberg_2486_01_Horizontal
J3: Micro_SD_Card_Det_Hirose_DM3AT; microSD_HC_Hirose_DM3AT-SF-PEJM5
J4: Xilinx-JTAG; IDC-Header_2x07_P2.54mm_Vertical
J5: STM32-JTAG; IDC-Header_2x10_P2.54mm_Vertical
J6: 6P6C; RJ12_Amphenol_54601
JP1: Jumper; PinHeader_1x02_P2.54mm_Vertical
R1, R2, R3, R4, R5, R6, R7, R8, R9, R16, R17, R18, R19, R20, R21: 10k; R_0805_2012Metric
R10: 1M; R_0805_2012Metric
R11, R12: 22; R_0805_2012Metric
R13, R14, R15: 1.2k; R_0805_2012Metric
TP1: GPSEL2; PinHeader_1x01_P2.54mm_Vertical
TP2: GPSEL3; PinHeader_1x01_P2.54mm_Vertical
TP3: PRENABLE; PinHeader_1x01_P2.54mm_Vertical
TP4: TPSEL0; PinHeader_1x01_P2.54mm_Vertical
TP5: CTL; PinHeader_1x01_P2.54mm_Vertical
TP6: TPSEL1; PinHeader_1x01_P2.54mm_Vertical
TP7: TPSEL2; PinHeader_1x01_P2.54mm_Vertical
TP8: TPSEL3; PinHeader_1x01_P2.54mm_Vertical
TP9: nCEO; PinHeader_1x01_P2.54mm_Vertical
TP10: RST; PinHeader_1x01_P2.54mm_Vertical
TP11: nSIH; PinHeader_1x01_P2.54mm_Vertical
TP12: nTP; PinHeader_1x01_P2.54mm_Vertical
TP13: nGP; PinHeader_1x01_P2.54mm_Vertical
TP14: nPR; PinHeader_1x01_P2.54mm_Vertical
TP15: GPSEL0; PinHeader_1x01_P2.54mm_Vertical
TP16: CFIHOST; PinHeader_1x01_P2.54mm_Vertical
TP17: INT; PinHeader_1x01_P2.54mm_Vertical
TP18: GMACK; PinHeader_1x01_P2.54mm_Vertical
TP19: CFI; PinHeader_1x01_P2.54mm_Vertical
TP20: DATACLK; PinHeader_1x01_P2.54mm_Vertical
TP21: ACK; PinHeader_1x01_P2.54mm_Vertical
TP22: STATUS_ENB; PinHeader_1x01_P2.54mm_Vertical
TP23: DATA_ENB; PinHeader_1x01_P2.54mm_Vertical
TP24: INT_ID; PinHeader_1x01_P2.54mm_Vertical
TP25: SSI; PinHeader_1x01_P2.54mm_Vertical
TP26: CO0; PinHeader_1x01_P2.54mm_Vertical
TP27: CO1; PinHeader_1x01_P2.54mm_Vertical
TP28: CO2; PinHeader_1x01_P2.54mm_Vertical
TP29: CO3; PinHeader_1x01_P2.54mm_Vertical
TP30: GPSEL1; PinHeader_1x01_P2.54mm_Vertical
TP31: nDI0; PinHeader_1x01_P2.54mm_Vertical
TP32: nDI1; PinHeader_1x01_P2.54mm_Vertical
TP33: nDI2; PinHeader_1x01_P2.54mm_Vertical
TP34: nDI3; PinHeader_1x01_P2.54mm_Vertical
TP35: nDI4; PinHeader_1x01_P2.54mm_Vertical
TP36: nDI5; PinHeader_1x01_P2.54mm_Vertical
TP37: nDI6; PinHeader_1x01_P2.54mm_Vertical
TP38: nDI7; PinHeader_1x01_P2.54mm_Vertical
TP39: DO0; PinHeader_1x01_P2.54mm_Vertical
TP40: DO1; PinHeader_1x01_P2.54mm_Vertical
TP41: DO2; PinHeader_1x01_P2.54mm_Vertical
TP42: DO3; PinHeader_1x01_P2.54mm_Vertical
TP43: DO4; PinHeader_1x01_P2.54mm_Vertical
TP44: DO5; PinHeader_1x01_P2.54mm_Vertical
TP45: DO6; PinHeader_1x01_P2.54mm_Vertical
TP46: DO7; PinHeader_1x01_P2.54mm_Vertical
TP47: nSI0; PinHeader_1x01_P2.54mm_Vertical
TP48: nSI1; PinHeader_1x01_P2.54mm_Vertical
TP49: nSI2; PinHeader_1x01_P2.54mm_Vertical
TP50: nSI3; PinHeader_1x01_P2.54mm_Vertical
TP51: SO0; PinHeader_1x01_P2.54mm_Vertical
TP52: SO1; PinHeader_1x01_P2.54mm_Vertical
TP53: SO2; PinHeader_1x01_P2.54mm_Vertical
TP54: SO3; PinHeader_1x01_P2.54mm_Vertical
TP55: nCFI; PinHeader_1x01_P2.54mm_Vertical
TP56: nSSI; PinHeader_1x01_P2.54mm_Vertical
TP57: +5V; PinHeader_1x01_P2.54mm_Vertical
TP58: +3.3V; PinHeader_1x01_P2.54mm_Vertical
TP59, TP60, TP61, TP62: GND; PinHeader_1x01_P2.54mm_Vertical
U1: XC2C32A; LQFP-44_10x10mm_P0.8mm
U2: STM32F407VETx; LQFP-100_14x14mm_P0.5mm
U3, U5: 74LVC574; TSSOP-20_4.4x6.5mm_P0.65mm
U4, U6, U7, U8: 74LS38; SO-14_5.3x10.2mm_P1.27mm
U9: 7438; SO-14_5.3x10.2mm_P1.27mm
U11: AMS1117-3.3; SOT-223-3_TabPin2
Y1: 8MHz; Crystal_SMD_HC49-SD

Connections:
+5V: C5.1, C6.1, C13.1, C15.1, C18.1, C20.1, C22.1, D4.1 (K), J1.a21, J1.b21, J6.5, R1.1, R2.1, TP57.1, U4.14 (VCC), U6.14 (VCC), U7.14 (VCC), U8.14 (VCC), U9.14 (VCC), U11.3 (VI)
/ACK: TP21.1, U1.32 (A6/GTS3), U4.2
/CFI: TP19.1, U1.34 (A4/GTS1), U9.5
/CFIHOST: TP16.1, U1.38 (A1), U2.9 (PC15)
/CO0: J1.b5, TP26.1, U1.27 (A11)
/CO1: J1.a5, TP27.1, U1.23 (A12)
/CO2: J1.b4, TP28.1, U1.22 (A13)
/CO3: J1.a4, TP29.1, U1.21 (A14)
/CTL: TP5.1, U1.43 (B5/GCK0), U2.82 (PD1)
/DATACLK: TP20.1, U1.33 (A5/GTS0), U2.84 (PD3), U3.11 (Cp), U5.11 (Cp)
/DATA_ENB: TP23.1, U1.30 (A8/GSR), U6.1, U6.4, U6.9, U6.12, U7.1, U7.4, U7.9, U7.12
/DO0: J1.a17, TP39.1, U3.2 (D0)
/DO1: J1.b16, TP40.1, U3.3 (D1)
/DO2: J1.a16, TP41.1, U3.4 (D2)
/DO3: J1.a15, TP42.1, U3.5 (D3)
/DO4: J1.b13, TP43.1, U3.6 (D4)
/DO5: J1.b12, TP44.1, U3.7 (D5)
/DO6: J1.b11, TP45.1, U3.8 (D6)
/DO7: J1.b10, TP46.1, U3.9 (D7)
/GMACK: TP18.1, U1.36 (A3), U2.85 (PD4)
/GPSEL0: TP15.1, U1.20 (A15), U2.55 (PD8)
/GPSEL1: TP30.1, U1.19 (A16), U2.56 (PD9)
/GPSEL2: TP1.1, U1.39 (B1), U2.57 (PD10)
/GPSEL3: TP2.1, U1.40 (B2), U2.58 (PD11)
/GREEN: D1.1 (K), U2.48 (PB11)
/INT: TP17.1, U1.37 (A2), U2.8 (PC14)
/INT1EN: U2.7 (PC13), U9.2
/INT8EN: U2.33 (PC4), U8.13
/INT9EN: U2.34 (PC5), U8.10
/INT10EN: U2.63 (PC6), U8.5
/INT11EN: U2.64 (PC7), U8.2
/INT_ID: TP24.1, U1.29 (A9), U8.1, U8.4, U8.9, U8.12, U9.1
/PRENABLE: TP3.1, U1.41 (B3), U2.81 (PD0)
/RED: D2.1 (K), U2.47 (PB10)
/RST: C3.1, J5.15, R3.2, TP10.1, U1.5 (B10), U2.14 (NRST)
/SCL: J6.4, U2.95 (PB8)
/SDA: J6.3, U2.96 (PB9)
/SDIO_CMD: J3.3 (CMD), R19.2, U2.83 (PD2)
/SDIO_D0: J3.7 (DAT0), R17.2, U2.65 (PC8)
/SDIO_D1: J3.8 (DAT1), R16.2, U2.66 (PC9)
/SDIO_D2: J3.1 (DAT2), R21.2, U2.78 (PC10)
/SDIO_D3: J3.2 (DAT3/CD), R20.2, U2.79 (PC11)
/SDIO_SCK: J3.5 (CLK), R18.2, U2.80 (PC12)
/SO0: J1.b9, TP51.1, U5.2 (D0)
/SO1: J1.b8, TP52.1, U5.3 (D1)
/SO2: J1.b7, TP53.1, U5.4 (D2)
/SO3: J1.b6, TP54.1, U5.5 (D3)
/SSI: TP25.1, U1.28 (A10), U9.10
/STATUS_ENB: TP22.1, U1.31 (A7/GTS2), U4.1, U4.4, U4.9, U4.12
/STM_DO0: U2.97 (PE0), U3.19 (Q0)
/STM_DO1: U2.98 (PE1), U3.18 (Q1)
/STM_DO2: U2.1 (PE2), U3.17 (Q2)
/STM_DO3: U2.2 (PE3), U3.16 (Q3)
/STM_DO4: U2.3 (PE4), U3.15 (Q4)
/STM_DO5: U2.4 (PE5), U3.14 (Q5)
/STM_DO6: U2.5 (PE6), U3.13 (Q6)
/STM_DO7: U2.38 (PE7), U3.12 (Q7)
/STM_SO0: U2.39 (PE8), U5.19 (Q0)
/STM_SO1: U2.40 (PE9), U5.18 (Q1)
/STM_SO2: U2.41 (PE10), U5.17 (Q2)
/STM_SO3: U2.42 (PE11), U5.16 (Q3)
/TCK: J5.9, R7.1, U2.76 (PA14)
/TDI: J5.5, R8.2, U2.77 (PA15)
/TDO: J5.13, R5.2, U2.89 (PB3)
/TMS: J5.7, R6.2, U2.72 (PA13)
/TPSEL0: TP4.1, U1.42 (B4), U2.59 (PD12)
/TPSEL1: TP6.1, U1.44 (B6/GCK1), U2.60 (PD13)
/TPSEL2: TP7.1, U1.1 (B7/GCK2), U2.61 (PD14)
/TPSEL3: TP8.1, U1.2 (B8), U2.62 (PD15)
/TRST: J5.3, R9.2, U2.90 (PB4)
/USB_N: R12.1, U2.70 (PA11)
/USB_P: R11.1, U2.71 (PA12)
/XILINX_TCK: J4.6, U1.11 (TCK)
/XILINX_TDI: J4.10, U1.9 (TDI)
/XILINX_TDO: J4.8, U1.24 (TDO)
/XILINX_TMS: J4.4, U1.10 (TMS)
/YELLOW: D3.1 (K), U2.51 (PB12)
/nCEO: J1.b2, TP9.1, U1.3 (B9)
/nCFI: J1.a2, TP55.1, U9.6
/nDI0: J1.b17, TP31.1, U7.11, U9.3
/nDI1: J1.a14, TP32.1, U7.8
/nDI2: J1.b14, TP33.1, U7.6
/nDI3: J1.b15, TP34.1, U7.3
/nDI4: J1.a13, TP35.1, U6.11
/nDI5: J1.a12, TP36.1, U6.8
/nDI6: J1.a11, TP37.1, U6.6
/nDI7: J1.a10, TP38.1, U6.3, U8.11
/nGP: TP13.1, U1.13 (B14), U5.7 (D5)
/nPR: TP14.1, U1.14 (B15), U5.6 (D4)
/nSI0: J1.a9, TP47.1, U4.11, U8.8
/nSI1: J1.a8, TP48.1, U4.8, U8.6
/nSI2: J1.a7, TP49.1, U4.6, U8.3
/nSI3: J1.a6, TP50.1, U4.3
/nSIH: J1.a3, TP11.1, U1.6 (B11)
/nSSI: J1.b3, TP56.1, U9.8
/nSTM_DI0: U2.23 (PA0), U6.10
/nSTM_DI1: U2.24 (PA1), U6.2
/nSTM_DI2: U2.25 (PA2), U6.5
/nSTM_DI3: U2.26 (PA3), U6.13
/nSTM_DI4: U2.29 (PA4), U7.2
/nSTM_DI5: U2.30 (PA5), U7.5
/nSTM_DI6: U2.31 (PA6), U7.10
/nSTM_DI7: U2.32 (PA7), U7.13
/nSTM_GP: U2.44 (PE13), U5.14 (Q5)
/nSTM_PR: U2.43 (PE12), U5.15 (Q4)
/nSTM_SI1: U2.16 (PC1), U4.5
/nSTM_SI2: U2.17 (PC2), U4.10
/nSTM_SI3: U2.18 (PC3), U4.13
/nSTM_TP: U2.45 (PE14), U5.13 (Q6)
/nTP: TP12.1, U1.12 (B13), U5.8 (D6)
GND: C1.2, C2.2, C3.2, C4.2, C5.2, C6.2, C7.2, C8.2, C9.2, C10.2, C11.2, C12.2, C13.2, C14.2, C15.2, C16.2, C17.2, C18.2, C19.2, C20.2, C21.2, C22.2, C23.2, C24.2, C25.2, C26.2, C27.2, C28.2, J1.a22, J1.b1, J1.b22, J2.5 (GND), J2.6 (Shield), J3.6 (VSS), J3.11 (SHIELD), J4.1, J4.3, J4.5, J4.7, J4.9, J4.11, J4.13, J5.4, J5.6, J5.8, J5.10, J5.12, J5.14, J5.16, J5.18, J5.20, J6.2, R4.2, R7.2, TP59.1, TP60.1, TP61.1, TP62.1, U1.4 (GND), U1.17 (GND), U1.25 (GND), U2.10 (VSS), U2.20 (VSSA), U2.27 (VSS), U2.37 (PB2), U2.74 (VSS), U2.99 (VSS), U3.1 (OE), U3.10 (GND), U4.7 (GND), U5.1 (OE), U5.10 (GND), U6.7 (GND), U7.7 (GND), U8.7 (GND), U9.7 (GND), U11.1 (GND)
unnamed: C4.1, U2.73 (VCAP_2)
unnamed: C9.1, U2.49 (VCAP_1)
unnamed: C10.1, R10.2, U2.12 (PH0), Y1.1
unnamed: C11.1, R10.1, U2.13 (PH1), Y1.2
unnamed: D1.2 (A), R13.1
unnamed: D2.2 (A), R14.1
unnamed: D3.2 (A), R15.1
unnamed: D4.2 (A), J2.1 (VBUS)
unnamed: J2.2 (D-), R12.2
unnamed: J2.3 (D+), R11.2
unnamed: JP1.2, R4.1, U2.94 (BOOT0)
unnamed: R1.2, U9.4
unnamed: R2.2, U9.9

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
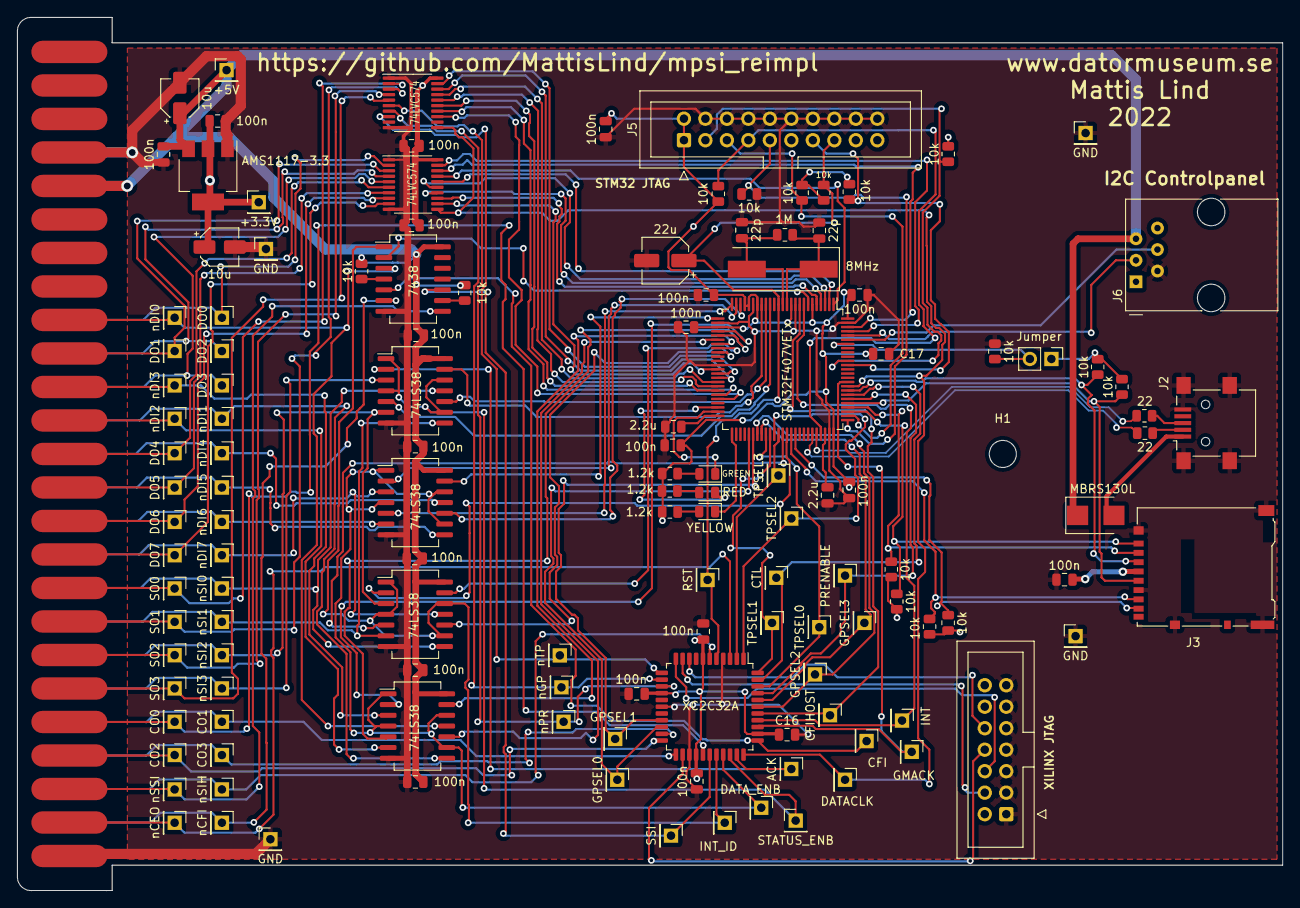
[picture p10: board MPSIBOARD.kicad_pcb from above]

Board: 2 copper layers, 149.5 x 103.2 mm, 134 parts (0 on the bottom side), 125 nets.

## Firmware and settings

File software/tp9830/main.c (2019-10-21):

//********************************************************************************
//*
//*			9830/65 Tape Controller Program
//*
//* 2013 Jul   : V1
//* 2013 Jul 12: V2 updated for nEXCP bit added to adapter
//* 2013 Jul 13: V3 updated CTL, EXEC, AUTOR
//* 2013 Nov 02: V4 interface/command split, buffer mod commands, pbf
//* 2014 Feb:	 V5 converted to C for use with MPSI
//*
//********************************************************************************
#include <stdlib.h>
#include <string.h>
#include <stdio.h>
#include <time.h>
#include "../util/util.h"
#include "../util/cp.h"
#include "t98.h"
#include "tpf.h"

extern void			LoadDBImage();
extern void			habDisplay();

extern char*			HelpSrc;


//--------------------------------------------------------------------------------
// Command Table


#define CMD_OPEN		1
#define CMD_SAVE		2
#define CMD_BDISPLAY		3
#define CMD_LIST		4
#define CMD_MARK		5
#define CMD_LOAD		6
#define CMD_STORE		17
#define CMD_CLEANUP		7
#define CMD_BTRUNCATE		8
#define CMD_BZEROES		9
#define CMD_BSET		10

#define CMD_RIMAGE		11
#define CMD_WIMAGE		12
#define CMD_STATUS		13
#define CMD_REWIND		14
#define CMD_STOP		15
#define CMD_DRIVE		16


static CP_TBL			cmdTbl[] =
 {	{ "o*pen",	"<fname> [dbb]",		"read tape image file into buffer",				CMD_OPEN	},
	{ "sa*ve",	"<fname>",			"save image buffer to file",					CMD_SAVE	},
	{ "b*uf",	"[<addr> [<count>]]",		"display buffer",						CMD_BDISPLAY	},
	{ "l*ist",	"[<fnum>]",			"list tape files in the buffer",				CMD_LIST	},
	{ "mark",	"[<numFiles> [<fSpace> [<fNum>]]]",	"mark empty tape files in buffer",			CMD_MARK	},
	{ "load",	"<fname> [<fnum>]",		"load a file into a tape file in image buffer",			CMD_LOAD	},
	{ "store",	"<fnum> <fname>",		"store a tape file from the image buffer in file <fname>",	CMD_STORE	},
	{ "clean*up",	"[z*eroes] [bof*s] [seq*uence] [ch*ecksums] [pad*ding] [tr*uncate]", "cleanup the image",	CMD_CLEANUP	},
	{ "tr*uncate",	"[<length>]",			"truncate buffer",						CMD_BTRUNCATE	},
	{ "z*eroes",	"<addr> <count>",		"zero range in buffer",						CMD_BZEROES	},
	{ "bs*et", 	"<addr> <byte> [<byte>]",	"change bytes in buffer",					CMD_BSET	},

	{ "rim*age",	"[full] [fast] [<maxBytes>]",	"read tape image into buffer",					CMD_RIMAGE	},
	{ "wimage",	"",				"write image buffer to tape",					CMD_WIMAGE	},
	{ "sta*tus",	"",				"display drive status",						CMD_STATUS	},
	{ "rew*ind",	"",				"rewind the drive",						CMD_REWIND	},
	{ "sto*p",	"",				"stop the drive",						CMD_STOP	},
	{ "dr*ive",	"rfn|rfh|rrn|rrh|wfn|stop|cont [control]", "command to drive",					CMD_DRIVE	},
	{ NULL,		NULL,				NULL,								0		}
 };


//* END Command Table
//********************************************************************************
//* Interactive mode

void
Interactive()
 {
	CP*			cp = Cp_Open(HelpSrc);
	T98*			tp = T98_Open();
	BF*			bf = bf_alloc( 100000 );
	FILE*			fd;
	int			cmd;
	int			dbi, n, i;
	int			fNum, fSpace, fbi, bi;
	int			addr, byte1, byte2;
	int			rdCmd, timeoutSec, maxBytes;
	int			doZeroes, doBOFs, doSeq, doSums, doPad, doTrunc;
	int			sr, endTm;

	while( (cmd=Cp_Cmd(cp,"TP9830> ",cmdTbl)) ) switch( cmd )			// command loop
	 {	case CMD_OPEN:								// CMD: read image from file
			fd  = Cp_File( cp, "r" );
			dbi = Cp_Kw( cp, "dbb" );
			if( !Cp_Check(cp) )
			 {	if( fd ) fclose( fd );
				continue;
			 }

			bf->l = 0;								// empty the buffer before loading

			if( dbi )
				LoadDBImage( bf, fd );
			else
				XNS_Decode( bf, fd );

			fclose( fd );
			printf( "  buffer length = %d\n", bf->l );
			continue;

		case CMD_SAVE:								// CMD: write image to file
			fd = Cp_File( cp, "w" );
			if( !Cp_Check(cp) )
			 {	if( fd ) fclose( fd );
				continue;
			 }

			fprintf( fd, "HP9830 Tape Image\n" );
			XNS_Encode( fd, bf );

			fclose( fd );
			continue;

		case CMD_BDISPLAY:							// CMD: display image buffer
			addr = Cp_Num( cp, 0 );
			n    = Cp_Num( cp, bf->l );
			if( !Cp_Check(cp) )
				continue;

			printf( "  buffer length = %d\n", bf->l );
			habDisplay( bf, addr, n );
			continue;

		case CMD_LIST:								// CMD: analyse the buffer contents
			fNum = Cp_Num( cp, -1 );						// display the specified file
			if( !Cp_Check(cp) )
				continue;

			if( fNum < 0 )
				Tpf_AnaImage( bf );						// list files in image
			else
			 {	fbi = Tpf_FindFile( bf, fNum );					// display file contents
				if( fbi < 0 )
				 {	printf( "  -- file fNum not found in image\n" );
					continue;
				 }
				Tpf_AnaFile( bf, fbi );
			 }
			continue;

		case CMD_MARK:								// CMD: mark empty files
			n	= Cp_Num( cp, -1 );
			fSpace	= Cp_Num( cp, 1000 );
			fNum	= Cp_Num( cp, -1 );
			if( !Cp_Check(cp) )
				continue;

			Tpf_Mark( bf, n, fSpace, fNum );
			continue;

		case CMD_LOAD:								// CMD: read file into a tape file in buffer
			fd    = Cp_File( cp, "r" );
			fNum  = Cp_Num( cp, -1 );						// -1 implies append (overwrite last file)
			if( !Cp_Check(cp) )
			 {	if( fd ) fclose( fd );
				continue;
			 }

			fbi = Tpf_LoadFile( bf, fNum, fd );
			fclose( fd );
			if( fbi < 0 )
				continue;

			printf( "  words = %d\n", Tpf_getWord(bf,fbi,TPF_OF_LEN) );
			continue;

		case CMD_STORE:								// CMD: store tape file from buffer in external file
			fNum  = Cp_Num( cp, -1 );						// fNum must be specified
			if( fNum < 0 ) cp->err = CP_BADARG;
			fd    = Cp_File( cp, "w" );
			if( !Cp_Check(cp) )
			 {	if( fd ) fclose( fd );
				continue;
			 }

			fbi = Tpf_FindFile( bf, fNum );
			if( fbi < 0 )
			 {	printf( "  -- file fNum not found in image\n" );
				fclose( fd );
				continue;
			 }

			n = TPF_HDR_LEN+1 + Tpf_getWord(bf,fbi+TPF_OF_LEN)+1;			// number of words to extract
			i = 0;
			bi = fbi + 1;								// skip BOF
			while( i < n )
			 {	fprintf( fd, "%X~", Tpf_getWord(bf,bi) );			// write as XNS
				bi += 2;
				if( (++i % 16) == 0 ) fprintf( fd, "\n" );
			 }
			fprintf( fd, "!\n" );
			fclose( fd );

			printf( "  words = %d\n", n );
			continue;


		case CMD_CLEANUP:							// CMD: cleanup aspects of the image
			doZeroes = doBOFs = doSeq = doSums = doPad = doTrunc = FALSE;
			if( Cp_Kw(cp,"z*eros")		) doZeroes	= TRUE;
			if( Cp_Kw(cp,"bof*s")		) doBOFs	= TRUE;
			if( Cp_Kw(cp,"seq*uence")	) doSeq		= TRUE;
			if( Cp_Kw(cp,"ch*ecksums")	) doSums	= TRUE;
			if( Cp_Kw(cp,"pad*ding")	) doPad		= TRUE;
			if( Cp_Kw(cp,"tr*uncate")	) doTrunc	= TRUE;
			if( !Cp_Check(cp) )
				continue;

			if( !doZeroes && !doBOFs && !doSeq && !doSums && !doPad && !doTrunc )	// if no options specified do everything
				doZeroes = doBOFs = doSeq = doSums = doPad = doTrunc = TRUE;

			Tpf_Cleanup( bf, doZeroes, doBOFs, doSeq, doSums, doPad, doTrunc );
			continue;

		case CMD_BTRUNCATE:							// CMD: truncate the buffer to specified length
			n = Cp_Num( cp, 0 );
			if( !Cp_Check(cp) )
				continue;

			bf->l = min( max(n,0), bf->size );

			printf( "  buffer len = %d\n", bf->l );
			continue;

		case CMD_BZEROES:							// CMD: append zeroes to buffer
			addr = Cp_Num( cp, -1 );
			n    = Cp_Num( cp, -1 );
			if( addr<0 || n<0 ) cp->err = CP_BADARG;
			if( !Cp_Check(cp) )
				continue;

			bf_fill( bf, addr, n, 0 );
			continue;

		case CMD_BSET:								// CMD: append empty files to buffer
			addr  = Cp_Num( cp, -1 );
			byte1 = Cp_Num( cp, -1 );
			byte2 = Cp_Num( cp, -1 );
			if( addr<0 || byte1<0 ) cp->err = CP_BADARG;
			if( !Cp_Check(cp) )
				continue;

			bf_put( bf, addr, byte1 );
			if( byte2 >= 0 ) bf_put( bf, addr+1, byte2 );
			continue;

		//---------------------------------------
		// Tape Drive Control Commands 

		case CMD_RIMAGE:							// CMD: read tape image into buffer
			rdCmd	   = Cp_Kw( cp, "fast" ) ? T98_CMD_RFH : T98_CMD_RFN;		// high or normal speed
			timeoutSec = Cp_Kw( cp, "full" ) ? 10*60 : 5;				// long timeout for full image
			maxBytes   = Cp_Num( cp, 90000 );
			if( !Cp_Check(cp) )
				continue;

			bf_resize( bf, maxBytes );

			sr = T98_Read( tp, rdCmd, bf, timeoutSec );
			T98_printStat( sr );
			printf( "  bytes read = %d\n", bf->l );
			continue;

		case CMD_WIMAGE:							// CMD: write image buffer to tape
			if( !Cp_Check(cp) )
				continue;

			sr = T98_Write( tp, bf );
			T98_printStat( sr );
			continue;

		case CMD_STATUS:							// CMD: just get and display the drive status
			if( !Cp_Check(cp) )
				continue;

			sr = T98_Cmd( tp, T98_CMD_CONT );
			T98_printStat( sr );
			continue;

		case CMD_STOP:								// CMD: stop command to drive
			if( !Cp_Check(cp) )
				continue;

			sr = T98_Cmd( tp, T98_CMD_STOP );
			T98_printStat( sr );
			continue;

		case CMD_REWIND:							// CMD: rewind command to drive
			if( !Cp_Check(cp) )
				continue;

			endTm = clock() + 3 * CLOCKS_PER_SEC;
			repeat
			 {	sr = T98_Cmd( tp, T98_CMD_RRH );				// if the rewind began while in leader,
				if( !T98_leader(sr) )						// loop till out of leader
					break;
				if( clock() > endTm )						// if not out of leader in time then already rewound
				 {	sr = T98_Cmd( tp, T98_CMD_STOP );
					break;
				 }
			 }
			T98_printStat( sr );
			continue;

		case CMD_DRIVE:								// CMD: other commands to drive
			cmd = -1;
			if( Cp_Kw(cp,"rfn") )		 cmd = T98_CMD_RFN;
			else if( Cp_Kw(cp,"rfh") )	 cmd = T98_CMD_RFH;
			else if( Cp_Kw(cp,"rrn") )	 cmd = T98_CMD_RRN;
			else if( Cp_Kw(cp,"rrh") )	 cmd = T98_CMD_RRH;
			else if( Cp_Kw(cp,"wfn") )	 cmd = T98_CMD_WFN;
			else if( Cp_Kw(cp,"stop") )	 cmd = T98_CMD_STOP;
			else if( Cp_Kw(cp,"cont*inue") ) cmd = T98_CMD_CONT;
			if( cmd < 0 ) cp->err = CP_BADARG;
			if( Cp_Kw( cp, "control" ) ) cmd |= T98_CMD_CTLBYTE;			// add control bit if requested
			if( !Cp_Check(cp) )
				continue;

			sr = T98_Cmd( tp, cmd );
			T98_printStat( sr );
			continue;
	 }

	bf_free( bf );
	T98_Close( tp );
	Cp_Close( cp );
 }

//* END Interactive
//********************************************************************************
//* Main

int
main( argc, argv )
	int			argc;
	char**			argv;
 {
	BF*			bf;
	FILE*			fd;
	int			i;

	//------------------------------
	// Command line configuration

	for( i=1; i<argc; ++i )
		if( strcmp(argv[i],"-u") == 0 )
		 {	printf( "  -- Use: %s [-u] [<tapeFile>... > <tapeImageFile>]\n", argv[0] );
			exit( -1 );
		 }

	//------------------------------
	// Execution modes

	if( argc == 1 )						// Interactive Mode
	 {	Interactive();
	 }
	else							// Command Line Mode - append files into an mage
	 {	bf = bf_alloc( 0 );
		
		for( i=1; i<argc; ++i )
		 {	fd = fopen( argv[i], "r" );
			if( !fd )
			 {	printf( "  -- Error opening file %s\n", argv[i] );
				exit( -1 );
			 }
			Tpf_LoadFile( bf, -1, fd );		// append file to image
			fclose( fd );
		 }

		Tpf_Cleanup( bf, FALSE, FALSE, FALSE, FALSE, TRUE, TRUE );	// add padding

		fprintf( fd, "HP9830 Tape Image\n" );		// write the image
		XNS_Encode( stdout, bf );

		bf_free( bf );
	 }

	//------------------------------
	// Termination

	m_check();
	return( 0 );
}


//** END Main
//********************************************************************************

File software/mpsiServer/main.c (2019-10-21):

//********************************************************************************
//*	 	9830 MPSI Server
//* 
//* Server program for use with the MPSI I/O Interface.
//* This program implements emulation of 4 devices:
//*	- a 9866 printer,
//*	- a secondary printer,
//*	- a paper tape reader,
//*	- a 9865 cassette tape drive.
//*
//* Use: mpsi [-u] [-v] [-k] [-w] [-p <paperTapeFile>] [-t <tapeImagefile>] [-d <tapeDelay>]
//*	-u			: display use message and exit
//*	-v			: verbose, display tape log at termination
//*	-k			: tape cleanup at startup to unhang the 9830
//*	-w			: writing permitted on tape image file
//*	-p <paperTapeFile>	: source text file for paper tape reader emulator
//*	-t <tapeImagefile>	: cassette tape image file in T98 XNS format for 9865 emulator
//*	-c <clockWidth>		: sets the clock-pulse width for the MPSI I/O transfers
//*				  see MPSI_Transfer() in mpsi.c
//*	-d <tapeDelay>		: see tape server code
//*
//* 2014 Jan: V1 /bh
//*
//********************************************************************************
#include <stdlib.h>
#include <string.h>
#include <signal.h>
#include <stdio.h>
#include "../util/util.h"
#include "../util/attn.h"
#include "mpsi.h" 

typedef void			TP;
extern TP*			TP_Open();
extern void			TP_Close();
extern void			TP_Cleanup();
extern void			TP_Op();

typedef void			PR;
extern PR*			PR_Open();
extern void			PR_Close();
extern void			PR_Op();

typedef void			PTR;
extern PTR*			PTR_Open();
extern void			PTR_Close();
extern void			PTR_Op();

//--------------------------------------------------------------------------------

static void
Fcheck( fname )
	char*			fname;
{
	FILE*			fd;

	if( fname )
	 {	fd = fopen( fname, "r" );
		if( !fd )
		 {	printf( "  -- Error opening file %s\n", fname );
			exit( -1 );
		 }
		fclose( fd );
	 }
 }


//* END Private
//********************************************************************************
//* Main execution

int				Verbose;


int
main( argc, argv )
	int			argc;
	char**			argv;
 {
	MPSI*			mpsi;
	int			clockWidth;
	char*			magTpFname;
	int			magTpWritePermit, magTpCleanup, magTpDelay;
	TP*			magTp;
	PR*			printer;
	PTR*			paperTp;
	char*			paperTpFname;
	int			req, i;

	Attn_Init();

	//------------------------------
	// Command line configuration

	Verbose			= FALSE;
	clockWidth		= -1;
	paperTpFname		= NULL;
	magTpFname		= NULL;
	magTpWritePermit	= FALSE;
	magTpCleanup		= FALSE;
	magTpDelay		= -1;

	for( i=1; i<argc; ++i )
		if( strcmp(argv[i],"-p") == 0 )
		 {	if( ++i == argc ) goto useFail;
			paperTpFname = argv[i];
		 }
		else if( strcmp(argv[i],"-t") == 0 )
		 {	if( ++i == argc ) goto useFail;
			magTpFname = argv[i];
		 }
		else if( strcmp(argv[i],"-d") == 0 )
		 {	if( ++i == argc ) goto useFail;
			if( sscanf( argv[i], "%d", &magTpDelay ) != 1 ) goto useFail;
		 }
		else if( strcmp(argv[i],"-c") == 0 )
		 {	if( ++i == argc ) goto useFail;
			if( sscanf( argv[i], "%d", &clockWidth ) != 1 ) goto useFail;
		 }
		else if( strcmp(argv[i],"-w") == 0 )
			magTpWritePermit = TRUE;
		else if( strcmp(argv[i],"-k") == 0 )
			magTpCleanup = TRUE;
		else if( strcmp(argv[i],"-v") == 0 )
			Verbose = TRUE;
		else
		 {useFail:
			printf( "  -- Use: %s [-u] [-v] [-k] [-w] [-p <paperTapeFile>] [-t <tapeImagefile>] [-d <tapeDelay>] [-c <clockWidth>]\n", argv[0] );
			exit( -1 );
		 }

	Fcheck( paperTpFname );
	Fcheck( magTpFname );

	//------------------------------
	// Initialisation

	printf( "  ** 9830 MPSI Server: start, ctl-C to terminate\n" );

	mpsi = MPSI_Open( clockWidth );

	magTp   = TP_Open( mpsi, magTpFname, magTpWritePermit, magTpCleanup, magTpDelay );
	printer = PR_Open( mpsi );
	paperTp = PTR_Open( mpsi, paperTpFname );

	//------------------------------
	// Activity loop

	repeat
	 {	req = MPSI_WaitForRequest( mpsi );				// wait for activity from 9830
		if( Attn )
		 {	printf( "  -- MPSI Server: terminated by user\n" );
			break;
		 }

		switch( req & MPSI_IR_DEVMASK )					// distribute to appropriate device server
		 {	case MPSI_IR_TAPE:
				TP_Op(  magTp,   req );
				break;

			case MPSI_IR_PRINTER:
				PR_Op(  printer, req );
				break;

			case MPSI_IR_GENPURP:
				PTR_Op( paperTp, req );
				break;

			default:
				printf( "  -- MPSI Server: request with bad device spec (req:%04X)\n", req );
				break;
		 }
	 }

	//------------------------------
	// Termination

	PTR_Close( paperTp );
	PR_Close( printer );
	TP_Close( magTp );
	MPSI_Close( mpsi );

	m_check();
	return( 0 );
 }


//* EOF
//********************************************************************************

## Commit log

2021-04-05 Added schematic.
    [MPSIBOARD.kicad_pcb, MPSIBOARD.sch]
2021-04-05 Add schematic
2021-04-25 Some updates of schematic.
    [MPSIBOARD.sch]
2023-01-06 A layout done.
    [MPSIBOARD-B_Cu.gbr, MPSIBOARD-B_Mask.gbr, MPSIBOARD-B_Paste.gbr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]
2026-10-09 Simplifying the VHDL.
    [MPSI_REV2.kicad_pcb, MPSI_REV2.kicad_sch, mcu.kicad_sch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]
